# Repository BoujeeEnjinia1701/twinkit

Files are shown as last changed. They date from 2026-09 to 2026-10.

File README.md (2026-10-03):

# TwinKit

     

**Area:** Digital Twins · **TRL:** 3 of 9 (proof of concept on paper) · **Value-engineering target:** about $300 USD · **Difficulty:** 3 of 5

An open digital twin starter kit: a small edge gateway that collects readings from lab sensors (FieldNode and others), plus software that ties live data to each project's build123d model so it can be seen and compared with the design calculations.

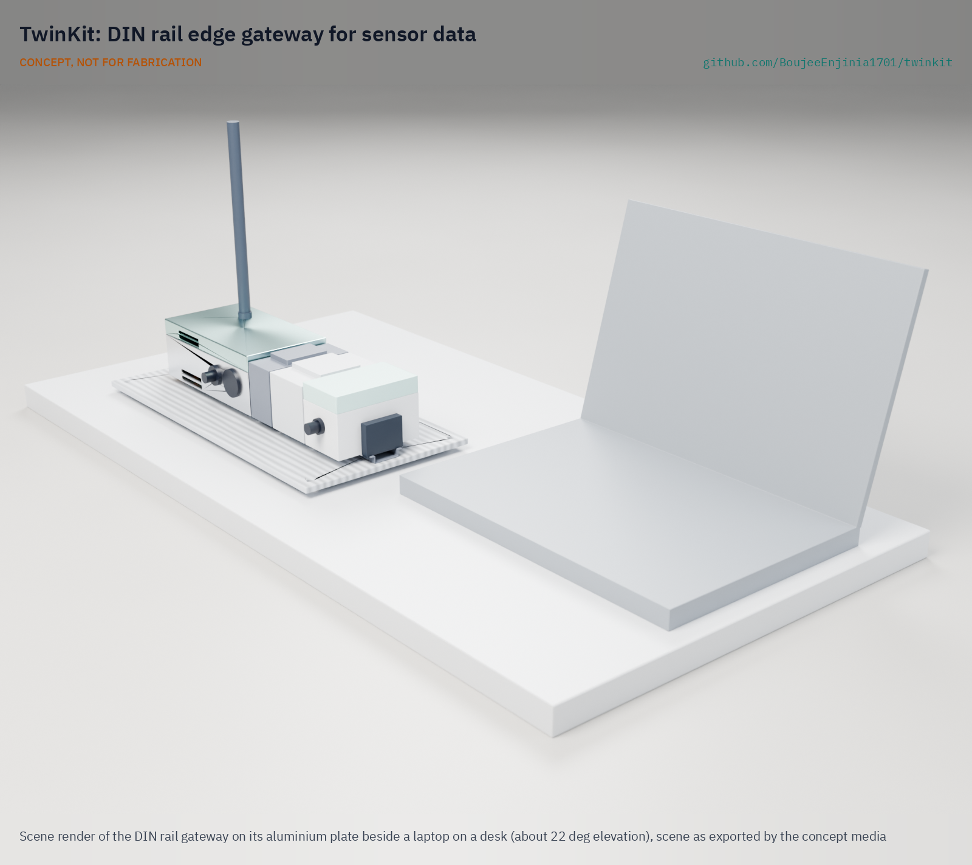
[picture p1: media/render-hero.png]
TwinKit: open digital twin starter kit and edge gateway, photoreal render


[Interactive 3D model](media/viewer.html) · [Concept blueprint (PDF)](media/concept-blueprint.pdf) · [General arrangement (PDF)](cad/drawings/TWK-DWG-001.pdf) · [Sizing calculations](docs/04-calcs/01-sizing.md) · [Prototype build plan](docs/05-build-plan.md) · [Design decisions](docs/06-design-decisions.md) · [Review note](docs/REVIEW.md)

## Concept rationale

Every lab project already has a parametric model and calculated targets. Linking those to live readings closes the loop between design and reality at low cost: instead of alarming on fixed limits, the twin shows where a device departs from what its own calculation predicted, and on which part of the model.

The kit is open and garage-buildable because the pieces already exist as off-the-shelf modules and open-source software. What is missing is the thin mapping layer between sensor channels, model parts and calculations, and a small offline gateway that a small team can assemble on a DIN rail, inspect and adapt.

## Burning platform

Small operators find faults late because they lack the monitoring that large operators take for granted. Water utilities alone lose an estimated 126 billion m³ of treated water a year, worth nearly $40 billion ([World Bank](https://blogs.worldbank.org/en/ppps/what-do-private-companies-look-performance-based-non-revenue-water-project)), and about one in four handpumps in sub-Saharan Africa is out of service at any time ([Foster et al., 2019, via IRC](https://www.ircwash.org/resources/functionality-handpump-water-supplies-review-data-sub-saharan-africa-and-asia-pacific)).

Digital twin platforms are priced for large firms, yet small and medium enterprises make up about 90 % of businesses and more than half of employment worldwide ([World Bank](https://www.worldbank.org/en/topic/smefinance)). An open kit that runs on one small gateway puts the same early-warning idea within their reach.

## Where it could be used

### By industry

| Industry | Use |
| --- | --- |
| Water supply | Compare tank levels, pump run time and flow with the expected demand curve to catch leaks and pump faults early |
| Off-grid energy | Track battery state of charge and solar yield against the design power budget in mini-grids and solar kits |
| Small manufacturing | Watch machine temperature, vibration or energy use against the process calculation |
| Cold chain and storage | Compare cold room or grain store temperatures with the thermal model |
| Education and research | Teach model-based design with a twin students can build and inspect |
| Municipal services | Gateway and data layer for street sensors through CityTwin |

### By country or region

| Country or region | Why it matters there |
| --- | --- |
| Kenya | Water utilities report a national average non-revenue water of 44 % ([WASREB, 2025](https://wasreb.go.ke/wp-content/uploads/2025/06/IMPACT-REPORT-17.pdf)); low-cost monitoring helps find losses |
| Sub-Saharan Africa | About one in four handpumps is non-functional at any time ([Foster et al., 2019](https://www.ircwash.org/resources/functionality-handpump-water-supplies-review-data-sub-saharan-africa-and-asia-pacific)); remote twins can flag failures sooner |
| India | About 63.4 million unincorporated micro, small and medium enterprises in the 2015 to 2016 survey ([PIB, Ministry of MSME](https://www.pib.gov.in/Pressreleaseshare.aspx?PRID=1555596)), most without access to enterprise monitoring tools |
| Brazil | About 37.8 % of treated water was lost in distribution in 2022 ([Instituto Trata Brasil](https://tratabrasil.org.br/wp-content/uploads/2024/06/Release-Perdas-de-Agua-2024.pdf)) |
| European Union | 99 % of the 32.3 million enterprises are micro or small ([Eurostat, 2024](https://ec.europa.eu/eurostat/web/products-eurostat-news/w/ddn-20241025-1)); an open kit suits firms too small for vendor twin platforms |
| Singapore | [Virtual Singapore](https://oecd-opsi.org/innovations/virtual-twin-singapore/) shows the value of a national twin; TwinKit offers a small, open counterpart for campuses, buildings and schools |

## What sparked the idea

The idea traces back to Apollo 13 in April 1970. After an oxygen tank failed, the procedures to bring the crippled command module back to life were worked out on the ground against a model of the spacecraft: NASA's history notes that Ken Mattingly "had spent hours in the CM simulator finalizing the procedures" before the crew ran them ([NASA, 2020](https://www.nasa.gov/history/50-years-ago-apollo-13-crew-returns-safely-to-earth/)). That pairing of a model with the state of the real system, later formalized as the digital twin ([Grieves and Vickers, 2017](https://link.springer.com/chapter/10.1007/978-3-319-38756-7_4)), then needed a room of simulators and a mission control center. TwinKit asks whether the same loop of model, live readings and comparison can run on one DIN rail gateway for a small device, using the model and calculations each project already has.

## Problem

Digital twins are sold as enterprise software, out of reach for small builders and cities, yet the idea is simple: a model, live data and a comparison between them.

## Concept

A DIN rail edge gateway (single-board computer, 8-channel LoRaWAN concentrator, 12 V input and LiFePO4 backup) runs open-source software that receives readings from FieldNode and other sensors, stores a year of data offline, and shows each reading on the project's build123d model next to the value its design calculation predicted. TRL 3 calculations ([TWK-CAL-001](docs/04-calcs/01-sizing.md)): 50 nodes at 5 min with 0.21 % uplink loss using adaptive data rate (target under 1 %), 6.4 W average, 2.4 h of backup, 4.7 GB of data a year, and an estimated USD 334 in parts against a USD 300 value-engineering target. At 40 °C ambient the processor stays about 16 K below its assumed throttle point at normal load; heavy database jobs are scheduled for cool hours. Fourteen of sixteen requirements are met on paper; setup time needs a timed trial, and cost is reported against its target.

Full design precis: [docs/02-concept.md](docs/02-concept.md)

## Key components

- Single-board computer (4 GB) in a vented 9-module DIN rail enclosure
- 8-channel LoRaWAN concentrator HAT and antenna (Wi-Fi and Ethernet built in; cellular optional)
- 12 V DC input (9 to 30 V) with 3.15 A time-delay fuse, DC-DC converter, DIN UPS module with buck-boost charger, and a 12.8 V LiFePO4 backup pack in its own DIN battery box
- Open-source network server, MQTT broker, TimescaleDB and dashboard
- TwinKit twin service and model-to-data mapping schema
- Example twin of FieldNode's battery and solar charge

The priced bill of materials is in [bom/bom.csv](bom/bom.csv). The parametric model is [cad/src/model.py](cad/src/model.py), with STEP and STL exports in `cad/step/` and `cad/stl/`.

## Building the prototype

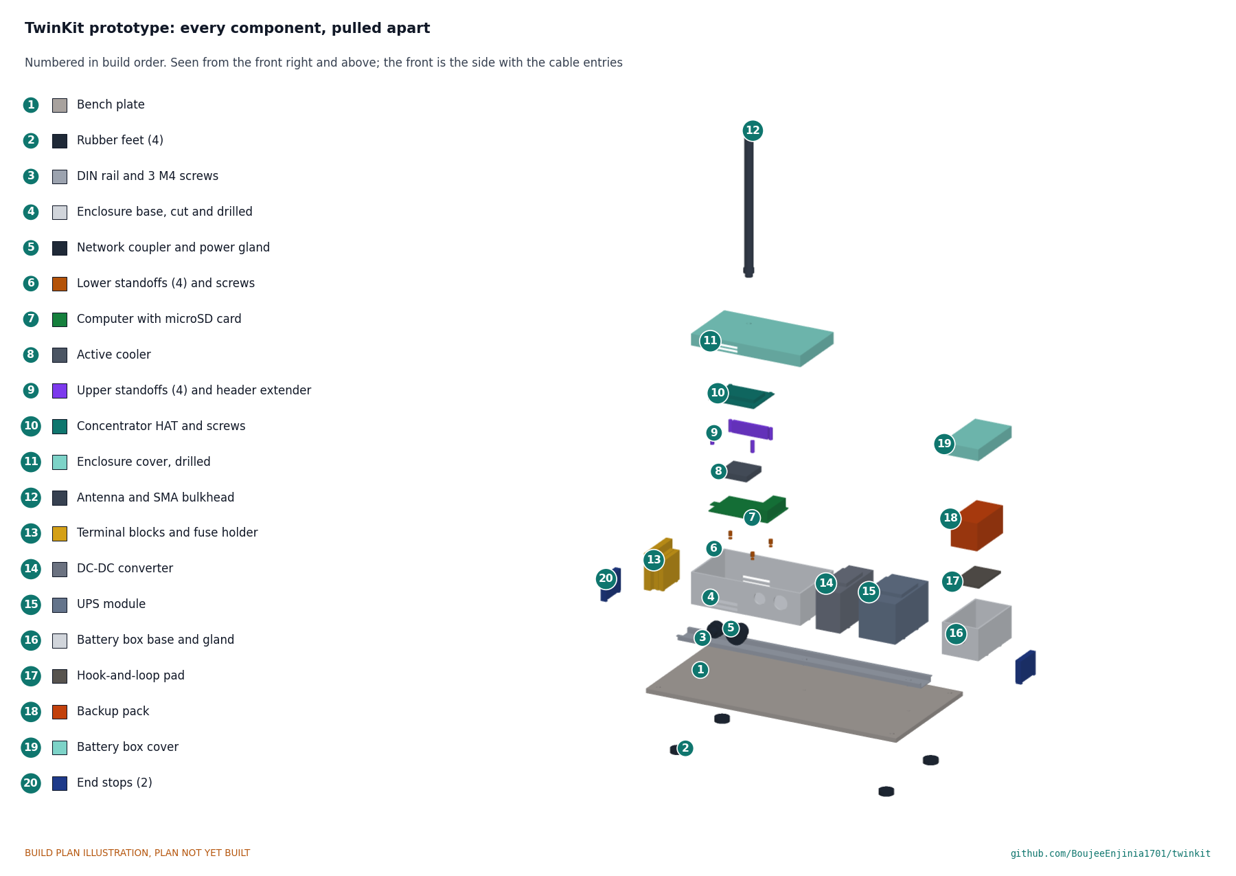
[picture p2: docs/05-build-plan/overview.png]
TwinKit prototype: every component pulled apart and numbered in build order


The [prototype build plan](docs/05-build-plan.md) (TWK-BLD-001) shows, in pictures, how to make each of the twenty components and put them together in seventeen steps; nothing has been built yet. The worked parts are an aluminium bench plate, a cut DIN rail, and three bought DIN enclosures that are cut or drilled; everything else is bought DIN modules, boards and fittings, wired at their screw terminals. Writing the plan made the design buildable: the backup pack moved into its own battery box, the vents moved to the long walls, and standoffs, an antenna bulkhead, cable entries, rail screws and end stops were added (TWK-DDR-003, open for Amish's review). Every picture is drawn from the model, and the model checks that each part touches what it should and clears what it should not.

## Safety

> Low voltage only (12 V DC); use a certified mains adapter. The backup pack is a LiFePO4 battery: use a pack with a built-in BMS and fuse, charge it only through the UPS module and never leave a first build charging unattended. Secure the gateway: change default credentials and keep it off public networks until it is hardened. TwinKit is a monitoring aid, not a safety system.

## Repository layout

| Folder | Contents |
| --- | --- |
| `docs/` | Problem, concept, requirements, calculations and design decisions |
| `cad/src/` | build123d Python source, the source of truth for all geometry |
| `cad/step/`, `cad/stl/` | Exported models for FreeCAD, other CAD tools and printing |
| `cad/drawings/` | 2D sketches and dimensioned drawings |
| `bom/` | Bill of materials |
| `electronics/` | KiCad schematics and PCB layouts |
| `firmware/` | Microcontroller code |
| `media/` | Renders, perspectives and photos |
| `build-log/` | Dated prototyping notes |

## Documentation

Controlled documents follow the portfolio [documentation standard](.kit/STANDARDS.md). Each carries a document ID (TWK-PRC-001 for the precis), a version and a revision history. Branded PDFs are built with `python .kit/render.py` and attached to GitHub Releases when a document is tagged, for example `TWK-PRC-001/v1.0`.

## Credits

Designed by Amish Chadha. See [CONTRIBUTORS.md](CONTRIBUTORS.md) for roles. To cite this design, use [CITATION.cff](CITATION.cff) (GitHub shows it as "Cite this repository").

AI assistance (Claude) was used to accelerate concept renders, prototype documentation and first-pass sizing calculations. Design direction and all decisions are Amish Chadha's, recorded in this repository's decision records (`docs/decisions/`).

## Licenses

- **Hardware** (CAD, drawings, BOM, electronics): [CERN-OHL-S v2](LICENSE)
- **Software** (firmware, scripts, notebooks): [MIT](LICENSE-SOFTWARE)

A project of the [Design Molecule](https://designmolecule.com) lab.

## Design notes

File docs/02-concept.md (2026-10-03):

---
doc_id: TWK-PRC-001
title: TwinKit design precis
project: TwinKit
doc_type: Design precis
version: "0.6"
status: Draft
date: '2026-10-02'
author: Amish Chadha
license: CERN-OHL-S-2.0
revisions:
- version: "0.1"
  date: '2026-09-25'
  author: Amish Chadha
  change: Initial scaffold
- version: "0.2"
  date: '2026-09-25'
  author: Amish Chadha
  change: Populate to TRL 2 (architecture, first-order numbers, safety, media)
- version: "0.3"
  date: '2026-09-25'
  author: Amish Chadha
  change: TRL 3 sizing results from TWK-CAL-001, design choices adopted per TWK-DDR-001, fuse and UPS charger changes
- version: "0.4"
  date: '2026-09-25'
  author: Amish Chadha
  change: Recommendations accepted by Amish (DDR-002). Adaptive data rate and cool-hours job scheduling become design rules; $300 budget
- version: "0.5"
  date: '2026-10-02'
  author: Amish Chadha
  change: "Constructable design (TWK-DDR-003): battery box, vents in the long walls, fittings; cost against the value-engineering target; GA Rev P3; build plan TWK-BLD-001"
- version: "0.6"
  date: '2026-10-02'
  author: Amish Chadha
  change: First build band (US915) and co-design partner from Amish's decisions of 2026-10-02 (TWK-DEC-001)
---

# TwinKit design precis

TwinKit is a small DIN rail edge gateway plus open software that receives sensor readings, stores them, and shows each reading on the project's own build123d model next to the value the design calculation predicted. The TRL 3 calculations (TWK-CAL-001) show one single-board computer with a LoRaWAN concentrator serving 50 sensor nodes, storing a year of data in 4.7 GB and riding through a 2.4 h outage on 6.4 W. With adaptive data rate, uplink loss is 0.21 % against 1 % (R1), and the constructable design costs USD 334 in parts against a USD 300 value-engineering target, USD 34 over (R14). The processor stays 15.9 K below its assumed throttle point at 40 °C and light load, with heavy jobs moved to cool hours (R12). The design choices below were proposed at TRL 2 and decided by Amish on 2026-09-25 (TWK-DDR-001, TWK-DDR-002).

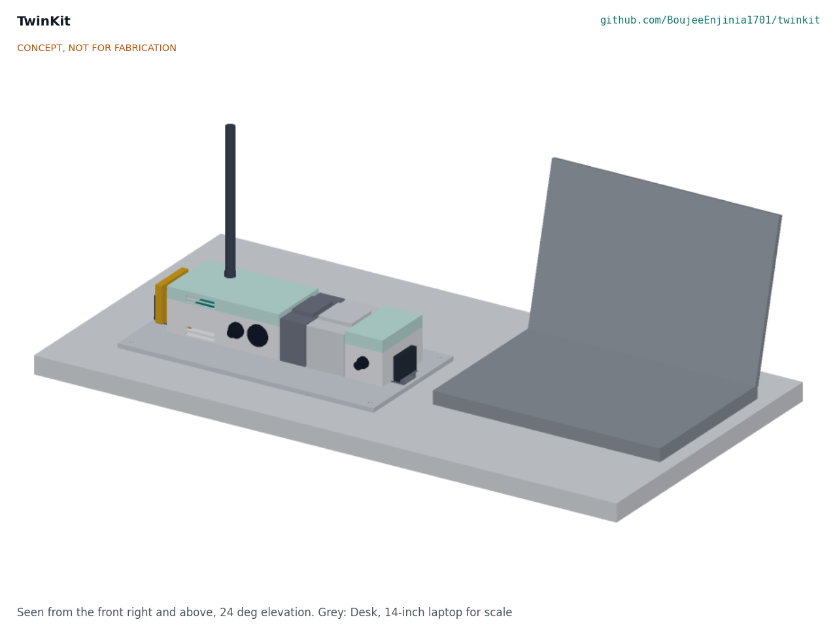
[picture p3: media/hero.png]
Hero render


Figure 1. Gateway on a DIN rail and bench plate, with a desk and 14-inch laptop for scale.

## How it works

1. **Sense.** Sensor nodes such as FieldNode (a sibling lab project) send small readings over LoRa radio. Other devices can post over MQTT or HTTP on the local network.
2. **Receive.** An 8-channel LoRaWAN concentrator on the gateway hears all nodes in range; an open-source network server decodes the packets and publishes them to a local MQTT broker.
3. **Store.** A time-series database on the gateway keeps every reading with its node, channel, unit and time.
4. **Map.** A mapping file for each project (the twin file) links every channel to a named part of the project's build123d model, using the same part names and BOM numbers the concept media already use, and to an expected value: a constant, a curve, or a function from the project's calculation note.
5. **Compare.** The TwinKit twin service computes the residual (measured minus expected) for each reading and raises a flag when it stays outside the stated tolerance for the stated time.
6. **Show.** A browser dashboard shows trends and flags, and a 3D view loads the project's `model.glb` and colors each mapped part by its live value or residual.

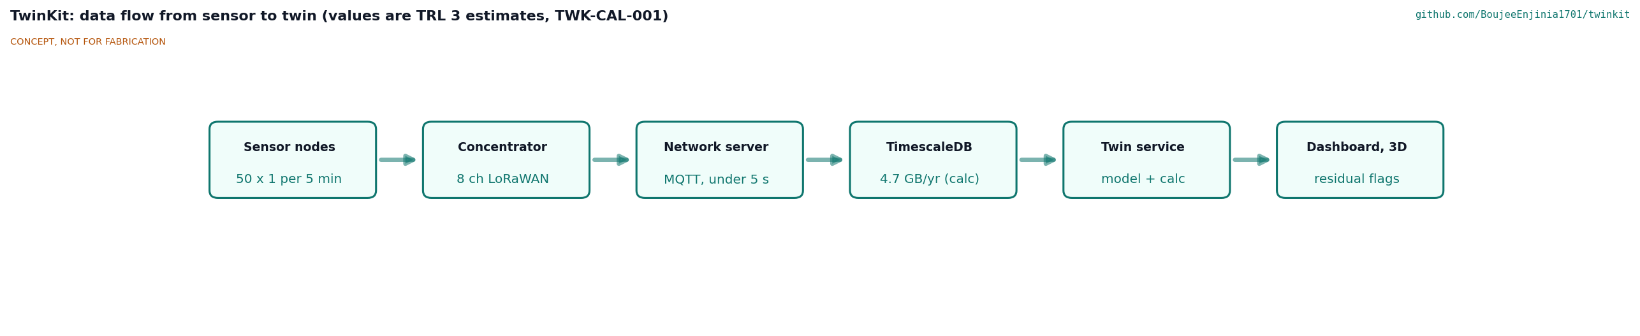
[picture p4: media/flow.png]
Data flow


Figure 2. Data flow from sensor to twin. Values are estimates.

An illustrative twin file for the first example (FieldNode) reads:

```yaml
project: fieldnode
model: media/model.glb
channels:
  - id: battery_v
    node: fieldnode-01
    part: 4            # BOM number of the LiFePO4 cell in FieldNode's model
    unit: V
    expected: calc.power_budget.soc_to_voltage   # from FieldNode's calculation note
    tolerance: 0.1
    hold: 30 min
```

The schema fields (project, model, and per channel an id, node, part, unit, expected value, tolerance and hold time) were decided by Amish on 2026-09-25 (TWK-DDR-002). The hold time sets how fast a fault is flagged: with a 30 min hold, a step fault is flagged within 35 min at 5 min readings (TWK-CAL-001 [C2]). The twin service commits readings in batches every 10 s to limit card wear (TWK-CAL-001, section B).

Two operating rules follow from Amish's decisions of 2026-09-25 (TWK-DDR-002) and are part of the design:

- **Adaptive data rate on.** The network server runs LoRaWAN adaptive data rate, so each node settles on the fastest spreading factor its link allows (SF7 to SF9 in a lab or building). This keeps collision loss at 0.21 % for 50 nodes at 5 min (TWK-CAL-001 [A6]); with every node at SF9 it would be 1.02 %. FieldNode nodes must accept adaptive data rate commands.
- **Heavy jobs in cool hours.** Database recompression, backups and dashboard rebuilds are scheduled by the twin service for the coolest hours (by default 02:00 to 05:00 local, or when the board temperature is below a set value), so that the processor runs at light load when the room is warm (TWK-CAL-001 [F6]).

## Main components

Table 1. Main components (numbers match `bom/bom.csv` and Figure 3).

| # | Component | Choice | Notes |
| --- | --- | --- | --- |
| 1, 2 | Bench plate and DIN rail | 6 mm aluminium plate on rubber feet; 350 mm TS35 top-hat rail on three M4 screws | Plate optional when an equipment cabinet exists |
| 3, 4 | Gateway enclosure | 9-module DIN enclosure, vented, clear cover | Holds the computer and concentrator |
| 5, 6 | Single-board computer and cooler | 4 GB quad-core Arm board (Raspberry Pi 5 class) | Runs all software; about 2.4 GB used. Decided by Amish, 2026-09-25 (TWK-DDR-002) |
| 7 | LoRaWAN concentrator | SX1302 or SX1303 8-channel HAT | Region version (EU868 or US915). Decided by Amish, 2026-09-25 (TWK-DDR-002); the first build is US915, decided 2026-10-02 (TWK-DEC-001) |
| 8 | Storage | 64 GB high-endurance microSD | SSD upgrade is an option |
| 9 | Antenna | 3 dBi whip on an SMA bulkhead | Mounted on the cover or outside a cabinet; tip 264 mm above the plate |
| 10 | DC-DC converter | 9 to 30 V in, 5.1 V 5 A out | Accepts a 12 V adapter or an existing 12 V system |
| 11, 12, 17 | Backup | 3-module DIN UPS module with a 9 to 30 V buck-boost charger, and a 12.8 V, 1.5 Ah LiFePO4 pack with built-in BMS in its own 3-module battery box | Power-fail signal triggers a clean shutdown. Pack choice decided by Amish, 2026-09-25 (TWK-DDR-002) |
| 13 | Terminals and fuse | DIN terminal blocks, 3.15 A time-delay fuse | Fuse at the supply input; raised from 2 A by TWK-CAL-001 [D3] |
| 18 to 21 | Fittings | Rail end stops, board standoffs and header extender, network feed-through coupler and cable glands, screws, feet and wiring | Added to make the design buildable (TWK-DDR-003) |
| 14 | Open-source stack | LoRaWAN network server, MQTT broker, TimescaleDB, dashboard | All open source, no cloud account. Decided by Amish, 2026-09-25 (TWK-DDR-002) |
| 15 | Twin service and schema | Python service and YAML twin file | TwinKit's own code, MIT |
| 16 | Example twin | FieldNode battery and solar charge | Decided by Amish, 2026-09-25 (TWK-DDR-002) |

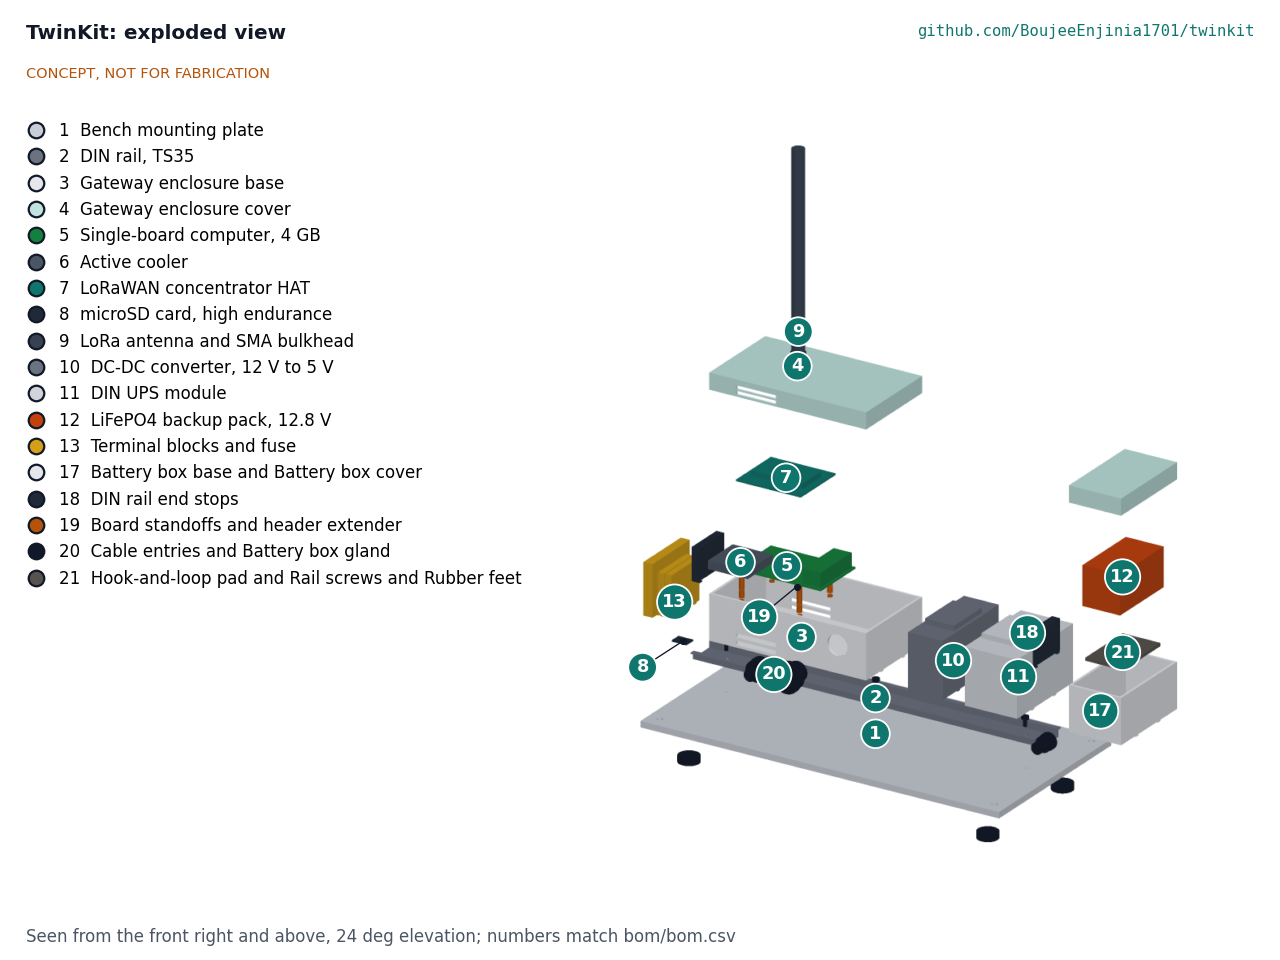
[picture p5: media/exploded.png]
Exploded view


Figure 3. Exploded view with BOM numbers.

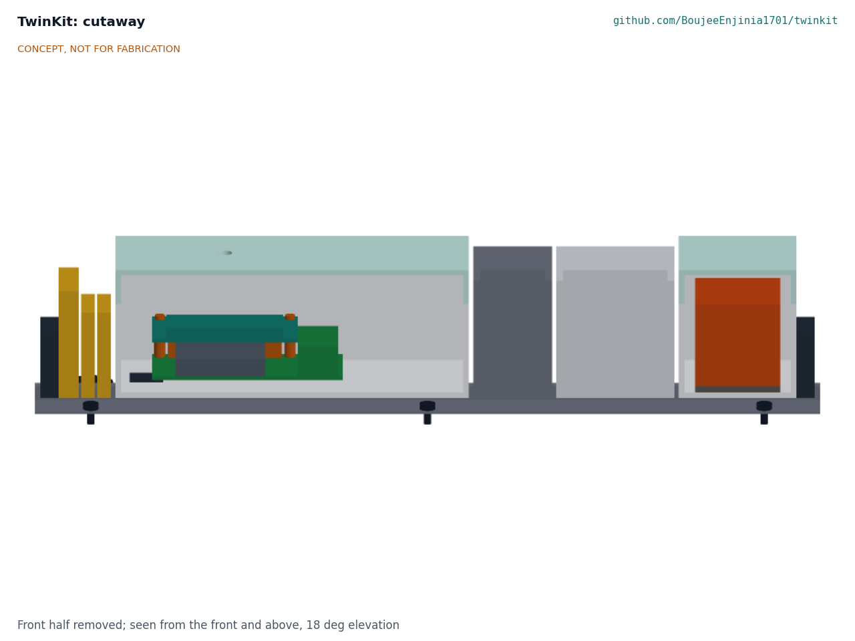
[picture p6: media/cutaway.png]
Cutaway


Figure 4. Cutaway through the terminals (left), gateway enclosure, converter, UPS module and the battery box with the backup pack (right).

## Sizing results

The values below are from the TRL 3 calculation note TWK-CAL-001, which replaces the TRL 2 first-order estimates; tags in brackets point to lines of `docs/04-calcs/sizing.py`.

Table 2. Sizing results (TWK-CAL-001).

| Quantity | Value | Basis | Requirement |
| --- | --- | --- | --- |
| Uplinks handled | 600 per hour, 75 per channel [A1] | 50 nodes x 12 readings per hour over 8 channels | R1 |
| Time on air, 20-byte reading | 71.9 ms at SF7, 246.8 ms at SF9, 1810.4 ms at SF12 [A2] | Semtech formula, 13 bytes of LoRaWAN overhead | R1 |
| Uplink loss from collisions | 0.30 % at SF7, 1.02 % at SF9, 7.27 % at SF12; 0.21 % for an SF7 to SF9 mix [A2, A3] | Pure ALOHA, all nodes on one spreading factor | R1 met with adaptive data rate (0.21 %) [A6] |
| Storage per year | 4.73 GB uncompressed, 0.55 GB compressed [B1] | 52.6 million values at 90 bytes | R3 met (56 GB free) |
| Card writes | 35 to 53 GB per year, 5.5 to 8.2 card cycles [B4] | Write-ahead log per commit, assumed card amplification 10 | R3, wear to watch |
| Reading to dashboard | 0.9 to 4.7 s [C1] | Stage-by-stage latency budget | R5 met (60 s) |
| Average power | 6.41 W, 0.53 A at 12 V [D1] | Board 4 W, fan 0.5 W, concentrator 1 W, converter 90 %, UPS 0.3 W | R8 met (8 W) |
| Peak input | 20.6 W, 2.29 A at 9 V [D2] | Full load, downlink and pack charging | Fuse 3.15 A T [D3] |
| Backup time | 2.40 h new, 1.63 h aged at 0 °C [E1] | 15.36 Wh usable at 6.41 W | R9 met (30 min) |
| Processor at 40 °C ambient | 69.1 °C light load, 96.9 °C sustained full load, vented [F2] | 5 W/m²K, 640 mm² vents 42 mm apart, 4 K/W with fan | R12 met at light load; heavy jobs in cool hours [F6] |
| Memory | about 2.42 GB of 4 GB [G1] | Stack budget | Supports the 4 GB board |
| Rail length used | 331 mm, 18.9 modules; 345 mm with end stops on a 350 mm rail [H1] | From `cad/src/model.py` | R10 met (350 mm) |
| Parts cost | $334.00 [I1] | Priced `bom/bom.csv`, indicative | R14: USD 34 over the USD 300 value-engineering target |

Thermal is still the main technical uncertainty. At light load the processor stays about 16 K below its throttle point at 40 °C, but a sustained heavy job would throttle, and doubling the vents barely helps (TWK-CAL-001 [F5]). Heavy database jobs therefore run in cool hours by design. A larger or metal enclosure is the hardware fallback if TRL 4 tests (on hold) show throttling.

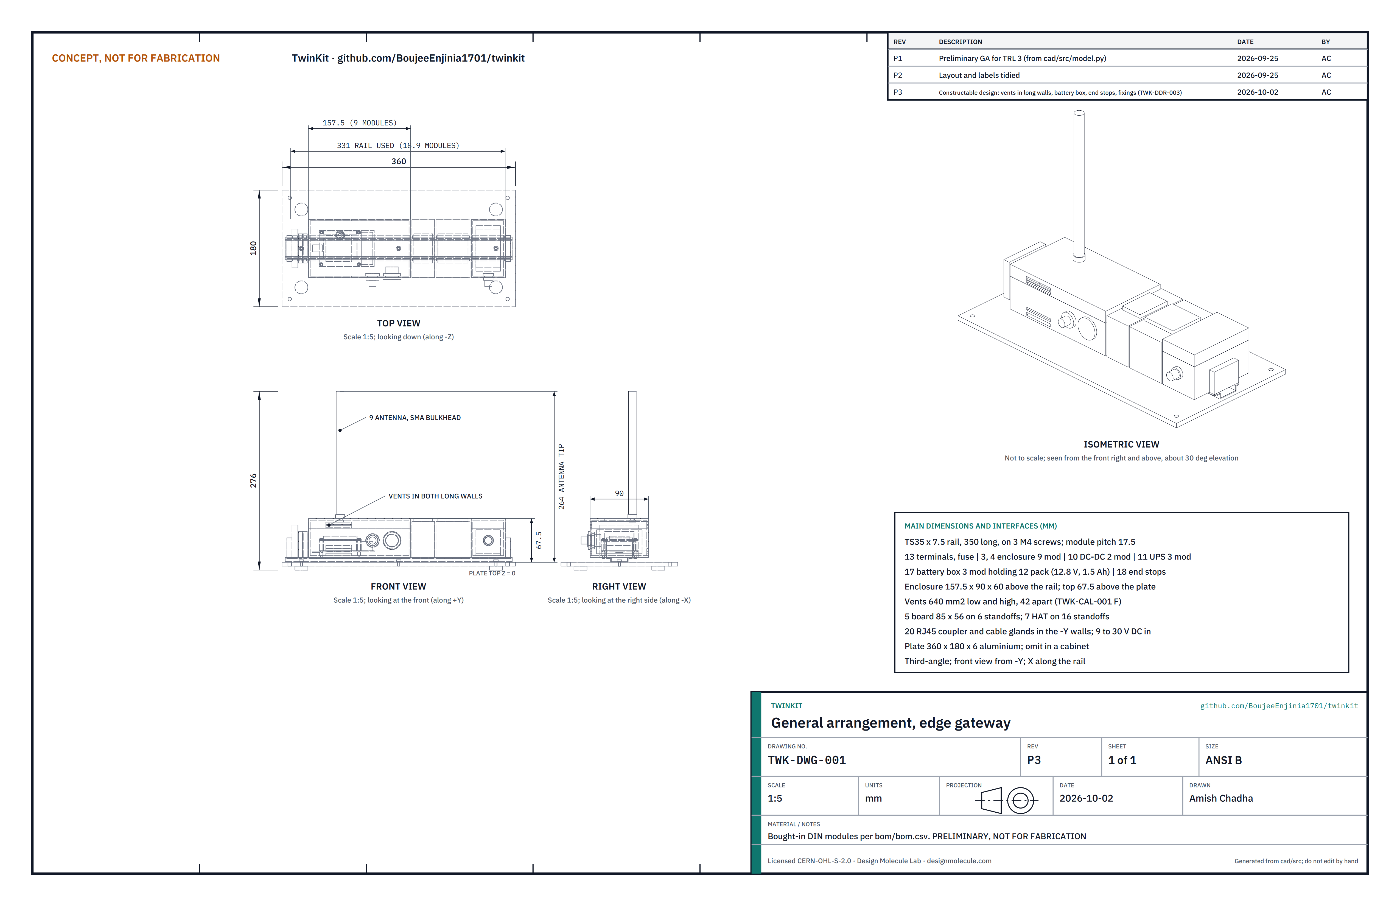
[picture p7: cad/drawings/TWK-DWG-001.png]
General arrangement


Figure 5. General arrangement TWK-DWG-001 Rev P3, generated from the parametric model `cad/src/model.py` ([PDF](../cad/drawings/TWK-DWG-001.pdf)). Preliminary, not for fabrication.

## Constructable design

The model is now constructable (TWK-DDR-003, open for Amish's review): every part can be bought or made with a saw, drill, tap and file, and every part is held by the part next to it. The backup pack moved out of the UPS module into its own 3-module battery box, the enclosure vents moved from the end walls (which face the neighbouring modules 2 mm away) to the long walls with the same area, the boards sit on standoffs, the network and power leads enter through a coupler and a gland in the front wall, and the rail is a true top-hat section screwed to an aluminium plate with an end stop at each end. The illustrated prototype build plan is [TWK-BLD-001](05-build-plan.md); open decisions and purchase checks are in the design decisions register [TWK-DEC-001](06-design-decisions.md).

## Key design choices

- **Compare with the calculation, not only with thresholds.** Most dashboards alarm on fixed limits. TwinKit compares each reading with what the design said it should be at that moment, so a battery that charges more slowly than the power budget predicted is caught before it goes flat.
- **Reuse the portfolio's own model outputs.** Every lab repo already exports a `model.glb` with named, BOM-numbered parts. The twin file points at those names, so no separate 3D model is built for the twin.
- **Edge first.** Everything runs on the gateway. An upstream server is optional, which keeps the kit usable where connectivity is poor and keeps data with its owner.
- **LoRaWAN rather than a single-channel receiver.** An 8-channel concentrator follows the open standard, matches FieldNode's LoRaWAN radio and accepts third-party sensors, at about $55 more than a point-to-point receiver. Decided by Amish, 2026-09-25 (TWK-DDR-002).
- **Lightweight stack over a twin platform.** Frameworks such as Eclipse Ditto assume a server cluster; a single-board computer running a network server, MQTT, TimescaleDB and a small Python service fits in about 2.4 GB of 4 GB (TWK-CAL-001 [G1]). Decided by Amish, 2026-09-25 (TWK-DDR-002).
- **Monitoring only.** No control outputs, so a software fault cannot move a pump or switch a load.

## Relation to other lab projects

- **FieldNode** is the primary data source and the first example twin, decided by Amish on 2026-09-25. Its nodes must accept LoRaWAN adaptive data rate commands (recorded as a cross-repo action in `docs/REVIEW.md`). FieldNode sends 20-byte LoRaWAN uplinks every 15 min by default; TwinKit is sized for 5 min, which is conservative.
- **CityTwin** builds its public map and kiosk on TwinKit's gateway and software. Its review recommends costing the gateway here, in TwinKit. A gateway in a sealed street cabinet in sun is hotter than the 40 °C case sized here.
- **CellGuard** could protect a larger backup pack in a later version; at this size an off-the-shelf pack with a built-in BMS was decided by Amish on 2026-09-25.
- **CalRig** calibration records could feed each channel's tolerance in the twin file.

## Safety

> **Safety:** The backup pack is a lithium (LiFePO4) battery. Use a pack with a built-in BMS and fuse, charge it only through the UPS module within the maker's limits, keep it away from heat, and never leave a first build charging unattended.

> **Safety:** The gateway runs from 12 V DC. Use a certified, double-insulated mains adapter; any wiring to an existing 12 V system or into a mains cabinet must be done or checked by a qualified electrician under local code.

> **Safety:** A network gateway is an attack surface. Change every default credential, keep it off the public internet until it is hardened, apply updates, and treat sensor data as the owner's data.

> **Safety:** TwinKit is a monitoring aid. It must not be relied on as a safety system, and it does not replace alarms, protection devices or inspections that a regulation or the equipment maker requires.

## Open questions after TRL 3

All open decisions are kept in the design decisions register ([TWK-DEC-001](06-design-decisions.md)).

- Co-design partner outside the lab. Decided by Amish, 2026-10-02 (TWK-DEC-001): the first candidate to approach is a small municipal water utility in the Dallas and Fort Worth area, found through the Texas Water Utilities Association, with Dallas Makerspace as the build and test partner.
- Processor temperature, card endurance and the power figures are assumptions that only measurement can settle.

Concept media: [blueprint sheet](../media/concept-blueprint.pdf), [interactive 3D model](../media/viewer.html).

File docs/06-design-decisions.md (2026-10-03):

---
doc_id: TWK-DEC-001
title: TwinKit design decisions register
project: TwinKit
doc_type: Design decisions register
version: "0.2"
status: Draft
date: '2026-10-02'
author: Amish Chadha
license: CERN-OHL-S-2.0
revisions:
  - version: "0.1"
    date: '2026-10-02'
    author: Amish Chadha
    change: Register opened with the open decisions, purchase checks and value engineering from the constructable design (TWK-DDR-003)
  - version: "0.2"
    date: '2026-10-02'
    author: Amish Chadha
    change: Amish approved the recommendations for open items 1 to 3 on 2026-10-02 (TWK-DDR-003 accepted, US915 first build, first candidate partner); moved to decisions made
---

# TwinKit design decisions register

Every design decision still to be made, and every decision made, in one place. Each decision is argued in full in its decision record under `docs/decisions/`; this register is the index Amish works from. The build plan (`docs/05-build-plan.md`, TWK-BLD-001) describes the design as it stands and does not list open decisions.

## Open decisions

None. All open decisions were decided on 2026-10-02.

## To confirm when parts are bought

| # | What to confirm | Why it matters | Source |
| --- | --- | --- | --- |
| 1 | The 9-module enclosure: whether it has moulded bosses for the computer, moulded vents, a flat front wall where the 20 mm and 16.2 mm holes go, and how its cover is held | Sets whether the floor holes and vent slots are cut or already there (build plan section 3.3) | TWK-DDR-003, P2, P3, P5 |
| 2 | The concentrator HAT passes the 40-pin header through, or names free GPIO and ground pins, and sits on the computer's 58 x 49 hole pattern | The power-fail pair connects there; the 16 mm standoffs and header extender assume that pattern and height | TWK-DDR-003, P3, P9 |
| 3 | The active cooler is no taller than 8 mm above the board | It must clear the HAT on 16 mm standoffs | TWK-DDR-003, P3 |
| 4 | The UPS module: 3 modules wide, no internal battery, a LiFePO4 setting at 14.6 V and 0.5 A or less, a 0 to 45 °C charge window, and a power-fail output that is a dry contact or open collector | Width sets the rail length; the output type decides whether the pair can go straight to a GPIO pin (safety stop S3) | `bom/bom.csv` line 11; TWK-DDR-003, P1, P9 |
| 5 | The backup pack is no larger than 38 x 70 x 38 mm with a lead of about 300 mm and its own BMS and fuse | It must fit the 3-module battery box with 3.5 mm to the gland nut | `bom/bom.csv` line 12; TWK-DDR-003, P1 |
| 6 | The DC-DC converter is 2 modules wide | Sets the rail length (345 mm of 350 mm used with end stops) | `bom/bom.csv` line 10 |
| 7 | The computer runs from the converter's 5.1 V through its USB-C socket without power negotiation | It then limits its USB sockets to low power, which the gateway does not use; if it refuses to boot, power it through its header pins instead | TWK-DDR-003, P9 |
| 8 | The network coupler's panel hole (20 mm assumed) and the rail's factory slot positions | Hole sizes in build plan sections 3.2 and 3.3 | TWK-DDR-003, P5, P6 |

## Value engineering

Value-engineering target: USD 300 (a hypothetical control target, not a limit). Estimated cost of the constructable design: USD 334 (USD 34 over the target). Main cost drivers and savings worth trying:

- The largest lines are the concentrator HAT (USD 80), the computer (USD 65), the UPS module (USD 30), the backup pack (USD 25), the gateway enclosure and the DC-DC converter (USD 18 each) and the aluminium plate (USD 15).
- Making the design constructable added USD 44 against the concept's USD 290: the battery box (USD 8), end stops (USD 3), board mounting kit (USD 5), cable entries (USD 10), fixings and wiring (USD 9) and the aluminium plate in place of plywood (USD 9 more).
- Savings worth trying: a 9 mm plywood plate with threaded inserts in place of tapped aluminium (about USD 6 saved); an enclosure that already has bosses and vents for the computer (saves the standoff kit, about USD 3, and the cutting time); a DIN UPS module with a built-in LiFePO4 pack, if one meeting line 11 exists, which would remove the battery box (about USD 8); and a single supplier for the computer, cooler, card and standoffs. None of these changes what the gateway does.

## Decisions made

| Date | Decision | Decided by | Record |
| --- | --- | --- | --- |
| 2026-09-25 | TRL 2 items D1 to D7: 8-channel LoRaWAN concentrator, 4 GB Pi 5 class computer, TimescaleDB, lightweight open-source stack with a TwinKit twin service, FieldNode battery and solar charge as the first example twin, the YAML twin file fields, an off-the-shelf LiFePO4 pack with built-in BMS | Amish: "i accept all your recommendations, go with them across all repos." | TWK-DDR-001, TWK-DDR-002 |
| 2026-09-25 | Budget raised from USD 200 to USD 300 to keep LoRaWAN compatibility (O1) | Amish, same instruction | TWK-DDR-002 |
| 2026-09-25 | R1 judged with adaptive data rate required (N1); R12 defined at light load with heavy jobs in cool hours, a larger or metal enclosure as the fallback (N2) | Amish, same instruction | TWK-DDR-002 |
| 2026-10-01 | `budget_usd` is a value-engineering target, not a spending limit | Amish: "the budgets are a hypothethical control target to ensure we are thinking along a value engineering lens. its ok to ensure wording reflects that the hypothesis budget was x - the real cost being accrued is y" | `.kit/STANDARDS.md` section 18 |
| 2026-10-02 | Design for construction accepted: the changes P1 to P9 of TWK-DDR-003, as made | Amish: "APPROVED: The open decisions from the last wave (TremorTrace to ZeerBox) came in after the review and aren't on the page either." | TWK-DDR-003 |
| 2026-10-02 | Region and radio band of the first build: US915, with the US915 concentrator HAT and a 915 MHz antenna, to match FieldNode's decided first variant | Amish: "APPROVED: The open decisions from the last wave (TremorTrace to ZeerBox) came in after the review and aren't on the page either." | `bom/bom.csv` line 7; FND-DDR-001, O1 |
| 2026-10-02 | Co-design partner outside the lab: the first candidate to approach for the operator view is a small municipal water utility in the Dallas and Fort Worth area, found through the Texas Water Utilities Association, with Dallas Makerspace as the build and test partner | Amish: "APPROVED: The open decisions from the last wave (TremorTrace to ZeerBox) came in after the review and aren't on the page either." | TWK-DDR-002, O2 |

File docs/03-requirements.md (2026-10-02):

---
doc_id: TWK-REQ-001
title: TwinKit requirements
project: TwinKit
doc_type: Requirements
version: "0.5"
status: Draft
date: '2026-10-02'
author: Amish Chadha
license: CERN-OHL-S-2.0
revisions:
- version: "0.1"
  date: '2026-09-25'
  author: Amish Chadha
  change: Initial scaffold
- version: "0.2"
  date: '2026-09-25'
  author: Amish Chadha
  change: First measurable requirements for TRL 2
- version: "0.3"
  date: '2026-09-25'
  author: Amish Chadha
  change: Status from the TRL 3 calculations (TWK-CAL-001); R1 found not met at SF9; decisions per TWK-DDR-001
- version: "0.4"
  date: '2026-09-25'
  author: Amish Chadha
  change: Recommendations accepted by Amish (DDR-002). R1 restated with adaptive data rate, R12 restated at light load, R14 target raised to $300
- version: "0.5"
  date: '2026-10-02'
  author: Amish Chadha
  change: "Constructable design (TWK-DDR-003): R10 with the battery box and end stops; R14 reported against the value-engineering target"
---

# TwinKit requirements

Status is judged from the TRL 3 calculation note TWK-CAL-001 v0.3 and the constructable model of TWK-DDR-003. No requirement is shown as not met or at risk; R13 (setup time) can only be shown by a timed trial. At v0.5, R14 is reported against its value-engineering target (Amish, 2026-10-01: the budget is "a hypothethical control target"): the constructable design is USD 34 over it. R10 still holds with the battery box and end stops added. Three requirements were changed at this revision by Amish's decisions of 2026-09-25 (TWK-DDR-002): R1 now requires adaptive data rate (was: under 1 % at SF7 to SF9, which failed at 1.02 % with every node on SF9); R12 now applies at the normal light load, with heavy jobs scheduled for cool hours (was: at any load, at risk); and R14's parts limit rises from $200 to $300 (was not met at $290).

Table 1. Requirements.

| ID | Requirement | Target | Status at TRL 3 (TWK-CAL-001) | Verification (TRL 4 or later) |
| --- | --- | --- | --- | --- |
| R1 | Receive readings from lab sensor nodes | 50 nodes at 1 reading per 5 min each, under 1 % of uplinks lost, with adaptive data rate enabled on the network server so each node uses the fastest spreading factor (SF7 to SF9) its link allows | Met: 0.21 % for an SF7 to SF9 mix [A3, A6]; for information, 1.02 % if all nodes were forced to SF9 [A2] | Bench and field packet counts |
| R2 | Accept common inputs | LoRaWAN (EU868 or US915), MQTT over Ethernet or Wi-Fi, HTTP POST | Met by design | Configuration check |
| R3 | Store history on the gateway | 1 year for 50 nodes x 10 fields at 5 min intervals | Met: 4.73 GB per year uncompressed on 56 GB free [B1, B2]; card wear 5.5 to 8.2 card cycles per year, to watch [B4] | Measured database size |
| R4 | Link data to the model | Every sensor channel mapped to a named part (BOM number) of the project's build123d model and to an expected value or calculation, in a validated schema | Met by design (schema fields adopted, TWK-DDR-001) | Schema review on the FieldNode example twin |
| R5 | Compare measured and expected | Residual and pass or flag state shown within 60 s of a reading arriving; flag when outside a stated tolerance for a stated time | Met: 0.9 to 4.7 s [C1] | Bench run |
| R6 | Show the twin in 3D | The project's glTF model, colored by live values, in a current browser on a mid-range laptop or phone | Met by design; frame rate not verifiable at TRL 3 | Browser trial |
| R7 | Work offline | All functions run with no internet; optional upstream sync buffers at least 7 days | Met by design; 7-day buffer 91 MB [B3] | Offline run |
| R8 | Low-voltage power | 9 to 30 V DC input, 12 V nominal; average draw 8 W or less | Met: 6.41 W average; 20.6 W peak, 2.29 A at 9 V, 3.15 A T fuse [D1 to D3] | Power measurement |
| R9 | Ride through outages | At least 30 min on backup and a clean shutdown before the pack is empty | Met: 2.40 h new, 1.63 h aged pack at 0 °C [E1] | Timed outage |
| R10 | Compact mounting | Fits a TS35 DIN rail; gateway, converter and backup within 20 modules (350 mm) of rail | Met: 331 mm, 18.9 modules; 345 mm with the end stops on a 350 mm rail [H1] | Fit check |
| R11 | Secure by default | Unique credentials set at first boot, TLS on the dashboard, no ports open beyond the local network by default | Met by design | Configuration audit |
| R12 | Operate in a lab or equipment room | Ambient 0 to 40 °C without CPU throttling at the normal light load; heavy jobs (database recompression, backups, rebuilds) scheduled for cool hours | Met: processor 69.1 °C at light load, vented, 15.9 K below an assumed 85 °C throttle point [F6]; 96.9 °C if a heavy job ran at 40 °C [F2] | Thermal test at 40 °C |
| R13 | Quick setup | From a flashed card to the first live reading on the dashboard in 60 min or less, following the guide | Not verifiable at TRL 3 | Timed trial |
| R14 | Low cost and buildable | Parts cost against a USD 300 value-engineering target (raised from $200, TWK-DDR-002; a control target, not a limit); no custom PCB | USD 334.00, USD 34 over the target [I1, I2]; no custom PCB | Supplier quotes |
| R15 | Open and exportable | All software open source; data exportable as CSV and through an open API | Met by design | Design review |
| R16 | Monitoring only | No control outputs; the gateway cannot actuate the monitored system | Met by design | Design review |

## Assumptions

The assumptions behind each status are listed in TWK-CAL-001, Table 1. The main ones are:

- A sensor reading is a LoRaWAN uplink of 20 bytes of payload plus 13 bytes of overhead, at 125 kHz and coding rate 4/5 (71.9 ms at SF7, 246.8 ms at SF9, 1810.4 ms at SF12).
- Uplinks spread evenly over 8 channels and arrive at random (pure ALOHA), with no capture effect.
- A stored value takes 90 bytes including index overhead, before compression.
- The gateway draws 6.41 W on average: board 4 W, fan 0.5 W, concentrator 1 W, converter at 90 % and UPS loss 0.3 W.
- The backup pack delivers 80 % of its 19.2 Wh rating when new.
- The processor throttles at 85 °C and sits 4 K/W above the enclosure air with its fan running; both are assumptions to be measured.

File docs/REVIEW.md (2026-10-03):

# Review note: TwinKit

## Session 2026-09-25: /populate to a strong TRL 2

### What was done

- `docs/01-problem.md` (TWK-PRB-001 v0.2): problem with cited figures, prior work (Grieves and Vickers, ISO 23247, Eclipse Ditto, Virtual Singapore), users and context, constraints, out of scope, open questions.
- `docs/03-requirements.md` (TWK-REQ-001 v0.2): 16 measurable requirements (R1 to R16) with targets, status and planned verification.
- `docs/02-concept.md` (TWK-PRC-001 v0.2): how it works, main components, first-order numbers with assumptions, design choices, relation to FieldNode, CityTwin, CellGuard and CalRig, safety, open questions.
- `cad/src/concept_media.py`: massing model of the DIN rail gateway (13 BOM-numbered parts) with a desk and 14-inch laptop for scale, since the gateway is too small to read beside a 1.75 m figure.
- `media/`: `hero.png`, `concept-blueprint.png`/`.pdf`/`.svg`, `exploded.png`, `cutaway.png`, `flow.png` (data flow, values marked as estimates), `model.glb` and `viewer.html`.
- `bom/bom.csv`: 16 rows with indicative USD costs; rows 1 to 13 match the exploded view. `bom/bom-notes.md` updated.
- `README.md`: hero, links line, concept rationale, burning platform, use tables by industry and region, origin, concept, components and safety updated.
- `docs/pdf/`: branded PDFs of the three controlled documents.
- `project.yaml`: unchanged. The pitch and problem remain accurate.

### Key results (estimates, to be checked at TRL 3)

| Quantity | Estimate | Requirement |
| --- | --- | --- |
| Nodes served | 50 at 1 reading per 5 min, under 0.3 % loss at SF7 | R1 met |
| Storage | about 1.6 GB per year on a 64 GB card | R3 met |
| Reading to dashboard | under 5 s | R5 met |
| Average power | about 6 W at 12 V | R8 met |
| Backup | about 2 h | R9 met |
| Enclosure air rise | about 20 K above ambient | R12 not yet shown |
| Parts cost | about $285 | R14 **not met** ($200) |

Requirements not met or not shown: R14 (cost, about $285 against $200), R12 (thermal margin at 40 °C ambient, not yet shown), R13 (60 min setup, can only be shown by a timed trial at TRL 4).

### Proposed, awaiting Amish

Update 2026-09-25: items 1 to 8 are now **Decided by Amish, 2026-09-25: go with recommendation** (TWK-DDR-002). Item 9 had no recommendation and stays Proposed, awaiting Amish.

1. **Budget.** Parts cost about $285 against `budget_usd: 200`. Options: (a) raise the budget to $300; (b) keep $200 with a "lite" gateway using a point-to-point LoRa USB receiver instead of the LoRaWAN concentrator and a UPS HAT instead of the DIN UPS and pack (about $197, but no third-party LoRaWAN sensors); (c) keep $200 and drop the backup (about $235, still over). Recommendation: (a), because LoRaWAN compatibility is what lets CityTwin and third-party sensors use the kit.
2. **Radio.** 8-channel LoRaWAN concentrator (recommended) or point-to-point LoRa receiver. Must match FieldNode's radio choice.
3. **Computer.** 4 GB Raspberry Pi 5 class board (recommended) or a 2 GB board to save cost (tighter memory for the database).
4. **Database.** TimescaleDB (recommended, SQL and compression), InfluxDB, or SQLite (lightest).
5. **Twin platform.** Lightweight stack plus a small TwinKit service (recommended) or Eclipse Ditto (richer, heavier).
6. **First example twin.** FieldNode battery and solar charge (recommended), WaterWatch, or ThermaBrick.
7. **Twin file schema.** The YAML fields sketched in the precis (part by BOM number, expected value from the calculation note, tolerance, hold time).
8. **Backup pack.** Off-the-shelf 12.8 V LiFePO4 pack with built-in BMS (recommended) or a CellGuard-protected pack later.
9. **Co-design partner** outside the lab: a small water utility, a makerspace or a municipal team.

### Safety concerns

- LiFePO4 backup pack: use a pack with a built-in BMS and fuse; charge only through the UPS module.
- 12 V supply: certified mains adapter; any cabinet or mains-side wiring by a qualified electrician.
- Cybersecurity: default credentials, open ports and unpatched software are the main real-world risk for an edge gateway.
- Over-reliance: the twin is a monitoring aid and must not replace required alarms or protection.
- Thermal: a closed enclosure at 40 °C ambient may throttle the computer; not a fire risk at 6 W, but a reliability risk.

### Gaps against the brief

- The Pi and concentrator prices are indicative retail figures, not supplier quotes.
- `flow.png` shows the data path without loss branches, because the kit's loss arrows scale against numeric stage values and this flow uses text labels; uplink loss is given in the precis instead.

### Recommended next step

Review this note and the media, and decide the budget and radio questions first, since both change the BOM. If approved, run `/advance-trl3` to write the calculation note (airtime and loss, storage and card wear, power and backup, enclosure thermal check), a working build123d model with STEP export, a drawing sheet and a fully priced BOM.

## Session 2026-09-25: TRL 3

On 2026-09-25 Amish asked for this batch of repos to be taken through the usual process with the instruction "you know the drill, nothing gets past TRL 3". He has not reviewed this repo's TRL 2 items one by one. This session ran `/advance-trl3` on that instruction and stopped at TRL 3.

### What was done

- `docs/decisions/0001-trl2-review-decisions.md` (TWK-DDR-001 v0.1, status proposed): seven recommendations adopted as recommended for TRL 3 under Amish's 2026-09-25 instruction, open for his review (D1 to D7), and two items left open (O1 budget, O2 co-design partner).
- `docs/04-calcs/01-sizing.md` (TWK-CAL-001 v0.1) and `docs/04-calcs/sizing.py`: LoRa airtime and ALOHA collision loss, storage and card wear, latency and flag timing, power, peak current and fuse, backup, enclosure and processor temperature, memory, rail length and cost, with a status for every requirement. The script imports the model's parameters and reads the BOM and `project.yaml`; every number in the note is printed by it with a tag.
- `cad/src/model.py`: parametric build123d model (plate, TS35 rail, 9-module enclosure base and cover with end vents, board, cooler, concentrator HAT, card, antenna on a bulkhead, DC-DC converter, UPS module with pack, terminals and fuse). Exports `cad/step/` and `cad/stl/` for `twinkit-assembly` and `gateway-enclosure`.
- `cad/src/sheets.py` and `cad/drawings/TWK-DWG-001.svg`, `.pdf`, `.png`: general arrangement at Rev P1, 1:5, marked "CONCEPT, NOT FOR FABRICATION" and "PRELIMINARY, NOT FOR FABRICATION". TWK-DWG-001 was free because the concept blueprint is TWK-DWG-010.
- `bom/bom.csv` (16 lines, all priced with a supplier type, $290.00) and `bom/bom-notes.md`.
- `cad/src/concept_media.py` now builds from the model; all of `media/` was re-rendered and every image checked. The kit's default cutaway works for this model because it is centered near the origin; no workaround was needed. Temporary `media/_views*` folders were removed.
- TWK-PRB-001, TWK-PRC-001 and TWK-REQ-001 revised to v0.3; `README.md` (TRL badge, concept numbers, components, links) and `project.yaml` (`trl: 3`, `trl_target: 3`, evidence list) updated. PDFs rebuilt in `docs/pdf/`.

Design changes found necessary by the calculations, within the adopted choices: the input fuse rises from 2 A to 3.15 A time-delay (peak 2.29 A at 9 V), and the UPS module must have a buck-boost charger to charge the 12.8 V pack to 14.6 V from a 9 to 12 V input ($25 to $30). Batched database commits every 10 s are adopted in the twin service design to limit card wear.

### Requirement status (TWK-CAL-001, Table 2)

2 not met, 1 at risk, 5 met by calculation, 7 met by design, 1 not verifiable at TRL 3.

| ID | Status | Key number |
| --- | --- | --- |
| R1 Uplink loss | **Not met** (marginal) | 1.02 % at SF9 with all 50 nodes at 5 min (target under 1 %); 0.30 % at SF7, 0.56 % at SF8, 0.21 % for an SF7 to SF9 mix; 48 nodes meet it at SF9. The TRL 2 "met" claim rested on a low airtime figure |
| R14 Cost | **Not met** | $290.00 against $200 `budget_usd`; $10 within the recommended $300, awaiting Amish |
| R12 Thermal | At risk | Processor 69.1 °C at light load (15.9 K margin), 96.9 °C at sustained full load, vented, at 40 °C ambient; throttle point and thermal resistance assumed |
| R13 Setup time | Not verifiable at TRL 3 | Needs a timed trial |
| R3, R5, R8, R9, R10 | Met by calculation | 4.73 GB/yr on 56 GB free; 4.7 s worst latency; 6.41 W average; 2.40 h backup (1.63 h worst); 294 mm of rail |
| R2, R4, R6, R7, R11, R15, R16 | Met by design | R6 frame rate on a phone not verifiable at TRL 3; 7-day buffer 91 MB |

Key numbers: airtime 71.9 ms (SF7) to 1810.4 ms (SF12) for a 20-byte reading; 20.6 W peak input; 2.42 GB of 4 GB memory in use; card writes 35 to 53 GB a year.

### Decisions recorded (TWK-DDR-001)

Decided by Amish, 2026-09-25: go with recommendation (previously adopted for TRL 3 and open for his review): D1 8-channel LoRaWAN concentrator; D2 4 GB Pi 5 class board; D3 TimescaleDB; D4 lightweight stack plus a TwinKit service; D5 FieldNode battery and solar charge as the first example twin; D6 the YAML twin file fields sketched in the precis; D7 off-the-shelf LiFePO4 pack with built-in BMS. No reworded pitch or problem line was recommended, so `project.yaml` and `README.md` keep the existing wording.

### Still awaiting Amish

1. **O1, budget.** Decided by Amish, 2026-09-25: go with recommendation. `budget_usd` raised from $200 to $300 (TWK-DDR-002). The design ($290) is costed for the recommended option, since D1 keeps LoRaWAN.
2. **O2, co-design partner** outside the lab. No recommendation was made. Proposed, awaiting Amish.
3. **New, R1 at SF9.** Options: (a) keep the target and require adaptive data rate so near nodes use SF7 or SF8 (0.21 % for an even mix); (b) state the design point as 48 nodes at SF9 and 5 min, or 50 nodes at FieldNode's 15 min default (0.34 %); (c) relax the target to 1.5 %. Recommendation: (a), since it needs no hardware change. Decided by Amish, 2026-09-25: go with recommendation (TWK-DDR-002).
4. **New, R12 load profile.** Recommendation: define R12 at the normal light load and require heavy database jobs to run in cool hours, with a larger or metal enclosure as the fallback if tests show throttling. Decided by Amish, 2026-09-25: go with recommendation (TWK-DDR-002).

### Cross-repo consistency

- FieldNode (FND REVIEW): LoRaWAN radio, STM32WL-class module, 20-byte payload, 15 min default interval, TwinKit as the default gateway. TwinKit's airtime figures now match FieldNode's Table 3 (72 ms at SF7, 247 ms at SF9, 1.8 s at SF12). TwinKit is sized for 5 min, which is conservative. No conflict. Note: a FieldNode at SF9 and 5 min would exceed The Things Network's 30 s fair-use limit if moved to that public network; on a private TwinKit gateway only the EU868 1 % duty cycle applies (0.08 % used).
- CellGuard: not used at this size (D7); no interface assumed.
- CalRig: calibration records could set channel tolerances later; no interface assumed at TRL 3.
- CityTwin (not in the shared set, but it depends on TwinKit): its review recommends costing the gateway in TwinKit, which matches O1. Its sealed street cabinet in sun is hotter than the 40 °C case here, so R12 and the pack temperature need a separate check there.

### Safety concerns

- LiFePO4 pack: built-in BMS and fuse; charge only through the UPS module; the buck-boost charger must be set for LiFePO4 (14.6 V) and must not charge below 0 °C or above 45 °C.
- Input protection: the 3.15 A time-delay fuse sits at the supply input; wire sized for at least 3 A.
- 12 V supply: certified mains adapter; any cabinet or mains-side wiring by a qualified electrician.
- Thermal: a sealed or sun-exposed enclosure at 40 °C can drive the processor past its throttle point under heavy load; this is a reliability risk rather than a fire risk at these powers.
- Cybersecurity and over-reliance: default credentials, open ports and unpatched software remain the main real-world risk; the twin is a monitoring aid and does not replace required alarms or protection.

### Gaps and notes

- Prices are indicative, not supplier quotes. A WebFetch check of the Raspberry Pi 5 price was not approved in time, and a supplier page for a concentrator module returned a clearance price that did not look representative, so no price was changed on web evidence. No citations were flagged as unchecked in the TRL 2 note; none were added.
- Assumptions that only tests can settle: processor thermal resistance and throttle point, board and concentrator power, card write amplification and endurance, and the latency of each software stage.
- The GA sheet is at 1:5 because the antenna sets the height; the views are small but legible.
- Existing material beyond TRL 3: `build-log/README.md` (scaffold) is present, untouched and not extended. `firmware/` and `electronics/` hold only placeholders. No test, build or firmware material was created.

### Recommended next step

TRL 4 is on hold by Amish's instruction; this repo stops at TRL 3. Amish's review is needed on the budget (O1), the co-design partner (O2), and the new R1 and R12 proposals above. For the record only, TRL 4 would need: a bench build of the gateway; a lab test report (TST, `environment: lab`) covering packet loss with real FieldNodes at several spreading factors, measured power and backup time, processor temperature at 40 °C under light and heavy load, database size and card writes over a sustained run, and a timed setup trial for R13; and build log entries. None of this has been started.

## Session 2026-09-25: recommendations accepted

On 2026-09-25 Amish wrote: "i accept all your recommendations, go with them across all repos." Every TwinKit item with a recommendation is now **Decided by Amish, 2026-09-25: go with recommendation**, recorded in `docs/decisions/0002-recommendations-accepted.md` (TWK-DDR-002 v0.1). TWK-DDR-001 is revised to v0.2 with the new status.

### Decisions applied and what changed

| Item | Decision | Before | After |
| --- | --- | --- | --- |
| O1 Budget | Raise the budget (option a) | `budget_usd` $200; R14 not met ($290 against $200) | `budget_usd` $300; R14 target $300, met ($10 margin) |
| N1 R1 at SF9 | Require adaptive data rate (option a) | R1 not met: 1.02 % loss with all 50 nodes at SF9 | R1 restated with adaptive data rate; 0.21 % for an SF7 to SF9 mix, met [A6] |
| N2 R12 load profile | Define R12 at light load; heavy jobs in cool hours | R12 at risk (96.9 °C at sustained full load) | R12 restated; 69.1 °C at light load, 15.9 K margin, met [F6] |
| D1 to D7 | LoRaWAN concentrator, 4 GB board, TimescaleDB, lightweight stack, FieldNode example twin, twin file schema, off-the-shelf LiFePO4 pack | Adopted for TRL 3, open for review | Decided; status wording updated in TWK-PRB-001, TWK-PRC-001, TWK-DDR-001 and `bom/bom.csv` |

Files changed: `project.yaml` (`budget_usd` 300, DDR-002 added to evidence), `README.md` (budget, concept numbers, new "What sparked the idea"), TWK-PRB-001 v0.4, TWK-PRC-001 v0.4 (adaptive data rate and cool-hours rules added to the design), TWK-REQ-001 v0.4 (R1, R12, R14 restated), TWK-CAL-001 v0.2 and `docs/04-calcs/sizing.py` (new tags A6 and F6; R14 read against the $300 budget), `bom/bom-notes.md`, `bom/bom.csv` (status notes only, prices unchanged at $290.00), `cad/src/concept_media.py` (two key figures). No geometry changed, so TWK-DWG-001 stays at Rev P1; the model, drawing, media and PDFs were regenerated so that every generated file shows the designmolecule.com address. The "What sparked the idea" section now cites Apollo 13's ground simulator work (NASA) instead of a portfolio review.

### Requirement status (TWK-CAL-001 v0.2)

0 not met, 0 at risk, 8 met by calculation, 7 met by design, 1 not verifiable at TRL 3.

| ID | Status | Key number |
| --- | --- | --- |
| R13 Setup time | Not verifiable at TRL 3 | Needs a timed trial |
| R1, R3, R5, R8, R9, R10, R12, R14 | Met by calculation | 0.21 % loss with ADR; 4.73 GB/yr on 56 GB; 4.7 s latency; 6.41 W; 2.40 h backup; 294 mm rail; 69.1 °C processor at light load; $290 of $300 |
| R2, R4, R6, R7, R11, R15, R16 | Met by design | R6 frame rate not verifiable at TRL 3 |

R12 and R14 are met on thin evidence: R12 on an assumed thermal resistance and throttle point, R14 on indicative prices with a $10 margin.

### Still awaiting Amish

- **O2, co-design partner** outside the lab (small water utility, makerspace or municipal team). No recommendation was made. Proposed, awaiting Amish.

### Cross-repo actions

- **FieldNode:** nodes must accept LoRaWAN adaptive data rate commands so that R1 holds (TWK-REQ-001 v0.4, R1). Raise with FieldNode; FieldNode was not edited.
- **CityTwin:** its gateway now costs up to $300 in parts (TwinKit budget), and a sealed street cabinet in sun remains outside TwinKit's 40 °C light-load case for R12. Raise with CityTwin; CityTwin was not edited.

### TRL 4

TRL 4 remains on hold by Amish's instruction. Decided work that needs TRL 4 (timed setup trial for R13, thermal test to confirm R12, packet-loss test with adaptive data rate, supplier quotes for R14, and the larger or metal enclosure fallback) is recorded as decided but on hold. `trl` and `trl_target` stay at 3.

## Session 2026-09-26: photoreal renders

Amish asked on 2026-09-26 for photoreal renders across the portfolio, starting with the software and playbook repos (Group C). This repo has no new product model: the existing concept scene from `cad/src/concept_media.py` was rendered with Blender Cycles (`.kit/scene_export.py`, `.kit/photoreal.py`) on Amish's Mac and captioned with the project, repository and viewing direction.

- New: `media/render-hero.png`, `media/render-detail.png`. The README now leads with `media/render-hero.png`.
- Geometry, BOM, calculations and drawings are unchanged. `trl` stays 3; TRL 4 remains on hold.

## Session 2026-09-27: kit 1.5.0 and image quality

- Kit 1.5.0 synced: STANDARDS v1.5 (sections 12 to 15: product renders, storefront images and image quality, public release, authorship and signing), `.kit/cards.py`, `.kit/image_qc.py`, `.kit/release_gate.py`, issue templates, and the `/render-product` and `/release` commands. `CLAUDE.md` now matches `.kit/CLAUDE.md`.
- Every `media/render-*.png` recaptioned from its original render with the new layout: the title, concept label and repository sit in a band above the render and the view note in a band below it, each line wrapped to the image width, so no text overlaps other text or the render or runs off the image. `media/card.png` and `media/social-preview.png` regenerated with the same rules.
- `python .kit/image_qc.py` and `python .kit/release_gate.py` pass. trl stays 3.

## Session 2026-10-02: design for construction and prototype build plan (kit 1.7.0)

Amish approved the build plan format on 2026-09-30 and asked for it across all repos, with outstanding decisions kept in a separate design decisions register. He also wrote on 2026-09-30: "If you are realising that the design cannot be built as per concept - fix the design assumptions to match and be physically feasible as you draw the illustrations." This session installed kit 1.7.0 and did that for TwinKit.

### What was done

- Kit 1.7.0 installed (`.kit/`, `.claude/commands/`); `CLAUDE.md` replaced by `.kit/CLAUDE.md`.
- `cad/src/model.py`: constructable model with 274 build123d checks (`python cad/src/model.py --check`, all pass): no overlaps, every part touching what holds it, clearances kept. STEP and STL regenerated.
- `docs/decisions/0003-design-for-construction.md` (TWK-DDR-003 v0.1, status proposed): every change, made under Amish's 2026-09-30 instruction to make the design physically buildable; open for his review.
- `cad/src/build_plan_media.py`: overview, 5 making sketches (TWK-DWG-101 to 105), 2 hole layouts, 7 joint close-ups, 17 assembly step pictures and a wiring diagram, all drawn from the model.
- `docs/05-build-plan.md` (TWK-BLD-001 v0.1) and `docs/06-design-decisions.md` (TWK-DEC-001 v0.1).
- `cad/drawings/TWK-DWG-001` Rev P3; concept media regenerated (`media/hero.png`, `exploded.png`, `cutaway.png`, `concept-blueprint.*`, `model.glb`, `viewer.html`).
- `bom/bom.csv` (lines 1, 2, 3, 11, 12 respecified; lines 17 to 21 added) and `bom/bom-notes.md`; `docs/04-calcs/sizing.py` and TWK-CAL-001 v0.3 (new tag [F7]; cost against the value-engineering target); TWK-REQ-001 v0.5, TWK-PRC-001 v0.5, TWK-PRB-001 v0.5; `README.md` (links line, "Building the prototype"); `project.yaml` (`design_state: constructable`, new evidence). PDFs rebuilt in `docs/pdf/`.

### Design changes made for construction (TWK-DDR-003)

| # | Change | Reason |
| --- | --- | --- |
| P1 | Backup pack moved out of the UPS module into its own 3-module battery box; UPS module 3 modules wide with no internal battery | Two bought parts cannot nest |
| P2 | Vent slots moved from the end walls to the long walls, same area and spacing | The end walls face neighbouring modules 2 mm away |
| P3 | Computer and HAT on 6 mm and 16 mm brass standoffs with a header extender | Both boards floated |
| P4 | SMA bulkhead through a 6.5 mm hole in the cover, pigtail to the HAT | The antenna sat on the cover with no hole |
| P5 | RJ45 feed-through coupler and an M16 two-hole gland in the front wall | No path for the network or power leads |
| P6 | True TS35 top-hat rail, 350 mm, on three M4 screws into tapped holes | U channel with no fixing |
| P7 | DIN clip hooks modelled on every module; two end stops | Modules could slide off |
| P8 | 6 mm aluminium plate, tapped, on four rubber feet, with corner holes | "Plywood or aluminium" could not hold the rail |
| P9 | USB-C power lead and a power-fail pair to the computer | No power or power-fail path into the enclosure |

### Key results

- Rail: 331 mm of modules (18.9 modules), 345 mm with end stops, on a 350 mm rail; R10 met.
- Thermal: unchanged design case (69.1 °C at light load); with the end walls counted as shielded, 72.8 °C, 12.2 K margin [F7]; R12 met.
- Cost: value-engineering target USD 300; estimated cost of the constructable design USD 334 (USD 34 over the target). The concept was USD 290.
- Requirements: none not met, none at risk, 7 met by calculation, 7 met by design, R13 not verifiable at TRL 3, R14 reported against its target.

### Proposed, awaiting Amish

All in TWK-DEC-001: accept the TWK-DDR-003 changes (recommended); the region and radio band, to match FieldNode's pilot region; the co-design partner (no recommendation). Eight purchase checks are listed there.

### Stale media

The photoreal renders (`media/render-hero.png`, `media/render-detail.png`), `media/card.png` and `media/social-preview.png` show the concept: the pack inside the UPS, vents in the end walls, no battery box or end stops. They need regenerating on Amish's Mac; `media/render-hero.png` and `media/render-detail.png` are also absent from this cloud copy.

### Safety

No change to the safety case. The pack, its BMS and fuse, and the charge path through the UPS module are unchanged; the build plan adds safety stops before the adapter is plugged in, before the pack is connected, for the first charge, before the radio transmits and before the gateway joins a wider network.

### Recommended next step

Amish to review TWK-DDR-003 and the register. TRL 4 (building and testing to TWK-BLD-001) remains on hold.

## Session 2026-10-02: open decisions decided

Amish, 2026-10-02: "APPROVED: The open decisions from the last wave (TremorTrace to ZeerBox) came in after the review and aren't on the page either." This approves the recommendation written for each open decision in the design decisions register (TWK-DEC-001), as he did for the other 555 open decisions ("i approve your recommendations for all 555 open decisions."). trl stays 3; no build or test work was done, and the model, BOM quantities and prices, and pictures are unchanged.

### Decisions recorded

Three decisions, all moved to Decisions made in TWK-DEC-001, dated 2026-10-02:

1. Design for construction accepted: the changes P1 to P9 of TWK-DDR-003, as made.
2. Region and radio band of the first build: US915, with the US915 concentrator HAT and a 915 MHz antenna, to match FieldNode's decided first variant.
3. Co-design partner outside the lab: the first candidate to approach for the operator view is a small municipal water utility in the Dallas and Fort Worth area, found through the Texas Water Utilities Association, with Dallas Makerspace as the build and test partner.

### Documents changed

- `docs/06-design-decisions.md` (TWK-DEC-001 v0.2): open decisions moved to Decisions made.
- `docs/decisions/0003-design-for-construction.md` (TWK-DDR-003 v0.2): acceptance recorded in the status line (record stays Draft).
- `docs/decisions/0001-trl2-review-decisions.md` (TWK-DDR-001 v0.3) and `docs/decisions/0002-recommendations-accepted.md` (TWK-DDR-002 v0.2): O2 recorded as decided.
- `docs/01-problem.md` (TWK-PRB-001 v0.6): co-design partner question answered.
- `docs/02-concept.md` (TWK-PRC-001 v0.6): concentrator row names US915 for the first build; partner open question answered.
- `bom/bom.csv` (line 7 specification text only, no quantity or price change) and `bom/bom-notes.md`: US915 for the first build.

### Follow-up actions to carry approved decisions into the design

1. Decision 2 (calculations): Restate the regulatory air-time check in TWK-CAL-001 for US915 (400 ms dwell time per channel, no 1 % duty cycle) alongside the EU868 figure, and confirm the result for nodes at SF9 every 5 min.
2. Decision 2 (BOM): Price the US915 concentrator HAT and a 915 MHz antenna from a named supplier for lines 7 and 9.
3. Decision 2 (docs): Name US915 in the build plan's concentrator and antenna descriptions and in safety stop S5 when the build plan is next revised.
4. Decision 3 (docs): Approach a small municipal water utility in the Dallas and Fort Worth area through the Texas Water Utilities Association, and Dallas Makerspace for the build.

### Points found in the review

- Item 2 depends on FND-DDR-001 O1, which is no longer open: FieldNode decided US915 as its default first variant on 2026-10-02.
- BOM line 7 still reads 'EU868 or US915 version to suit region'; with item 2 decided it should name US915 (text only, price unchanged).

## Session 2026-10-02: approved follow-ups carried out

Amish approved all follow-up actions from the open-decision sign-off on 2026-10-02. No CAD model, drawing or picture changed. TwinKit is a scene-render repo with no `cad/src/product_model.py`, and none was created: the hero is the scene render, as before. The model is unchanged, so the scene was exported from `cad/src/concept_media.py` with `.kit/scene_export.py` (`export_views.py` needs a product model).

### Approved follow-ups carried out

1. Decision 2, calculations: done. `docs/04-calcs/sizing.py` prints a new tag [A7] and TWK-CAL-001 v0.4 restates the air-time check for US915: a 246.8 ms frame at SF9 every 5 min is 62 % of the 400 ms dwell time per channel and 71 s of air per day, with no duty-cycle limit; SF10 (452.6 ms) would exceed the dwell time, so the SF7 to SF9 range used for R1 is inside the limit. The EU868 figure stays alongside. R1 is unchanged.
2. Decision 2, BOM: partly done. Line 7 is priced from the Seeed Studio WM1302 SPI US915 module and Seeed WM1302 Raspberry Pi HAT (HAT USD 20.79 at RobotShop; module USD 39 list at a reseller, about USD 60 for the parts) and kept at USD 80 for shipping from two sellers and a HAT that fits the Pi 5 class computer (Seeed lists the HAT for boards up to the Pi 4B). Line 9 stays at USD 12: a named supplier price for the 915 MHz antenna was not found. Both are indicative, not quoted.
3. Decision 2, docs: done. TWK-BLD-001 v0.2 names US915 and the 915 MHz band in the concentrator and antenna descriptions and in safety stop S5.
4. Decision 3, approach the municipal water utility and Dallas Makerspace: not done, outreach by Amish.
5. Render scene: exported to `/home/claude/renders/twinkit` (view hero: `twinkit__hero.npz` and `.json`, plus `twinkit__jobs.json`). Photoreal render, card and social preview are made on Amish's Mac.

### Results

- Requirement status changes: none.
- Value-engineering target: USD 300. Estimated cost of the constructable design: USD 334 (USD 34 over the target). `budget_usd` is unchanged. Mass is not tracked in this repo.

### Documents changed

- `docs/04-calcs/01-sizing.md` (TWK-CAL-001 v0.4), `docs/05-build-plan.md` (TWK-BLD-001 v0.2)
- `bom/bom.csv` and `bom/bom-notes.md`, `docs/04-calcs/sizing.py`

### Cross-repo actions

None.

## 2026-10-02: photoreal renders redone on the constructable design

Rendered with Blender Cycles on Amish's Mac from the updated appearance model; captioned with `.kit/photo_caption.py`; `media/card.png` and `media/social-preview.png` regenerated with `.kit/cards.py`. Views: hero. image_qc passes. Appearance deviations are those logged above as proposed, awaiting Amish.

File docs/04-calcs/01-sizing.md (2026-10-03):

---
doc_id: TWK-CAL-001
title: TwinKit sizing calculations
project: TwinKit
doc_type: Calculation
version: "0.4"
status: Draft
date: '2026-10-02'
author: Amish Chadha
license: CERN-OHL-S-2.0
revisions:
- version: "0.1"
  date: '2026-09-25'
  author: Amish Chadha
  change: First issue for TRL 3 (airtime and collisions, storage and card wear, latency, power and fuse, backup, enclosure and processor temperature, memory, rail, cost)
- version: "0.2"
  date: '2026-09-25'
  author: Amish Chadha
  change: Recommendations accepted by Amish (DDR-002). R1 judged with adaptive data rate, R12 at light load with heavy jobs in cool hours, R14 against the $300 budget
- version: "0.3"
  date: '2026-10-02'
  author: Amish Chadha
  change: Constructable design (TWK-DDR-003). Vents in the long walls, battery box, 350 mm rail, new fittings costed; shielded end-wall sensitivity [F7]; budget treated as a value-engineering target
- version: "0.4"
  date: '2026-10-02'
  author: Amish Chadha
  change: "Regulatory air-time check restated for US915 alongside EU868 (new tag [A7]); no requirement status changed"
---

# TwinKit sizing calculations

On paper, TwinKit meets fourteen of its sixteen requirements (seven by calculation, seven by design); R13 (setup time) cannot be checked at TRL 3 and needs a timed trial, and R14 (cost) is reported against a value-engineering target rather than as met or not met. Version 0.3 follows the constructable design of TWK-DDR-003: the vents move from the end walls to the two long walls (same area and spacing, so the thermal results stand), the backup pack moves out of the UPS module into its own battery box, the rail grows to 350 mm, and the fittings that hold everything together are now in the BOM. Value-engineering target: USD 300. Estimated cost of the constructable design: USD 334 (USD 34 over the target) [I1, I2]. Version 0.2 applied the decisions Amish made on 2026-09-25 (TWK-DDR-002), which changed three results from v0.1. R1 (uplink loss) is now judged with adaptive data rate required, which spreads nodes over SF7 to SF9 and loses 0.21 % of uplinks against 1 %; with every node forced to SF9 the loss would be 1.02 % (v0.1 reported R1 as not met on that case). R12 (no processor throttling at 40 °C) is now defined at the normal light load, where the processor stays 15.9 K below its assumed throttle point, with heavy jobs scheduled for cool hours (v0.1: at risk). The calculations changed two parts of the TRL 2 concept: the input fuse rises from 2 A to 3.15 A time-delay, and the UPS module is specified with a buck-boost charger so that it can charge the 12.8 V pack from a 9 V to 12 V input. Several TRL 2 figures were corrected (see the last section). Every number in this note is printed by `docs/04-calcs/sizing.py`; the tag in brackets, for example [A2], is the line of that script's output that carries it.

> **Safety:** These are first-principles estimates for a paper proof of concept. They are not a substitute for electrical safety checks of the 12 V wiring and the LiFePO4 pack, or for a security audit of the gateway. See TWK-PRC-001, Safety.

## Scope and method

The note checks every requirement in TWK-REQ-001 v0.4 against the design in TWK-PRC-001 v0.4, the decisions in TWK-DDR-001 and TWK-DDR-002 and the parametric model `cad/src/model.py`. The script imports the model's `PARAMS` and derived dimensions, so the enclosure size, vent areas and rail length used here are the ones in the STEP files and in drawing TWK-DWG-001. It also reads `bom/bom.csv` and `budget_usd` in `project.yaml`. Run it from the repo root with `python docs/04-calcs/sizing.py`.

The design case is the R1 design point: 50 sensor nodes, each sending a 20-byte reading every 5 min, to one gateway on a bench or in an equipment room at up to 40 °C. FieldNode's default interval is 15 min (FND-PRC-001 v0.2), so the 5 min case is conservative for FieldNode fleets.

## Assumptions

*Table 1. Main assumptions.*

| Area | Assumption | Basis |
| --- | --- | --- |
| Radio | 20-byte payload plus 13 bytes of LoRaWAN overhead; 125 kHz, coding rate 4/5, 8-symbol preamble, explicit header, CRC on, low data rate optimization at SF11 and SF12; unconfirmed uplinks | FieldNode payload convention; Semtech time-on-air formula |
| Traffic | Uplinks spread evenly over 8 channels, random arrival (pure ALOHA); spreading factors treated as orthogonal; no capture effect | Conservative screening model |
| Storage | 10 values per reading; 90 bytes per stored value in a narrow table with index, uncompressed; compressed chunks keep 10 % of that after 7 days; 8 GB for the system | Conservative for PostgreSQL rows; compression ratio assumed |
| Card wear | One 8 kB write-ahead log page per commit plus heap and index writes at twice the data size; write amplification inside the card of 10 | Assumed; card endurance data not available |
| Latency | Forwarder 0.1 s, network server 0.3 s, MQTT 0.05 s, twin service 0.2 s, database 0.2 s, dashboard refresh 2 s | Typical figures for these tools on a Pi 5 class board, to be measured |
| Power | Board 4 W light load, 8 W sustained full load; fan 0.5 W; concentrator 1.0 W receiving, 2.5 W during a downlink; converter 90 %; UPS 0.3 W; charger 14.6 V at 0.5 A, 90 % | Typical figures, to confirm from datasheets and measurement |
| Backup | 12.8 V, 1.5 Ah pack; 80 % usable; 85 % capacity at 0 °C; 80 % at end of life | Typical LiFePO4 data |
| Thermal | 40 °C ambient; combined convection and radiation 5 W/m²K (8 W/m²K as a check); vent discharge coefficient 0.6; bench mounting, so the vents are only 42 mm apart vertically; processor dissipates 2.5 W at light load and 6.5 W at full load; 4 K/W from processor to enclosure air with the fan running; throttling at 85 °C | Handbook ranges; thermal resistance and throttle point assumed for a Pi 5 class board, to be measured |

## A. Airtime and collisions (R1)

- **Traffic.** 50 nodes at 5 min give 600 uplinks per hour, 75 per channel per hour [A1].
- **Time on air.** A 33-byte frame takes 71.9 ms at SF7, 133.6 ms at SF8, 246.8 ms at SF9, 452.6 ms at SF10 and 1810.4 ms at SF12 [A2]. These agree with FieldNode's airtime table (FND-PRC-001 v0.2, Table 3).
- **Loss.** With every node on one spreading factor, collisions lose 0.30 % at SF7, 0.56 % at SF8, 1.02 % at SF9, 1.87 % at SF10 and 7.27 % at SF12 [A2]. An even mix of SF7, SF8 and SF9 loses 0.21 % [A3]. At FieldNode's 15 min default every case up to SF10 stays under 1 % (0.34 % at SF9) [A2].
- **Verdict.** R1, as restated in TWK-REQ-001 v0.4, requires adaptive data rate so that each node uses the fastest spreading factor its link allows. For an even SF7 to SF9 mix the loss is 0.21 % against 1 % [A6], so R1 is met. For information: if all 50 nodes were forced to SF9 at 5 min the loss would be 1.02 %, and the largest fleet under 1 % in that case is 48 nodes [A5]. FieldNode's 15 min default keeps every case up to SF10 under 1 % [A2].
- **US915 dwell time.** The first build is US915 (TWK-DEC-001, 2026-10-02), which has no 1 % duty cycle but limits each transmission to a 400 ms dwell time per channel. A node at SF9 and 5 min sends one 246.8 ms frame per uplink, 62 % of the dwell time, and uses 71 s of air per day [A7]. SF9 is the slowest spreading factor that fits: a 33-byte frame at SF10 takes 452.6 ms and would exceed it, so the SF7 to SF9 range that adaptive data rate uses for R1 is inside the US915 limit [A7]. R1 and its status are unchanged.
- **Regulatory duty cycle (EU868).** At SF9 and 5 min each node uses 0.08 % of air time, well inside the 1 % EU868 sub-band limit [A4]. The Things Network's 30 s per day fair-use limit does not apply on a private TwinKit gateway, but a node at SF9 and 5 min would exceed it (71 s per day) if moved to that public network [A2].

## B. Storage and card wear (R3, R7)

- **Volume.** R3's case stores 52.6 million values a year. At the TRL 2 figure of 30 bytes that is 1.58 GB; at a conservative 90 bytes uncompressed it is 4.73 GB, and 0.55 GB with compression after 7 days [B1].
- **Capacity.** With 56 GB free on the 64 GB card, the data fits for 11.8 years uncompressed [B2]. R3 is met.
- **Sync buffer.** Seven days of readings for upstream sync take 91 MB [B3]. R7's buffer is met.
- **Wear.** Committing each uplink writes about 53 GB a year; batching commits every 10 s writes about 35 GB. At an assumed card write amplification of 10, that is 8.2 or 5.5 full-card program cycles a year [B4]. This is modest for a high-endurance card, but the card's own endurance and amplification are unknown. Batched commits are adopted in the twin service design, and an SSD remains the upgrade path.

## C. Latency and flag timing (R5)

- **Reading to dashboard.** 0.9 s at SF7 with a pushed update, up to 4.7 s at SF12 with a 2 s dashboard refresh [C1]. R5 (60 s) is met with a wide margin.
- **Fault to flag.** A flag is raised only after the residual stays out of tolerance for the hold time. With the example 30 min hold, a step fault is flagged within 35 min at 5 min readings, or 45 min at FieldNode's 15 min default [C2]. The hold time is therefore the design lever for early warning, not the data path.

## D. Power, peak current and fuse (R8)

- **Average.** 5.5 W on the 5 V rail becomes 6.41 W at the 12 V input, 0.53 A, or 56 kWh a year [D1]. R8 (8 W) is met. The TRL 2 figure of about 6 W was slightly low.
- **Peak.** With the board at full load, a downlink in progress and the pack charging, the input peaks at 20.6 W: 1.72 A at 12 V and 2.29 A at the 9 V lower limit of R8. The 5 V rail carries 2.16 A of the converter's 5 A [D2].
- **Fuse.** A 2 A fuse run at no more than 75 % of rating allows 1.50 A, too little at 9 V. A 3.15 A time-delay fuse allows 2.36 A [D3]. The BOM (line 13) is changed to 3.15 A T.
- **Charger interface.** The pack charges to 14.6 V, above a 12 V input. The UPS module (line 11) must therefore have a buck-boost charger that works from 9 V to 30 V. The BOM specification is changed accordingly; the price rises from $25 to $30 (indicative).

## E. Backup (R9)

- **Runtime.** On battery the gateway draws 6.41 W. The pack gives 15.36 Wh usable, which lasts 2.40 h when new and 1.63 h for an aged pack at 0 °C [E1]. R9 (30 min) is met in every case.
- **Shutdown and recharge.** A clean shutdown needs 0.13 Wh; the pack refills from its cut-off in about 2.4 h at 0.5 A [E2].

## F. Enclosure and processor temperature (R12)

- **Geometry.** The 157.5 x 90 x 60 mm enclosure exposes 0.0439 m². Two slot rows in each long wall give 640 mm² of low and of high vent, 42 mm apart vertically in the bench case. The constructable design (TWK-DDR-003) moved the slots from the end walls, which face the neighbouring modules only 2 mm away, to the long walls; area and spacing are unchanged. It holds 5.5 W at light load and 9.5 W at full load [F1].
- **Light load.** Vented, the enclosure air rises 19.1 K to 59.1 °C at 40 °C ambient and the processor reaches 69.1 °C, 15.9 K below throttling. Sealed, the air rises 25.1 K and the processor reaches 75.1 °C [F2].
- **Full load.** Sustained full load raises the processor to 96.9 °C vented and 109.3 °C sealed, so it would throttle [F2]. At the more typical 8 W/m²K it still reaches 88.3 °C [F3]. Doubling the vent area only brings it to 91.1 °C [F5].
- **Shielded end walls.** With modules 2 mm away on both sides, the end walls shed little heat. Leaving them out of the exposed area (0.0331 m² instead of 0.0439 m²) raises the processor to 72.8 °C at light load, still 12.2 K below the assumed throttle point, and 102.4 °C at full load [F7]. R12 is met in this more cautious case too.
- **Verdict.** R12, as restated in TWK-REQ-001 v0.4, applies at the normal light load (0.17 uplinks per second [G3]), with heavy jobs such as a full database recompression or backup scheduled for cool hours. In that case the processor reaches 69.1 °C, 15.9 K below the assumed throttle point [F6], so R12 is met on paper. A sustained heavy job at 40 °C would still throttle (96.9 °C), which is why the schedule rule is part of the design. The thermal resistance and throttle point are assumptions to be measured at TRL 4 (on hold); a larger or metal enclosure remains the hardware fallback if tests show throttling.
- **Pack.** The LiFePO4 pack sits in its own battery box beside the UPS module (TWK-DDR-003), away from the charger's 0.81 W of loss while charging [E3], so it stays within a few kelvin of ambient and inside the usual 45 °C charge limit at 40 °C. A sealed street cabinet in sun (CityTwin) is a different case and is not covered here.

## G. Memory

- **Budget.** At light load the stack uses about 2.42 GB of 4 GB: system 0.40, network server and Redis 0.25, MQTT 0.02, PostgreSQL with TimescaleDB 0.90, dashboard 0.20, twin service 0.15 and 0.50 GB of file cache headroom [G1]. A 2 GB board would be short by 0.42 GB [G2], which supports the 4 GB board adopted in TWK-DDR-001.
- **Load.** 0.17 uplinks per second, or 1.7 values per second, is a very light database load [G3].

## H. Rail and mounting (R10)

- **Rail.** Terminals, enclosure, converter, UPS and battery box take 331 mm (18.9 modules); with the two end stops they occupy 345 mm of a 350 mm rail [H1]. R10 (350 mm, 20 modules) is met. Before the constructable design the four modules took 294 mm (16.8 modules) of a 320 mm rail, with the pack drawn inside the UPS module.
- **Height.** The enclosure top is 67.5 mm above the plate and the antenna tip 264 mm [H2].

## I. Cost (R14)

- **Total.** All 21 BOM lines are priced; the total is $334.00: computer, cooler and card $85, radio and antenna $92, power and backup $85, enclosure, rail and plate $37, battery box and fittings for construction $35 [I1].
- **Against the target.** `budget_usd` is a hypothetical value-engineering target, not a limit (Amish, 2026-10-01). Value-engineering target: USD 300. Estimated cost of the constructable design: USD 334 (USD 34 over the target) [I2]. The concept was USD 290; the battery box, end stops, board mounting kit, cable entries, fixings and the aluminium plate added USD 44 (TWK-DDR-003). No custom PCB is used. Prices are indicative, not supplier quotes. Savings worth trying are listed in the design decisions register (TWK-DEC-001).

## J. Results against every requirement

*Table 2. Requirement status at TRL 3 [J1, J2].*

| ID | Requirement | Value | Target | Status |
| --- | --- | --- | --- | --- |
| R1 | Receive readings | 0.21 % loss with adaptive data rate (SF7 to SF9 mix); 1.02 % if all forced to SF9 | Under 1 %, 50 nodes at 5 min, adaptive data rate | Met |
| R2 | Common inputs | LoRaWAN concentrator, MQTT, HTTP | LoRaWAN, MQTT, HTTP | Met by design |
| R3 | Store history | 4.73 GB per year uncompressed on 56 GB free | 1 year | Met |
| R4 | Link data to model | Twin file schema, TWK-PRC-001 | Every channel mapped to a part and an expected value | Met by design |
| R5 | Compare measured and expected | 4.7 s worst case | 60 s | Met |
| R6 | 3D twin | glTF in a standard web viewer | Current browser, laptop or phone | Met by design; frame rate not verifiable at TRL 3 |
| R7 | Work offline | All local; 91 MB for 7 days | 7-day buffer | Met by design |
| R8 | Low-voltage power | 6.41 W average; 20.6 W peak | 9 to 30 V; 8 W average | Met |
| R9 | Ride through outages | 2.40 h new, 1.63 h worst | 30 min and clean shutdown | Met |
| R10 | Compact mounting | 331 mm, 18.9 modules (345 mm with end stops) | 350 mm, 20 modules | Met |
| R11 | Secure by default | First-boot credentials, TLS, no WAN ports | As stated | Met by design |
| R12 | Operate at 0 to 40 °C | Processor 69.1 °C at light load (72.8 °C with the end walls shielded); heavy jobs in cool hours (96.9 °C if run at 40 °C) | No throttling at light load (85 °C assumed) | Met |
| R13 | Quick setup | Not calculable | 60 min | Not verifiable at TRL 3 |
| R14 | Low cost | $334.00 | Value-engineering target $300 | $34 over the target |
| R15 | Open and exportable | Open-source stack, CSV and API | As stated | Met by design |
| R16 | Monitoring only | No control outputs | As stated | Met by design |

Summary: 0 not met, 0 at risk, 7 met by calculation, 7 met by design, 1 not verifiable at TRL 3 (R13), and R14 reported against its value-engineering target (USD 34 over). In v0.2: 8 met by calculation, with R14 met at $290. In v0.1: 2 not met (R1, R14), 1 at risk (R12).

## Checks against earlier figures

*Table 3. Earlier figures corrected by this note (TRL 2, and TRL 3 v0.2 where marked).*

| Quantity | TRL 2 (TWK-PRC-001 v0.2) | TRL 3 | Change |
| --- | --- | --- | --- |
| Airtime, 20-byte reading | about 60 ms (SF7), 1.3 s (SF12) | 71.9 ms, 1810.4 ms | Overhead bytes and low data rate optimization now counted |
| Loss at SF12, all nodes | about 5 % | 7.27 % | Follows the airtime |
| R1 status | Met at SF7 to SF9 | Not met at SF9 (1.02 %) | TRL 2 claim was wrong |
| Storage per year | about 1.6 GB | 4.73 GB uncompressed (0.55 GB compressed) | 90 bytes per value instead of 30 |
| Average power | about 6 W | 6.41 W | UPS loss counted |
| Backup time | about 2 h (2.3 h) | 2.40 h new, 1.63 h worst | Load and derating recomputed |
| Enclosure air rise | about 20 K | 19.1 K vented, 25.1 K sealed | Mounting face excluded, vents modeled |
| Rail used | about 300 mm (17 modules) | 294 mm (16.8 modules) | From the model |
| Parts cost | about $285 | $290.00 | UPS with buck-boost charger |
| Input fuse | 2 A | 3.15 A time-delay | Peak current at 9 V |
| Rail used | 294 mm (TRL 3 v0.2) | 331 mm, 345 mm with end stops | Battery box and end stops added (TWK-DDR-003) |
| Parts cost | $290.00 (TRL 3 v0.2) | $334.00 | Fittings for construction added (TWK-DDR-003) |

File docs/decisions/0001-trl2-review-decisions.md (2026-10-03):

---
doc_id: TWK-DDR-001
title: TwinKit TRL 2 review decisions
project: TwinKit
doc_type: Design decision record
version: "0.3"
status: Draft
date: '2026-10-02'
author: Amish Chadha
license: CERN-OHL-S-2.0
revisions:
- version: "0.1"
  date: '2026-09-25'
  author: Amish Chadha
  change: Record the TRL 2 review recommendations adopted for TRL 3 work and the items that remain open
- version: "0.2"
  date: '2026-09-25'
  author: Amish Chadha
  change: Recommendations accepted by Amish (DDR-002)
- version: "0.3"
  date: '2026-10-02'
  author: Amish Chadha
  change: O2 recorded as decided by Amish on 2026-10-02
---

# 0001: TRL 2 review decisions

- **Date:** 2026-09-25
- **Status:** accepted in part. On 2026-09-25 Amish accepted all recommendations ("i accept all your recommendations, go with them across all repos"). Items D1 to D7 and O1 are decided by Amish, 2026-09-25: go with recommendation (see TWK-DDR-002). O2 had no recommendation on 2026-09-25; Amish decided it on 2026-10-02 (TWK-DEC-001).

## Context

The TRL 2 review note (`docs/REVIEW.md`, session 2026-09-25, /populate) listed nine items as "Proposed, awaiting Amish", most with a recommendation. On 2026-09-25 Amish asked for this batch of repos to be taken through the usual process with the instruction "you know the drill, nothing gets past TRL 3". He has not reviewed this repo's items one by one. Under that instruction, every item that carries a recommendation is adopted as recommended for TRL 3 work, open for his review. Items without a recommendation stay open. A recommended change to `budget_usd` is not applied: the figure is recorded here and in `docs/REVIEW.md` as awaiting Amish.

## Options considered

The options for each item are those listed in `docs/REVIEW.md` (session 2026-09-25, /populate) and in TWK-PRC-001 v0.2, Key design choices.

## Decision

*Table 1. Items adopted for TRL 3 work, now decided by Amish (TWK-DDR-002).*

| # | Item | Adopted choice | Status |
| --- | --- | --- | --- |
| D1 | Radio | 8-channel LoRaWAN concentrator (SX1302 or SX1303 class), not a point-to-point LoRa receiver. Consistent with FieldNode's recommended LoRaWAN radio (FND REVIEW, item 1). | Decided by Amish, 2026-09-25: go with recommendation |
| D2 | Computer | 4 GB Raspberry Pi 5 class board, not a 2 GB board. TWK-CAL-001 [G1, G2] shows the stack needs about 2.4 GB. | Decided by Amish, 2026-09-25: go with recommendation |
| D3 | Database | TimescaleDB, rather than InfluxDB or SQLite. | Decided by Amish, 2026-09-25: go with recommendation |
| D4 | Twin platform | Lightweight open-source stack plus a small TwinKit twin service, not Eclipse Ditto. | Decided by Amish, 2026-09-25: go with recommendation |
| D5 | First example twin | FieldNode battery and solar charge. | Decided by Amish, 2026-09-25: go with recommendation |
| D6 | Twin file schema | The YAML fields sketched in the precis: project, model, and per channel an id, node, part (BOM number), unit, expected value (constant, curve or calculation reference), tolerance and hold time. | Decided by Amish, 2026-09-25: go with recommendation |
| D7 | Backup pack | Off-the-shelf 12.8 V LiFePO4 pack with a built-in BMS and fuse; a CellGuard-protected pack only in a later, larger version. | Decided by Amish, 2026-09-25: go with recommendation |

*Table 2. Items left open by v0.1. O1 was decided on 2026-09-25 and O2 on 2026-10-02.*

| # | Item | Status |
| --- | --- | --- |
| O1 | Budget. The TRL 2 review recommended raising `budget_usd` from $200 to $300 (option a), to keep LoRaWAN compatibility. Under the session instruction the budget is not changed: `budget_usd` stays at $200, and $300 is recorded as the recommended figure. TWK-CAL-001 [I2] states the $290 parts cost against both figures. The design is costed for option (a) because D1 (LoRaWAN) is adopted. | Decided by Amish, 2026-09-25: go with recommendation; `budget_usd` raised to $300 (TWK-DDR-002) |
| O2 | Co-design partner outside the lab (a small water utility, a makerspace or a municipal team). No recommendation was made on 2026-09-25. | Decided by Amish, 2026-10-02 (TWK-DEC-001): the first candidate to approach is a small municipal water utility in the Dallas and Fort Worth area, found through the Texas Water Utilities Association, with Dallas Makerspace as the build and test partner |

No reworded pitch or problem line was recommended, so `project.yaml` and `README.md` keep the existing wording.

## Consequences

- `project.yaml`: only the TRL fields change. `budget_usd` stays at $200.
- TWK-PRB-001, TWK-PRC-001 and TWK-REQ-001 are revised to v0.3. The design choices in D1 to D7 are no longer described as "proposed" but as adopted for TRL 3 pending Amish's review. No requirement target is relaxed or redefined as a result of these items; R14 keeps its $200 target until Amish decides O1.
- TWK-CAL-001 led to two changes within these choices: a 3.15 A time-delay input fuse in place of 2 A, and a UPS module with a buck-boost charger for the 12.8 V pack (parts cost now $290).
- Cross-repo: FieldNode sends 20-byte LoRaWAN uplinks every 15 min by default; TwinKit is sized for 5 min, which is conservative. CityTwin recommends costing the gateway in TwinKit, which matches this record. No conflict was found; see `docs/REVIEW.md`.
- TRL 4 is on hold by Amish's instruction. Nothing in this record authorizes building or testing.
- Update at v0.2: the consequences above describe the state at v0.1. After Amish's decision of 2026-09-25, `budget_usd` is $300 and R14's target is $300; R1 and R12 were also restated. See TWK-DDR-002.

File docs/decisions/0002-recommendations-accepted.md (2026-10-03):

---
doc_id: TWK-DDR-002
title: TwinKit recommendations accepted
project: TwinKit
doc_type: Design decision record
version: "0.2"
status: Draft
date: '2026-10-02'
author: Amish Chadha
license: CERN-OHL-S-2.0
revisions:
- version: "0.1"
  date: '2026-09-25'
  author: Amish Chadha
  change: Recommendations accepted by Amish (DDR-002)
- version: "0.2"
  date: '2026-10-02'
  author: Amish Chadha
  change: O2 recorded as decided by Amish on 2026-10-02
---

# 0002: Recommendations accepted

- **Date:** 2026-09-25
- **Status:** accepted

## Context

TWK-DDR-001 and `docs/REVIEW.md` (sessions of 2026-09-25) listed items that were adopted for TRL 3 pending Amish's review, or proposed and awaiting Amish, each with a recommendation. On 2026-09-25 Amish wrote: "i accept all your recommendations, go with them across all repos." Every item that carried a recommendation is therefore decided as recommended. Where a recommendation named one of several options, that option is the decision. Items with no recommendation stay open. TRL 4 remains on hold by Amish's instruction, and `trl` and `trl_target` stay at 3.

## Options considered

The options for each item are those listed in `docs/REVIEW.md` (TRL 2 and TRL 3 sessions) and in TWK-DDR-001.

## Decision

*Table 1. Items decided by Amish, 2026-09-25: go with recommendation.*

| # | Item | Decision | What changed in the repo |
| --- | --- | --- | --- |
| D1 | Radio | 8-channel LoRaWAN concentrator (SX1302 or SX1303 class) | Status wording only in TWK-PRC-001, TWK-PRB-001, TWK-DDR-001 and `bom/bom.csv`; no design change |
| D2 | Computer | 4 GB Raspberry Pi 5 class board | Status wording only |
| D3 | Database | TimescaleDB | Status wording only |
| D4 | Twin platform | Lightweight open-source stack plus a TwinKit twin service | Status wording only |
| D5 | First example twin | FieldNode battery and solar charge | Status wording only; cross-repo action for FieldNode (adaptive data rate, below) |
| D6 | Twin file schema | Project, model, and per channel an id, node, part (BOM number), unit, expected value, tolerance and hold time | Status wording only |
| D7 | Backup pack | Off-the-shelf 12.8 V LiFePO4 pack with built-in BMS and fuse | Status wording only |
| O1 | Budget | Option (a): raise the budget to $300 to keep LoRaWAN compatibility | `project.yaml` `budget_usd` 200 to 300; R14 target $200 to $300 (TWK-REQ-001 v0.4); R14 not met to met ($290); README budget line; TWK-PRB-001 constraint; `bom/bom-notes.md`; concept blueprint key figure |
| N1 | R1 at SF9 | Option (a): keep the 1 % target and require adaptive data rate so near nodes use SF7 or SF8 | R1 restated in TWK-REQ-001 v0.4; adaptive data rate added as a design rule in TWK-PRC-001 v0.4; TWK-CAL-001 v0.2 judges R1 on the SF7 to SF9 mix: 1.02 % (not met) to 0.21 % (met) [A6]; blueprint key figure updated |
| N2 | R12 load profile | Define R12 at the normal light load and schedule heavy database jobs for cool hours; a larger or metal enclosure is the fallback if tests show throttling | R12 restated in TWK-REQ-001 v0.4; cool-hours scheduling added as a design rule in TWK-PRC-001 v0.4; TWK-CAL-001 v0.2 [F6]: at risk to met (69.1 °C, 15.9 K margin at light load). The enclosure fallback depends on TRL 4 tests and is on hold |

No geometry changed, so `cad/src/model.py`, `bom/bom.csv` prices and drawing TWK-DWG-001 (Rev P1) are unchanged in content; the model, drawing and media were regenerated only for the site address change. No reworded pitch or problem line was recommended, so the `pitch` and `problem` text in `project.yaml` and `README.md` stay as they were.

*Table 2. Items left open on 2026-09-25 (O2 decided by Amish on 2026-10-02).*

| # | Item | Status |
| --- | --- | --- |
| O2 | Co-design partner outside the lab (a small water utility, a makerspace or a municipal team). No recommendation was made on 2026-09-25. | Decided by Amish, 2026-10-02 (TWK-DEC-001): the first candidate to approach is a small municipal water utility in the Dallas and Fort Worth area, found through the Texas Water Utilities Association, with Dallas Makerspace as the build and test partner |

## Consequences

- Requirement status (TWK-CAL-001 v0.2, Table 2): 0 not met, 0 at risk, 8 met by calculation, 7 met by design, 1 not verifiable at TRL 3 (R13, setup time). Before: 2 not met (R1, R14), 1 at risk (R12).
- The R14 margin is small ($10) and rests on indicative prices, not supplier quotes.
- R12 is met on assumed values for the processor's thermal resistance and throttle point; only a TRL 4 thermal test can confirm them.
- Cross-repo: FieldNode nodes must accept LoRaWAN adaptive data rate commands for R1 to hold. This is listed under "Cross-repo actions" in `docs/REVIEW.md`; no other repo was edited.
- TRL 4 work implied by these decisions (a timed setup trial, thermal and packet-loss tests, supplier quotes, a trial of the enclosure fallback) is decided in principle but on hold, because TRL 4 is on hold by Amish's instruction.

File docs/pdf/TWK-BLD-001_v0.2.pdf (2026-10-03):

T W I N K I T · B U I L D P L A N

# TwinKit prototype build plan

Design Molecule Lab · designmolecule.com

D O C U M E N T CO N T RO L

Document ID | TWK-BLD-001 | Version | 0.2
Status | Draft | Date | 2026-10-02
Author | Amish Chadha | License | CERN-OHL-S-2.0
Project TRL | TRL 3 | Proof of concept
Repository | github.com/BoujeeEnjinia1701/twinkit
Source | docs/05-build-plan.md @ uncommitted

R EV I S I O N H I STO RY

Version | Date | Author | Change
0.2 | 2026-10-02 | Amish Chadha | Concentrator, antenna and safety stop S5 name the US915 band chosen for the first build (TWK-DEC-001, 2026-10-02); no picture changed
0.1 | 2026-10-02 | Amish Chadha | First build plan; design made constructable (TWK-DDR-003)

D R A F T · N O T F O R F A B R I C A T I O N

## TwinKit prototype build plan

Plan, not yet built. How to build the first proof-of-concept prototype, component by component. Building and testing to it is TRL 4 work. Decisions still to be made are kept in the design decisions register (docs/06-design-decisions.md), not here.

### 1. What you are building


Figure 1. Every component pulled apart and numbered in build order.
The prototype is one TwinKit gateway on a bench: an aluminium plate on rubber feet carrying a short DIN rail, with five bought DIN modules clipped onto the rail from left to right. They are the input fuse and terminal blocks, the gateway enclosure that holds the single-board computer and the radio concentrator, the 12 V to 5 V converter, the backup (UPS) module, and a small battery box that holds the backup pack. An end stop at each end keeps the modules from sliding. Figure 1 shows the 20 components in the order you make or fit them. Five are made or worked in a small workshop: the plate is cut, drilled and tapped; the rail is cut and drilled; the enclosure base, the enclosure cover and the battery box base are bought and then cut or drilled. Everything else is bought and fitted with screws, clips and screw terminals. No soldering and no circuit board work is needed. The parts cost about USD 334 from the bill of materials.

Safety: The prototype holds a 12.8 V lithium iron phosphate (LiFePO4) pack of about 19 Wh with its own protection board and fuse. Keep the pack lead unplugged from the UPS module until section 6 says otherwise, charge it only through the UPS module, and never leave a first build charging unattended. Use a certified, double-insulated 12 V adapter; nothing in this build touches mains wiring. Cut aluminium edges are sharp: deburr everything. A network gateway is an attack surface: keep it off the internet until its default credentials are changed.

### 2. What changed to make it buildable

The concept showed what the gateway does; some of its parts could not be made, fitted or held as drawn. Each change below keeps what the gateway does, and all of them are recorded in decision record TWK-DDR-003, open for Amish's review.
Table 1. Changes from the concept.
Component | The concept had | The buildable design has | Why
Backup pack | Drawn inside the UPS module | Its own 3-module battery box beside a 3-module UPS module (Figures 13 and 14) | Two bought parts cannot be put one inside the other
Enclosure vents | Slots in the two end walls, 2 mm from the neighbouring modules | The same slots in the two long walls (Figure 8) | Air can reach them; same area and spacing, so the temperature results stand
Computer and HAT | Floating inside the enclosure | Brass standoffs on the floor, a second set between the boards, and a header extender (Figure 10) | Every board is held by its own four holes
Antenna | Sitting on the cover with no hole | An SMA bulkhead through a 6.5 mm hole, with a pigtail to the HAT (Figure 12) | How a bulkhead is fitted
Cable entries | None | A network feed-through coupler and a power gland in the front wall (Figure 9)

The network and power leads need a way in

DIN rail | A U channel with no fixing | A true top-hat rail, 350 mm long, on three M4 screws (Figures 4 and 6)

Every module's clip hooks under the top-hat flanges

Ends of the rail | Nothing | Two screw-clamped end stops (Figure 16)

Nothing slides along the rail

Bench plate | Plywood or aluminium, no feet 6 mm aluminium, tapped for the rail, on
| | four rubber feet (Figures 2 and 3)

A tapped hole holds the rail with no nuts underneath

Wiring | No path for power or the power-fail signal into the enclosure | A USB-C power lead and a power-fail pair through the power gland (Figure 15)

The computer gets its power and its warning of an outage

### 3. Making the components

Make and check each component before the assembly step that needs it. Sizes are in millimetres. "Front" is the long side of the modules that faces you on the bench, where the cable entries are; "left" and "right" are as seen from the front. Workshop tolerance is 0.5 mm unless a step says otherwise; drawings do not carry tolerances before TRL 4.

### 3.1 Bench plate

Figure 2. Bench plate making sketch (TWK-DWG-101).

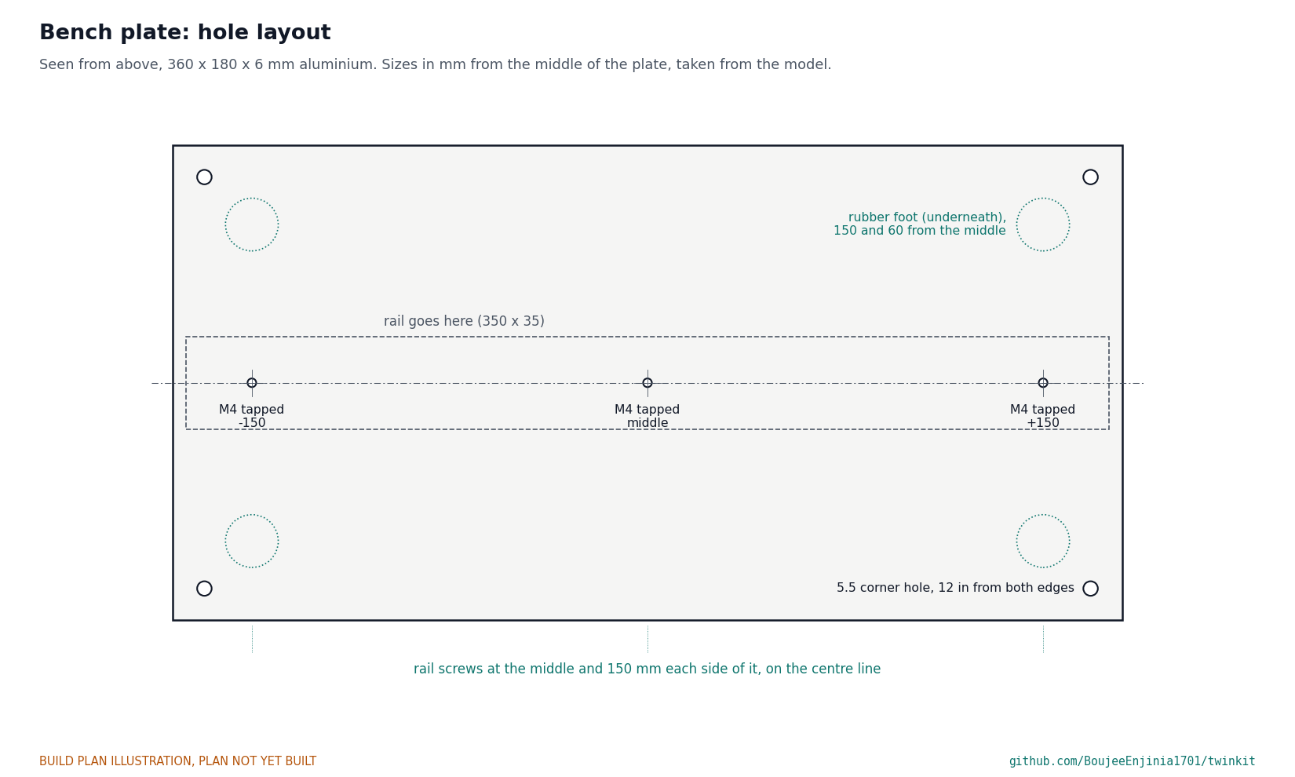
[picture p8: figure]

Figure 3. Every hole, measured from the middle of the plate, with the rubber feet underneath shown dotted.
What it is and what it is made from. The flat base that the rail is screwed to. It stands on the bench on four rubber feet, or screws to a wall or cabinet later through its corner holes. Aluminium sheet 6 mm thick, 5083, 6082 or 6061 class, cut to 360 x 180 mm.
How to make it.
Cut the blank to 360 x 180 mm, square. File the edges and round the corners to about 3 mm.
Scribe a centre line along the long side and mark the middle of it.
Rail holes: on the centre line, at the middle and 150 each side of it. Drill 3.3 mm right through and tap M4, keeping the tap square to the plate.
Corner holes: four 5.5 mm holes, 12 in from each long and each short edge.
Deburr every hole on both faces.
Clean the underside and press on four stick-on rubber feet, 20 across, centred 150 each side of the middle and 60 each side of the centre line (step 1).

How it fits the parts next to it.

1.
2.
3.

4.
5.
6.

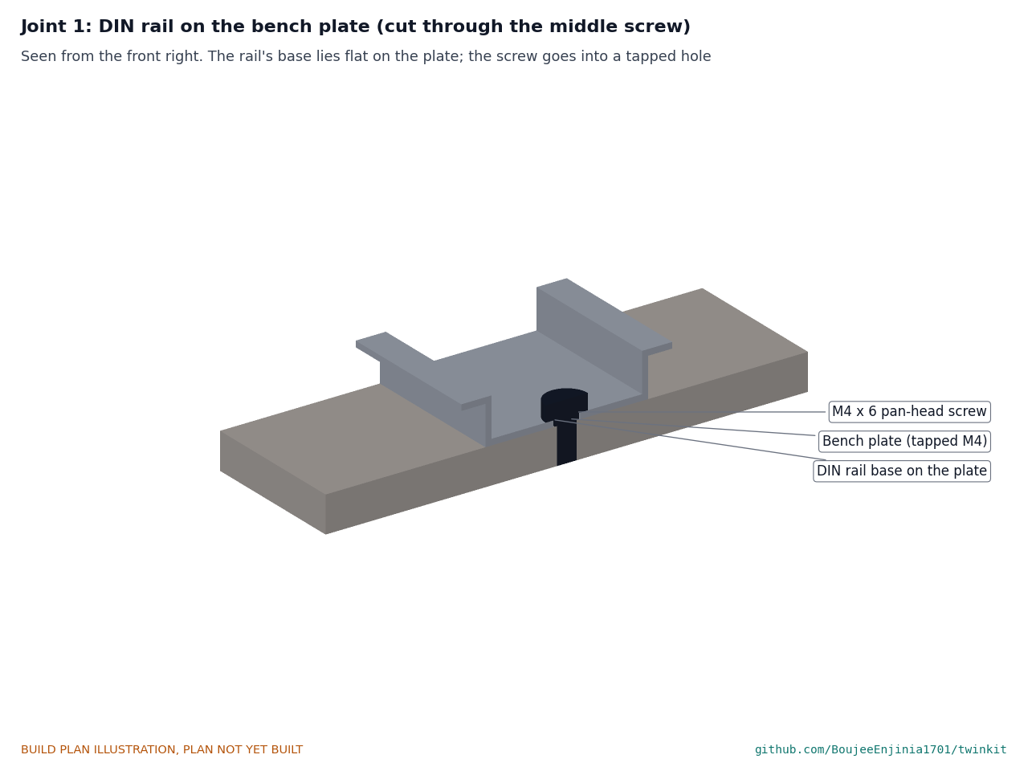
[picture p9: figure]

Figure 4. The rail's base lies flat on the plate; an M4 pan-head screw passes through it into a tapped hole.
The rail's 27 mm wide base lies flat on the top face, along the centre line, with each end 5 in from the plate's short edges. Three M4 x 6 pan-head screws hold it, one in each tapped hole. Nothing else touches the plate: every module stands on the rail's flanges, 7.5 above it.
Check before moving on. An M4 screw runs into each tapped hole by hand. On a flat bench the plate rocks on none of its feet.

### 3.2 DIN rail

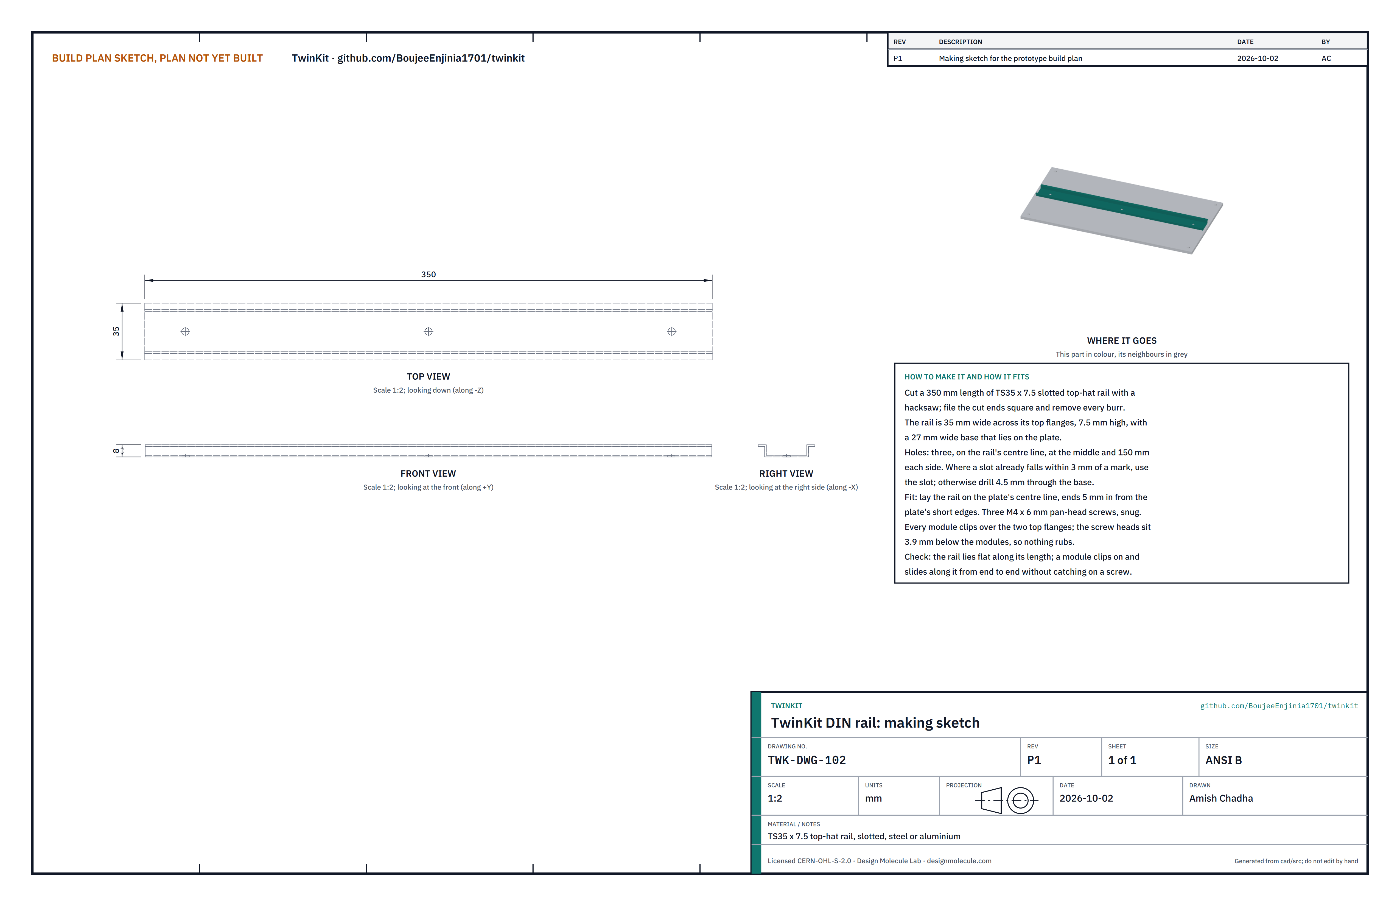
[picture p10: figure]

Figure 5. DIN rail making sketch (TWK-DWG-102).
What it is and what it is made from. The standard rail that every module clips onto. TS35 x 7.5 slotted top-hat rail, steel or aluminium: 35 wide across its top flanges, 7.5 high, with a 27 wide base.
How to make it.
Cut a 350 length with a hacksaw. File both ends square and remove every burr, inside the channel too.
Mark three holes on the centre line of the base: at the middle and 150 each side of it.
Where a factory slot already falls within 3 of a mark, use the slot. Otherwise drill 4.5 through the base.

How it fits the parts next to it.

1.
2.
3.

Figure 6. Seen along the rail, cut across. A hook on each side of the module's base reaches under the rail's flange; the base sits on top of the flanges.
The base is screwed to the plate (Figure 4). Every module hooks its back edge under one flange and snaps its front edge over the other. The screw heads sit 3.9 below the modules' bases, so a module slides along the rail without catching.
Check before moving on. The rail lies flat along its whole length; a module clips on and slides from end to end without catching on a screw.

### 3.3 Gateway enclosure base, cut and drilled

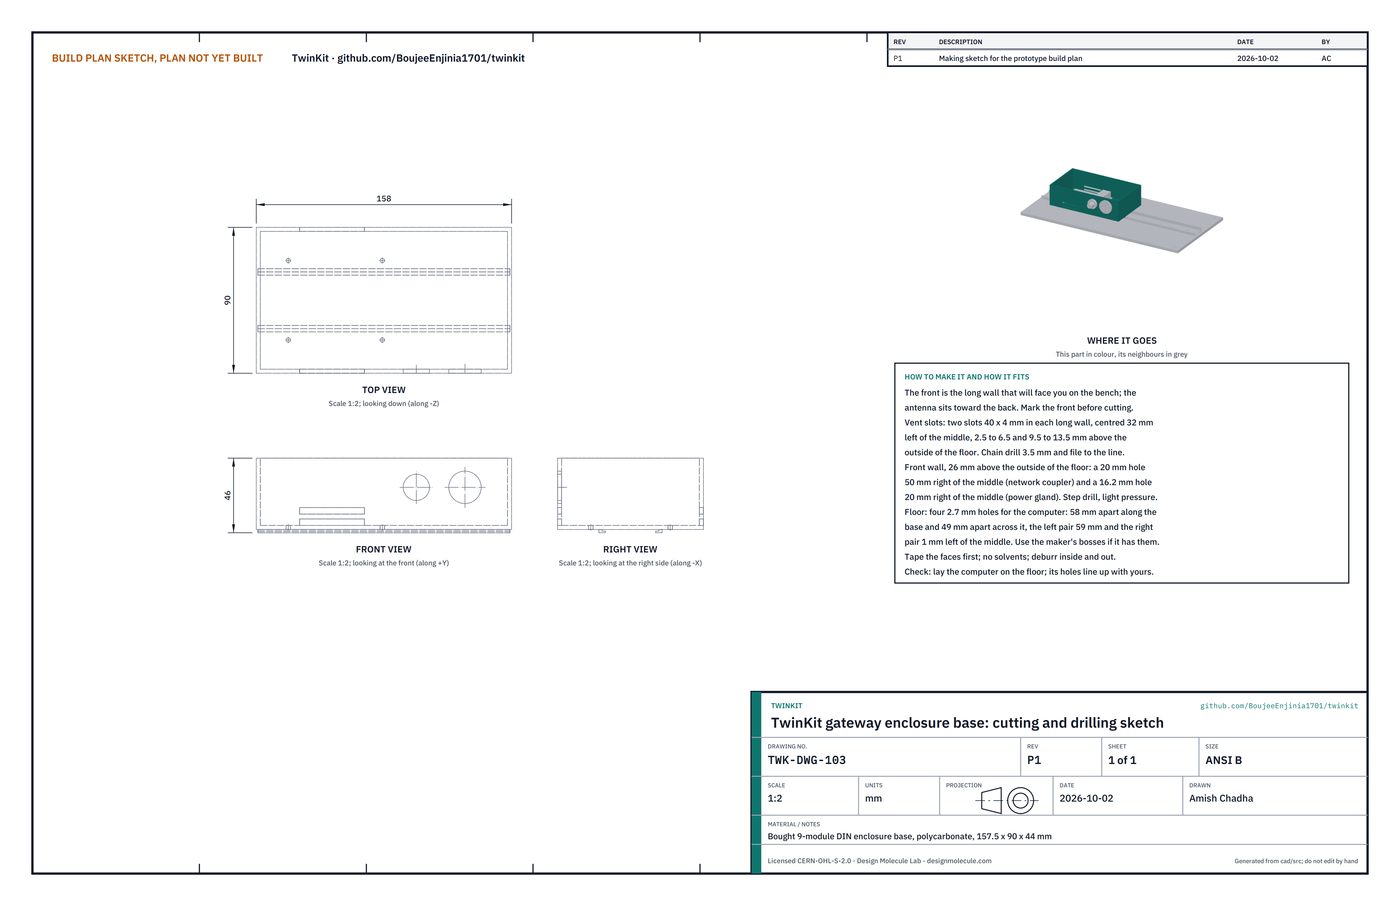
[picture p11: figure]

Figure 7. Enclosure base cutting and drilling sketch (TWK-DWG-103).

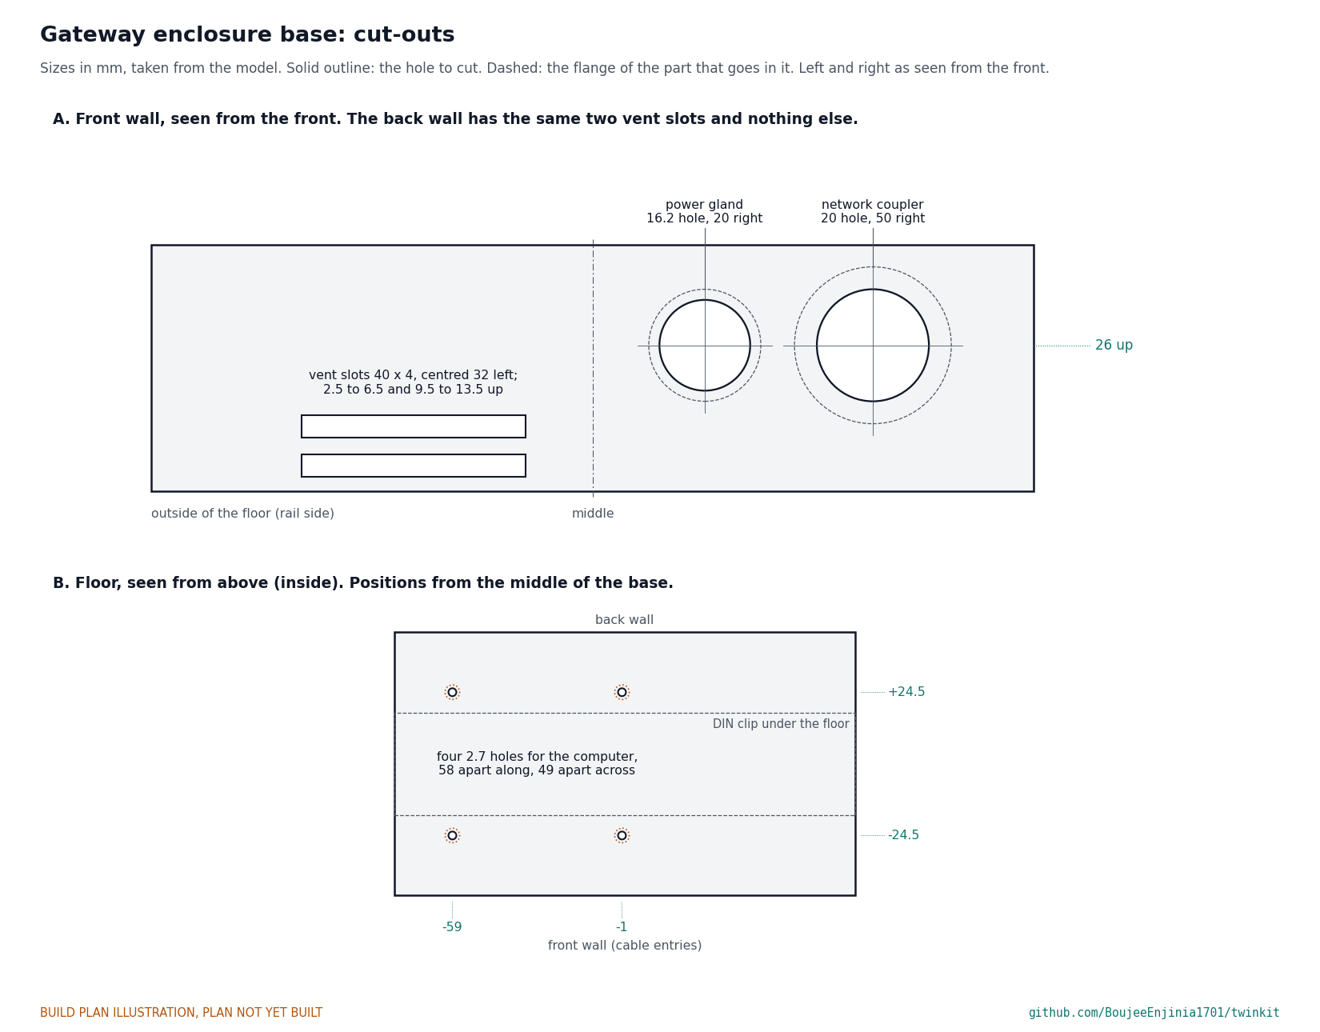
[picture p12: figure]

Figure 8. A: the front wall, with the vent slots, the network coupler hole and the power gland hole. B: the floor, with the four holes for the computer.
What it is and what it is made from. The lower half of a bought 9-module DIN enclosure for a single-board computer: polycarbonate, 157.5 long, 90 deep and 44 high, with a DIN clip moulded under its floor. It holds the computer and the concentrator. You cut vent slots in both long walls, two entry holes in the front wall and four holes in the floor.
How to make it.
Decide which long wall is the front and mark it. Cover the walls and floor with masking tape.
Vent slots, both long walls: two slots 40 x 4, centred 32 left of the middle, from 2.5 to 6.5 and from 9.5 to 13.5 above the outside of the floor (Figure 8, A). Chain drill with a 3.5 drill and file to the line. Skip any slot the maker has already moulded in the same place.
Front wall, both centred 26 above the outside of the floor: a 20 hole 50 right of the middle for the network coupler, and a 16.2 hole 20 right of the middle for the power gland. Pilot 3 at low speed, then open out with a step drill, light pressure, with a block of wood behind the wall. Check each size on the part's datasheet before the last step.

1.
2.

3.

Floor: four 2.7 holes for the computer, 58 apart along the base and 49 apart across it, the left pair 59 left of the middle and the right pair 1 left of it, 24.5 each side of the centre line (Figure 8, B). If the enclosure has moulded bosses for the computer, use them instead and skip this step.
Deburr every cut inside and out, peel the tape and clean with water and mild soap only; solvents craze polycarbonate.

How it fits the parts next to it.

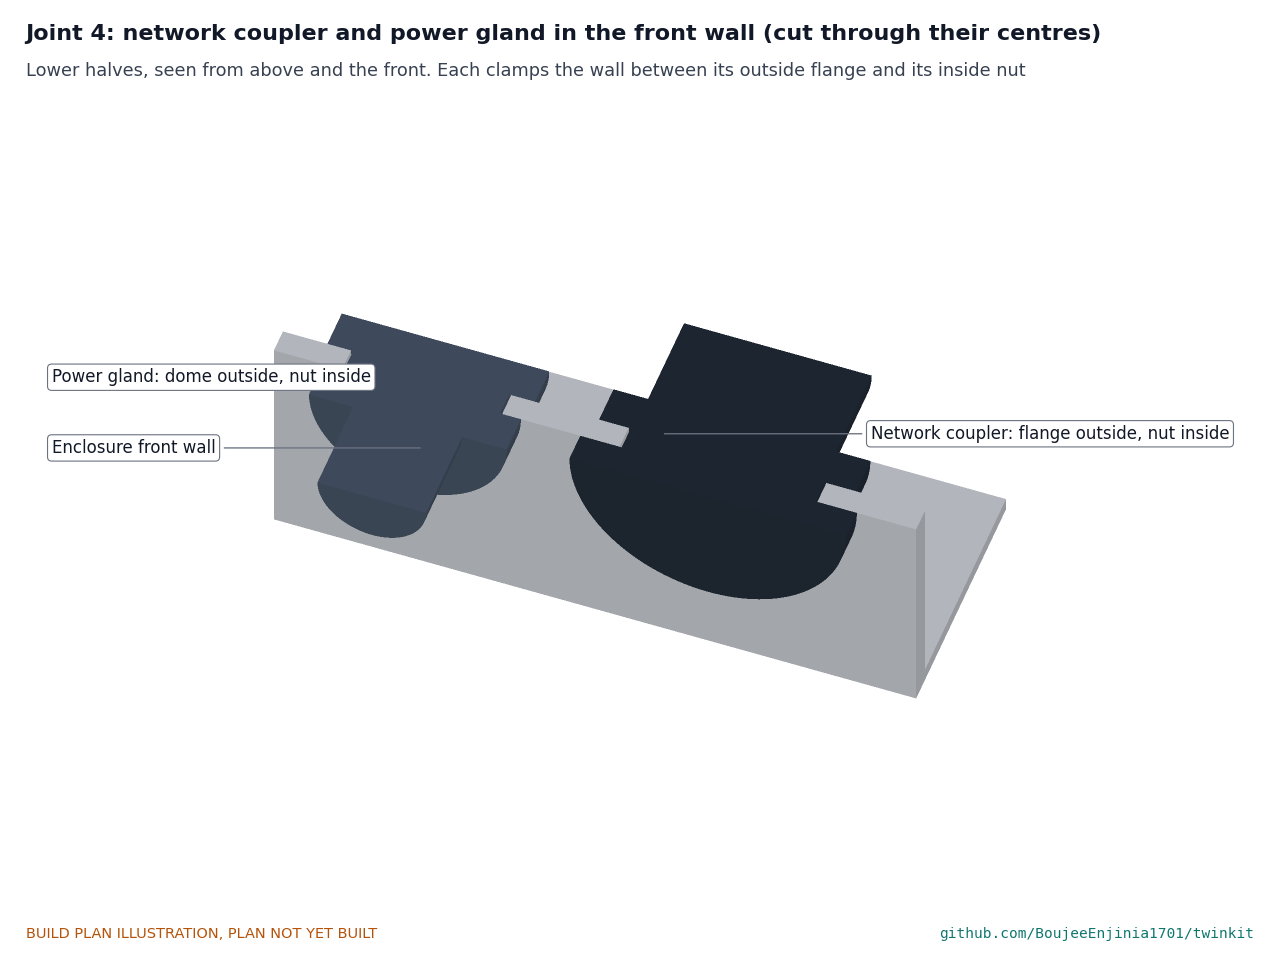
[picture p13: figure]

Figure 9. Each entry clamps the wall between its outside flange and its inside nut.
The network coupler and the power gland go in from outside, flange and seal outside, nut inside (step 3). They sit 13.5 or more clear of both boards.

4.

5.

Figure 10. At each of the four corners: floor, 6 mm standoff, computer, 16 mm standoff, HAT. The header extender joins the two boards.
Four 6 mm brass standoffs stand on the floor holes, each held by an M2.5 pan-head screw from underneath (step 4). The screw heads sit 4.75 outside the rail's flanges, so they never touch the rail. The computer sits on the standoffs with its network socket toward the coupler, and four 16 mm standoffs screw into the lower ones through the computer's holes. The HAT sits on the 16 mm standoffs and on a header extender pushed onto the computer's 40-pin header, and is held by four M2.5 screws. The active cooler on the computer clears the HAT by 8. The DIN clip under the floor hooks onto the rail (Figure 6).
Check before moving on. Lay the computer on the floor: its four holes line up with yours. No crack runs out from any hole under a bright lamp.

### 3.4 Gateway enclosure cover, drilled

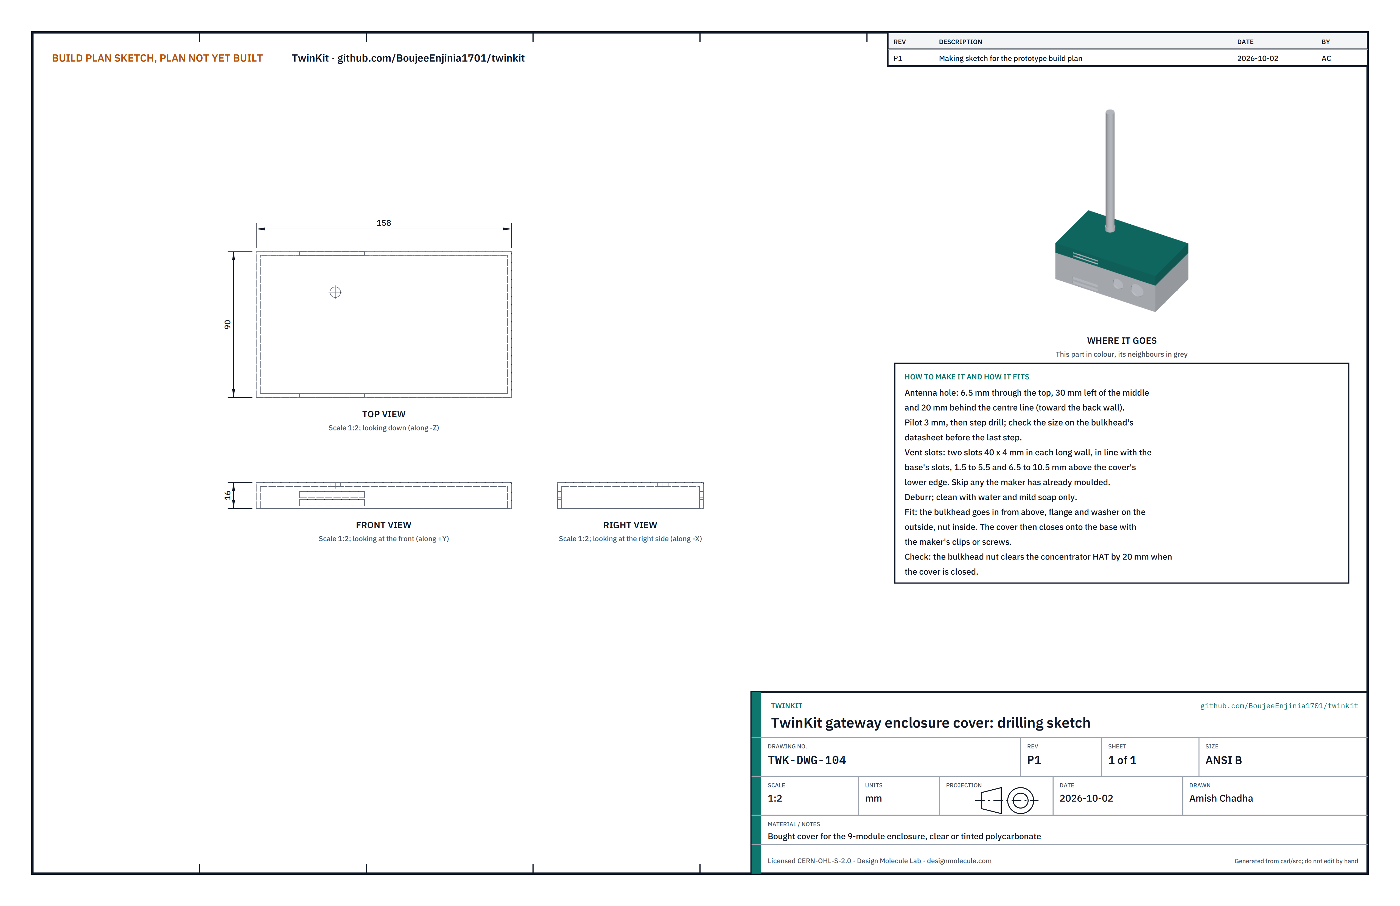
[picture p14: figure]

Figure 11. Enclosure cover drilling sketch (TWK-DWG-104).
What it is and what it is made from. The upper half of the same bought enclosure, clear or tinted polycarbonate, 16 deep, closing onto the base with the maker's clips or screws. It carries the antenna.
How to make it.
Antenna hole: 6.5 through the top, 30 left of the middle and 20 behind the centre line (toward the back wall). Pilot 3, then step drill, with wood behind.
Vent slots, both long walls: two slots 40 x 4 in line with the base's slots, from 1.5 to 5.5 and from 6.5 to 10.5 above the cover's lower edge. Skip any the maker has already moulded.
Deburr and clean with water and mild soap.

How it fits the parts next to it.

1.

2.

3.

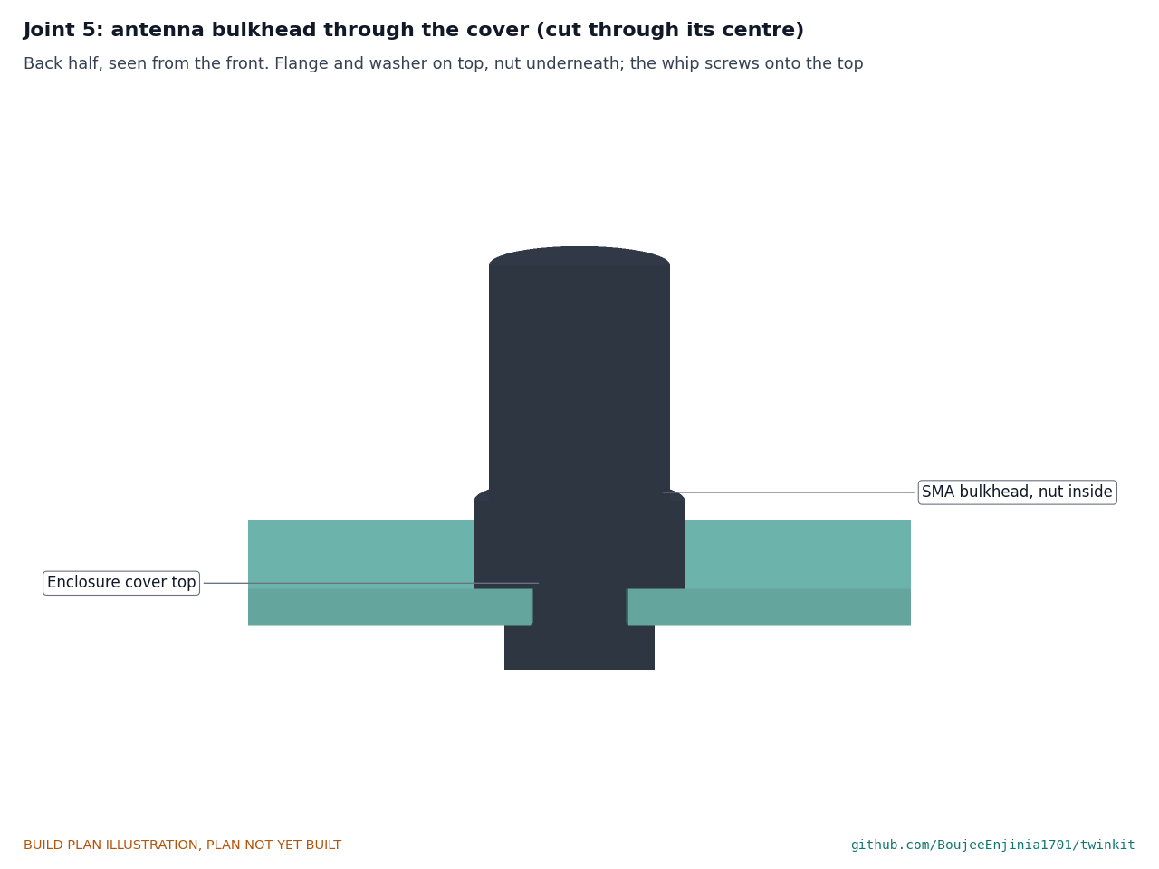
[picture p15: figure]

Figure 12. The SMA bulkhead's flange and washer sit on top of the cover, its nut underneath; the whip screws onto the top.
The bulkhead goes in from above with its nut inside (step 9). A U.FL pigtail runs from it to the HAT's antenna socket. The inside nut clears the HAT by about 22 when the cover is closed. The cover's lower edge sits on the base's upper edge all round (step 10).
Check before moving on. The bulkhead does not turn when the whip is screwed on finger tight.

### 3.5 Battery box base, drilled

Figure 13. Battery box base drilling sketch (TWK-DWG-105).
What it is and what it is made from. The lower half of a bought empty 3-module DIN enclosure, polycarbonate, 52.5 long, 90 deep and 44 high, with its own cover. It holds the backup pack on the rail beside the UPS module. One hole is drilled in its front wall.
How to make it.
A 12.2 hole in the middle of the front wall, 26 above the outside of the floor, for the M12 gland. Pilot 3, then step drill.
Deburr inside and out.
Stick a hook-and-loop pad, 38 x 60, to the middle of the floor, long side front to back. Its mate goes on the underside of the pack.

How it fits the parts next to it.

1.

2.
3.

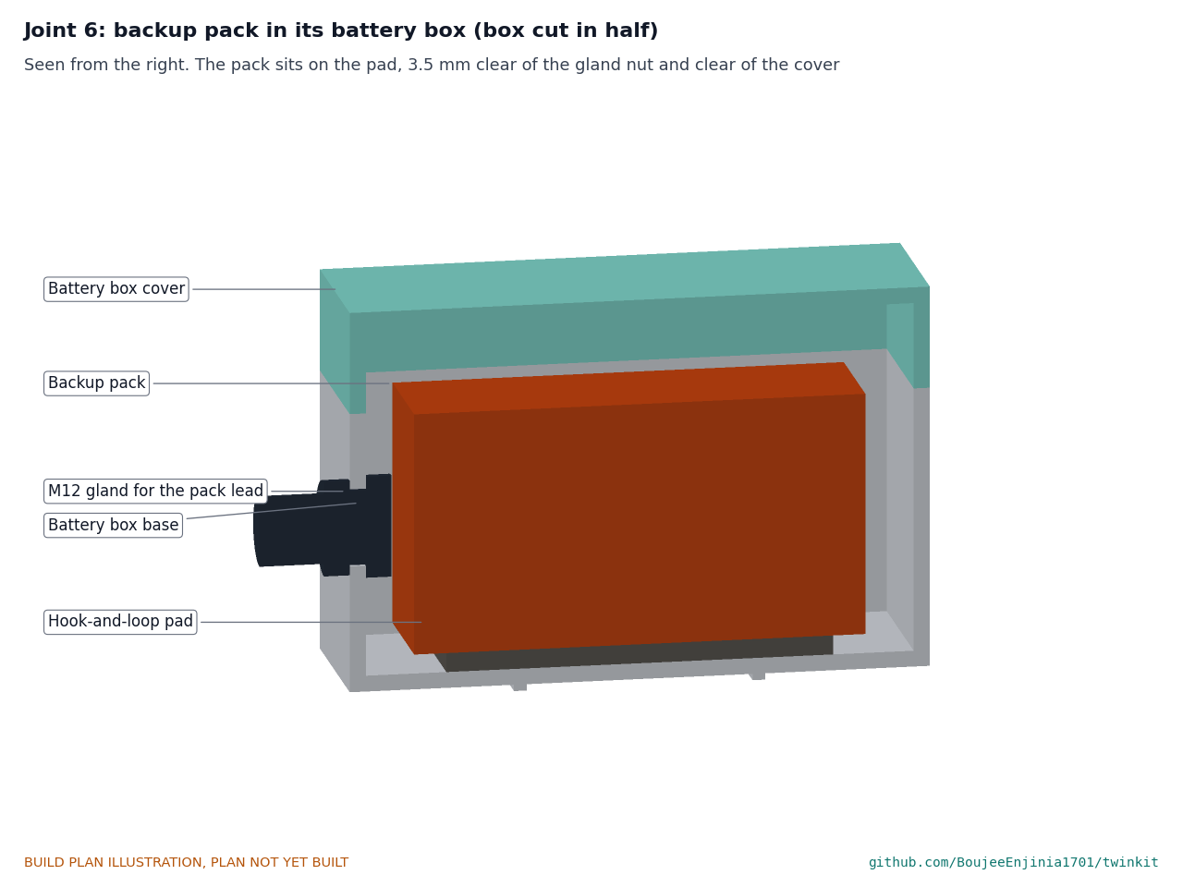
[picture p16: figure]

Figure 14. The pack sits on the pad, 3.5 clear of the gland nut and clear of the cover.
The pack (no larger than 38 x 70 x 38) lies on the pad, long side front to back, with its lead out through the gland. The gland goes in from outside with its seal outside and its nut inside. The cover closes without touching the pack. The box clips onto the rail 2 to the right of the UPS module.
Check before moving on. The pack's lead reaches the gland without strain, and the cover closes without force.

### 3.6 Wiring

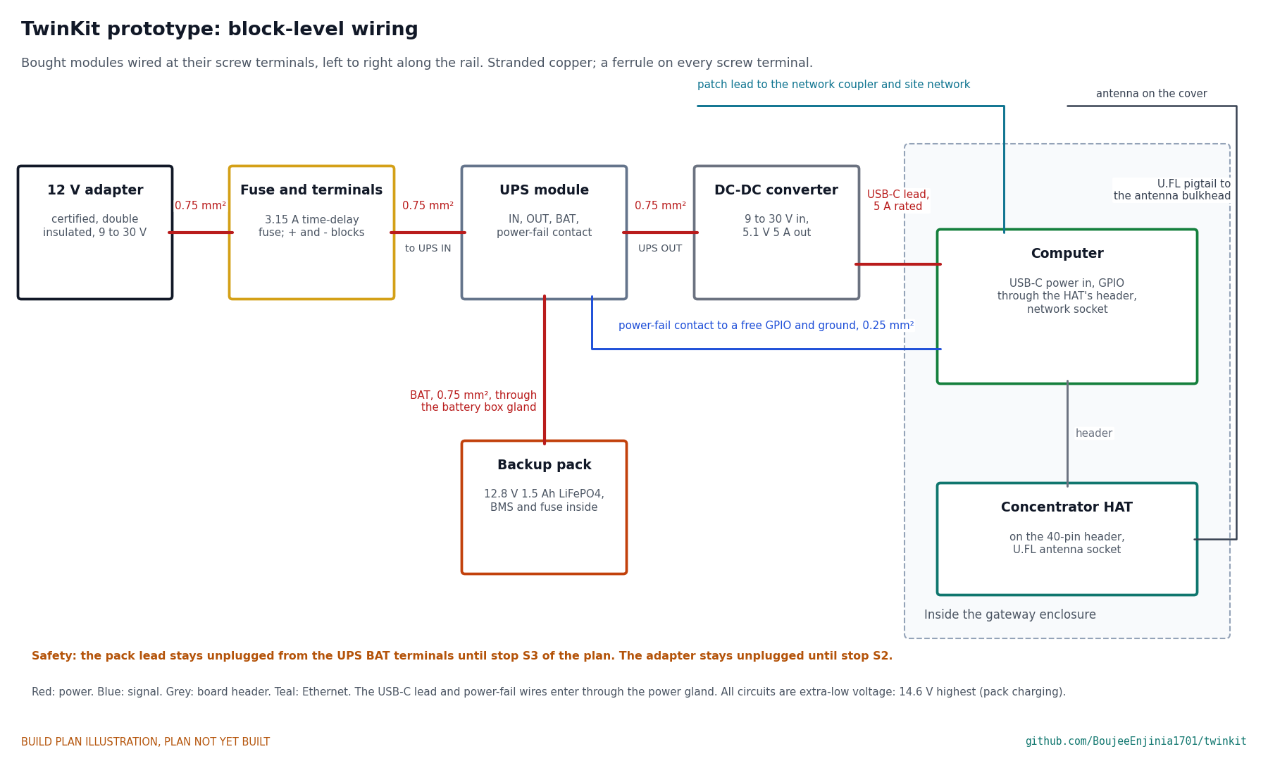
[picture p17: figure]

Figure 15. Block-level wiring with wire sizes. Every connection is at a bought module's screw terminal or plug; no circuit board is made.
Wire it like this, with stranded copper and a ferrule on every screw terminal. Run the wires along the front of the modules and tie them to adhesive tie mounts on the plate.
Adapter lead to the fuse holder and the two terminal blocks: 0.75 mm² (18 AWG), positive through the 3.15 A time-delay fuse.
Terminal blocks to the UPS module's input: 0.75 mm².
UPS module's output to the converter's input: 0.75 mm².
Converter's 5.1 V output to the computer: the USB-C power lead with bare ends, rated 5 A, in through the power gland.
UPS module's power-fail contact to a free GPIO pin and a ground pin on the HAT's pass-through header: a 0.25 mm² (24 AWG) twisted pair, through the same gland (the gland's insert has two holes).
Pack lead from the battery box gland to the UPS module's battery terminals: 0.75 mm². Leave it unplugged at the UPS end until stop S3 (section 6).
Patch lead from the computer's network socket to the inside of the network coupler (done in step 6).
U.FL pigtail from the HAT to the antenna bulkhead (done in step 10).

Check before moving on. With the adapter unplugged and the pack lead loose, every wire continues end to end and the adapter's positive does not read as a short (under 10 Ω) to ground. Every wire is labelled at both ends.

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
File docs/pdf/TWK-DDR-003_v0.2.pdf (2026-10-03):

T W I N K I T · D E S I G N D E C I S I O N R E C O R D

# TwinKit design for construction

### Design Molecule Lab · designmolecule.com

D O C U M E N T CO N T RO L

Document ID | TWK-DDR-003 | Version | 0.2
Status | Draft | Date | 2026-10-02
Author | Amish Chadha | License | CERN-OHL-S-2.0
Project TRL | TRL 3 | Proof of concept
Repository | github.com/BoujeeEnjinia1701/twinkit
Source | docs/decisions/0003-design-for-construction.md @ uncommitted

R EV I S I O N H I STO RY

Version | Date | Author | Change
0.2 | 2026-10-02 | Amish Chadha | Accepted by Amish on 2026-10-02 (TWK-DEC-001, item 1)
0.1 | 2026-10-02 | Amish Chadha

Changes that make the concept physically buildable, with the reason for each; made under Amish's 2026-09-30 instruction to make the design physically buildable; open for his review

D R A F T · N O T F O R F A B R I C A T I O N
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

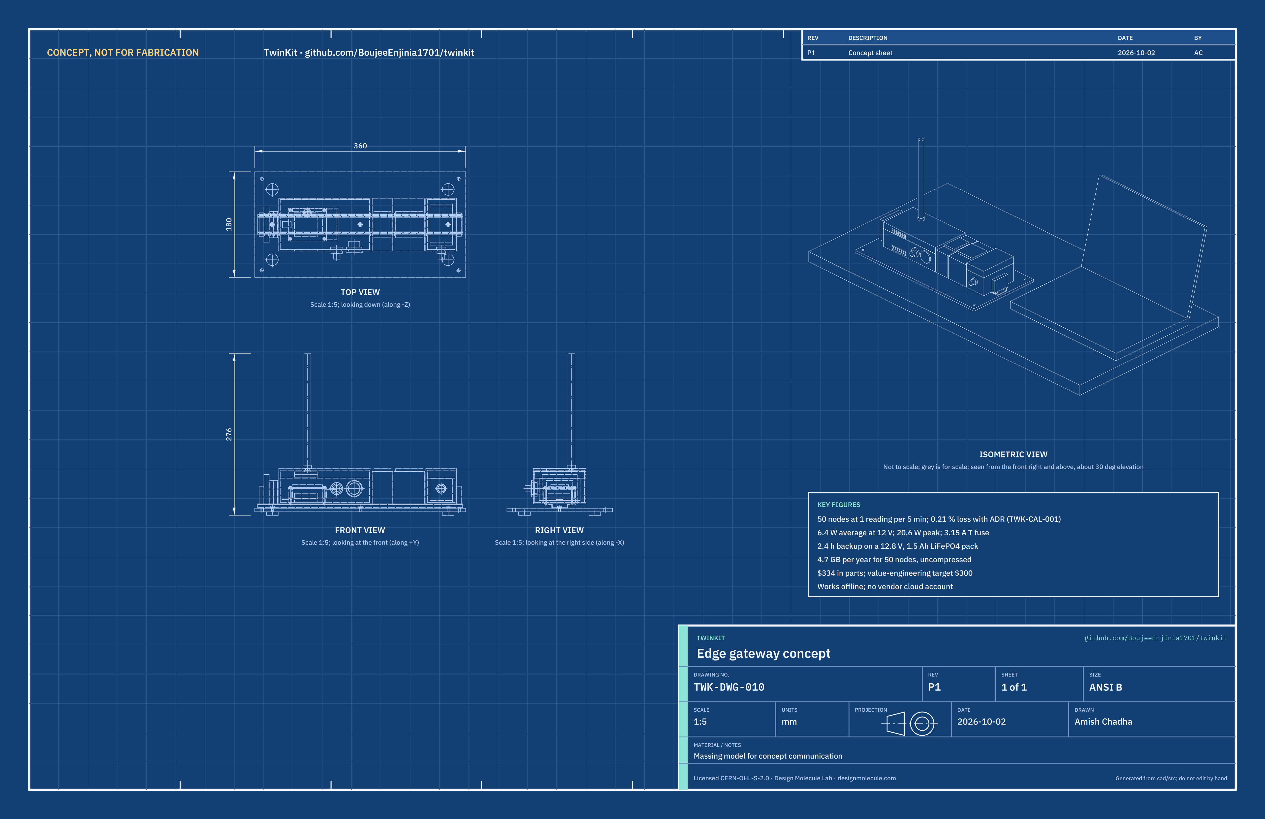
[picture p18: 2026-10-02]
media/concept-blueprint.png

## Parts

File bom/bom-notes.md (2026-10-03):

# BOM notes

- Rows 1 to 13 and 17 to 21 are numbered to match the callouts in `media/exploded.png`. Rows 14 to 16 are software and have no callout. Rows 17 to 21 were added on 2026-10-02 to make the design buildable (TWK-DDR-003).
- Costs are indicative single-unit prices in USD, checked against typical retail listings in September 2026 but not quoted by a supplier. Prices for single-board computers and radio modules change often.
- Every line is priced. Value-engineering target: USD 300 (`budget_usd`, a hypothetical control target, not a limit; Amish, 2026-10-01). Estimated cost of the constructable design: USD 334.00 (USD 34 over the target; TWK-CAL-001 [I1, I2]). The concept was USD 290.00. Amish raised `budget_usd` from $200 to $300 on 2026-09-25 (TWK-DDR-002).
- Design for construction (TWK-DDR-003): line 1 is now 6 mm aluminium ($6 to $15), line 2 is cut to 350 mm, line 3 is cut and drilled by the builder, line 11 is a 3-module UPS with no internal battery, and line 12 has a maximum size so it fits the battery box (line 17).
- TRL 3 changes: line 11 now specifies a buck-boost charger that charges the 12.8 V pack from a 9 to 30 V input ($25 to $30); line 13 fuse raised from 2 A to 3.15 A time-delay (TWK-CAL-001, section D).
- Choices marked "decided by Amish 2026-09-25" follow TWK-DDR-001 and TWK-DDR-002. The first build is US915 (line 7 and the 915 MHz antenna of line 9), decided by Amish on 2026-10-02 (TWK-DEC-001); prices are unchanged.
- A 12 V DC supply (mains adapter or existing 12 V system), a laptop or phone to view the dashboard, and a sensor node such as FieldNode are assumed to be on hand and are not included.
- Line 7 (US915, decided 2026-10-02): priced from the Seeed Studio WM1302 SPI US915 module and Seeed WM1302 Raspberry Pi HAT; the parts alone are about USD 60 and the line stays at USD 80 for shipping from two sellers and a HAT that fits a Pi 5 class computer. Line 9 stays at USD 12 and is not yet checked against a named supplier.

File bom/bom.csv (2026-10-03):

item | qty | spec | supplier | unit_cost_usd | make_buy | notes
1 Bench mounting plate | 1 | 360 x 180 x 6 mm aluminum sheet (5083, 6082 or 6061), three M4 tapped rail holes and four 5.5 mm corner holes | Self | 15.00 | make | Material cost only (offcut); omit when mounting in an existing cabinet. Was plywood or aluminum, $6 (TWK-DDR-003)
2 DIN rail | 1 | TS35 x 7.5 mm top-hat rail, slotted, steel or aluminum, cut to 350 mm | Electrical wholesaler | 4.00 | buy | Indicative price; 350 mm (was 320 mm) to carry the battery box and end stops (TWK-DDR-003)
3 Gateway enclosure base | 1 | 9-module DIN rail enclosure for a single-board computer, polycarbonate, about 157.5 x 90 x 60 mm, DIN clip in the base; vent slots, cable entries and board holes cut by the builder | Electrical or electronics distributor | 18.00 | buy | Indicative price for base and cover together
4 Gateway enclosure cover | 1 | Clear or tinted cover with SMA bulkhead hole, supplied with line 3 | Electrical or electronics distributor | 0.00 | buy | Included in line 3
5 Single-board computer | 1 | Quad-core Arm SBC with 4 GB RAM, Ethernet, Wi-Fi, 40-pin header (Raspberry Pi 5 class) | Authorized reseller | 65.00 | buy | Indicative price; decided by Amish 2026-09-25 per TWK-DDR-002
6 Active cooler | 1 | Clip-on heat sink and fan for line 5 | Authorized reseller | 5.00 | buy | Indicative price
7 LoRaWAN concentrator HAT | 1 | SX1302 or SX1303 8-channel concentrator on a 40-pin HAT, US915 version for the first build (TWK-DEC-001, 2026-10-02); EU868 or another band version for other regions | Electronics distributor | 80.00 | buy | Indicative price; SX1302 or SX1303 class; decided by Amish 2026-09-25 per TWK-DDR-002. Basis: Seeed Studio WM1302 SPI module, US915 version, and Seeed WM1302 Raspberry Pi HAT; the HAT was listed at USD 20.79 at RobotShop and the module at USD 39 list (USD 22 on sale) at a reseller, so the parts alone are about USD 60; USD 80 kept to cover shipping from two sellers and a HAT that fits the Raspberry Pi 5 class computer, since the Seeed HAT is listed for boards up to the Pi 4B
8 microSD card | 1 | 64 GB high-endurance, A2 class | Electronics retailer | 15.00 | buy | Indicative price; write load and wear in TWK-CAL-001 section B
9 LoRa antenna and SMA bulkhead | 1 | 3 dBi whip for the chosen band, SMA bulkhead with U.FL pigtail | Electronics distributor | 12.00 | buy | Indicative price
10 DC-DC converter | 1 | DIN rail, 9 to 30 V in, 5.1 V 5 A out | Electrical or electronics distributor | 18.00 | buy | Indicative price
11 DIN UPS module | 1 | DIN rail DC UPS, 3 modules wide, without an internal battery, for an external 12.8 V LiFePO4 pack: 9 to 30 V input, buck-boost CC/CV charger to 14.6 V at 0.5 A or less, pass-through output, power-fail signal output | Electrical or electronics distributor | 30.00 | buy | Indicative price; module on a DIN carrier if no DIN version is found; charger must boost from a 9 to 12 V input (TWK-CAL-001 section D); the pack sits in its own box | line 17 (TWK-DDR-003)
12 LiFePO4 backup pack | 1 | 12.8 V 1.5 Ah (19.2 Wh) with built-in BMS and fuse, 4S 18650 cells in a 2 x 2 block, no larger than 38 x 70 x 38 mm, with a lead of about 300 mm | Battery supplier | 25.00 | buy | Indicative price; off-the-shelf pack with built-in BMS, decided by Amish 2026-09-25 per TWK-DDR-002
13 Terminal blocks and fuse | 1 | DIN terminal blocks, fuse holder with 3.15 A time-delay (T) 5 x 20 mm fuse, wire, cable glands | Electrical wholesaler | 12.00 | buy | Indicative price; fuse raised from 2 A to 3.15 A T by TWK-CAL-001 section D
14 Open-source software stack | 1 | LoRaWAN network server, MQTT broker, TimescaleDB time-series database, dashboard | Open source | 0.00 | make | No license cost; stack decided by Amish 2026-09-25 per TWK-DDR-002
15 TwinKit twin service and mapping schema | 1 | Python service and YAML schema linking sensor channels to model parts and calculations | Self | 0.00 | make | To be written under MIT license; schema fields decided by Amish 2026-09-25 per TWK-DDR-002
16 Example twin of FieldNode | 1 | Mapping file, expected-value curves and dashboard for one FieldNode | Self | 0.00 | make | FieldNode battery and solar charge; decided by Amish 2026-09-25 per TWK-DDR-002
17 Battery box | 1 | Empty 3-module DIN rail enclosure, about 52.5 x 90 x 60 mm, base and cover, polycarbonate | Electrical or electronics distributor | 8.00 | buy | Indicative price; holds line 12, which cannot fit inside a bought UPS module (TWK-DDR-003)
18 DIN rail end stops | 2 | Screw-clamp end stops for TS35 rail, about 8 mm wide | Electrical wholesaler | 1.50 | buy | Indicative price; stop the modules sliding along the rail (TWK-DDR-003)
19 Board mounting kit | 1 | 4 x M2.5 x 6 mm brass standoffs (female-female), 4 x M2.5 x 16 mm standoffs (male-female), 8 x M2.5 x 5 mm pan-head screws, 2 x 20 GPIO header extender about 10 mm | Electronics retailer | 5.00 | buy | Indicative price; holds the computer and HAT (TWK-DDR-003)
20 Cable entries | 1 | RJ45 feed-through coupler for a 20 mm round hole (panel nut, Cat 6), 0.15 m patch lead, M16 x 1.5 nylon cable gland IP68 with a two-hole sealing insert, M12 x 1.5 nylon cable gland IP68 for 3 to 6.5 mm cable | Electronics distributor | 10.00 | buy | Indicative price; Ethernet and power into the enclosure and the pack lead out of the battery box (TWK-DDR-003)
21 Fixings and wiring | 1 | 3 x M4 x 6 mm pan-head screws, 4 rubber feet 20 mm diameter x 6 mm, hook-and-loop pads, USB-C power lead with bare ends rated 5 A, 0.75 mm² and 0.25 mm² stranded wire, ferrules, adhesive cable-tie mounts and ties | Electrical wholesaler | 9.00 | buy | Indicative price (TWK-DDR-003)

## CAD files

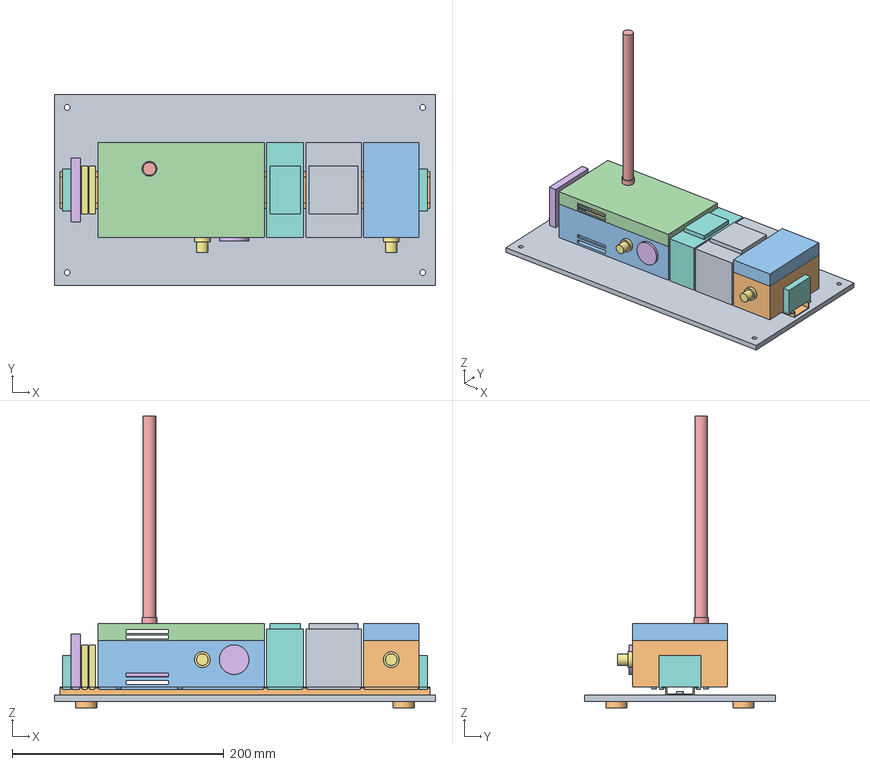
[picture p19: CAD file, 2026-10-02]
cad/step/twinkit-assembly.step
360.0 x 180.0 x 275.5 mm

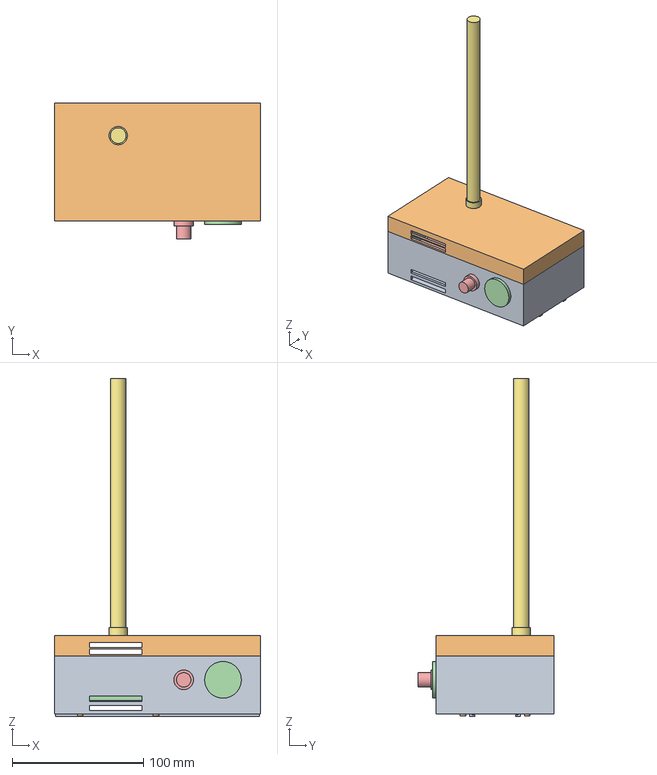
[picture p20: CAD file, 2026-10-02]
cad/step/gateway-enclosure.step
157.5 x 104.0 x 258.0 mm

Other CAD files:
cad/stl/gateway-enclosure.stl
cad/stl/twinkit-assembly.stl

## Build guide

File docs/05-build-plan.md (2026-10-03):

---
doc_id: TWK-BLD-001
title: TwinKit prototype build plan
project: TwinKit
doc_type: Build plan
version: "0.2"
status: Draft
date: '2026-10-02'
author: Amish Chadha
license: CERN-OHL-S-2.0
revisions:
  - version: "0.1"
    date: '2026-10-02'
    author: Amish Chadha
    change: First build plan; design made constructable (TWK-DDR-003)
  - version: "0.2"
    date: '2026-10-02'
    author: Amish Chadha
    change: Concentrator, antenna and safety stop S5 name the US915 band chosen for the first build (TWK-DEC-001, 2026-10-02); no picture changed
---

# TwinKit prototype build plan

**Plan, not yet built.** How to build the first proof-of-concept prototype, component by component. Building and testing to it is TRL 4 work. Decisions still to be made are kept in the design decisions register ([docs/06-design-decisions.md](06-design-decisions.md)), not here.

## 1. What you are building

Figure 1. Every component, pulled apart and numbered in build order

*Figure 1. Every component pulled apart and numbered in build order.*

The prototype is one TwinKit gateway on a bench: an aluminium plate on rubber feet carrying a short DIN rail, with five bought DIN modules clipped onto the rail from left to right. They are the input fuse and terminal blocks, the gateway enclosure that holds the single-board computer and the radio concentrator, the 12 V to 5 V converter, the backup (UPS) module, and a small battery box that holds the backup pack. An end stop at each end keeps the modules from sliding. Figure 1 shows the 20 components in the order you make or fit them. Five are made or worked in a small workshop: the plate is cut, drilled and tapped; the rail is cut and drilled; the enclosure base, the enclosure cover and the battery box base are bought and then cut or drilled. Everything else is bought and fitted with screws, clips and screw terminals. No soldering and no circuit board work is needed. The parts cost about USD 334 from the bill of materials.

> **Safety:** The prototype holds a 12.8 V lithium iron phosphate (LiFePO4) pack of about 19 Wh with its own protection board and fuse. Keep the pack lead unplugged from the UPS module until section 6 says otherwise, charge it only through the UPS module, and never leave a first build charging unattended. Use a certified, double-insulated 12 V adapter; nothing in this build touches mains wiring. Cut aluminium edges are sharp: deburr everything. A network gateway is an attack surface: keep it off the internet until its default credentials are changed.

## 2. What changed to make it buildable

The concept showed what the gateway does; some of its parts could not be made, fitted or held as drawn. Each change below keeps what the gateway does, and all of them are recorded in decision record TWK-DDR-003, open for Amish's review.

*Table 1. Changes from the concept.*

| Component | The concept had | The buildable design has | Why |
| --- | --- | --- | --- |
| Backup pack | Drawn inside the UPS module | Its own 3-module battery box beside a 3-module UPS module (Figures 13 and 14) | Two bought parts cannot be put one inside the other |
| Enclosure vents | Slots in the two end walls, 2 mm from the neighbouring modules | The same slots in the two long walls (Figure 8) | Air can reach them; same area and spacing, so the temperature results stand |
| Computer and HAT | Floating inside the enclosure | Brass standoffs on the floor, a second set between the boards, and a header extender (Figure 10) | Every board is held by its own four holes |
| Antenna | Sitting on the cover with no hole | An SMA bulkhead through a 6.5 mm hole, with a pigtail to the HAT (Figure 12) | How a bulkhead is fitted |
| Cable entries | None | A network feed-through coupler and a power gland in the front wall (Figure 9) | The network and power leads need a way in |
| DIN rail | A U channel with no fixing | A true top-hat rail, 350 mm long, on three M4 screws (Figures 4 and 6) | Every module's clip hooks under the top-hat flanges |
| Ends of the rail | Nothing | Two screw-clamped end stops (Figure 16) | Nothing slides along the rail |
| Bench plate | Plywood or aluminium, no feet | 6 mm aluminium, tapped for the rail, on four rubber feet (Figures 2 and 3) | A tapped hole holds the rail with no nuts underneath |
| Wiring | No path for power or the power-fail signal into the enclosure | A USB-C power lead and a power-fail pair through the power gland (Figure 15) | The computer gets its power and its warning of an outage |

## 3. Making the components

Make and check each component before the assembly step that needs it. Sizes are in millimetres. "Front" is the long side of the modules that faces you on the bench, where the cable entries are; "left" and "right" are as seen from the front. Workshop tolerance is 0.5 mm unless a step says otherwise; drawings do not carry tolerances before TRL 4.

### 3.1 Bench plate

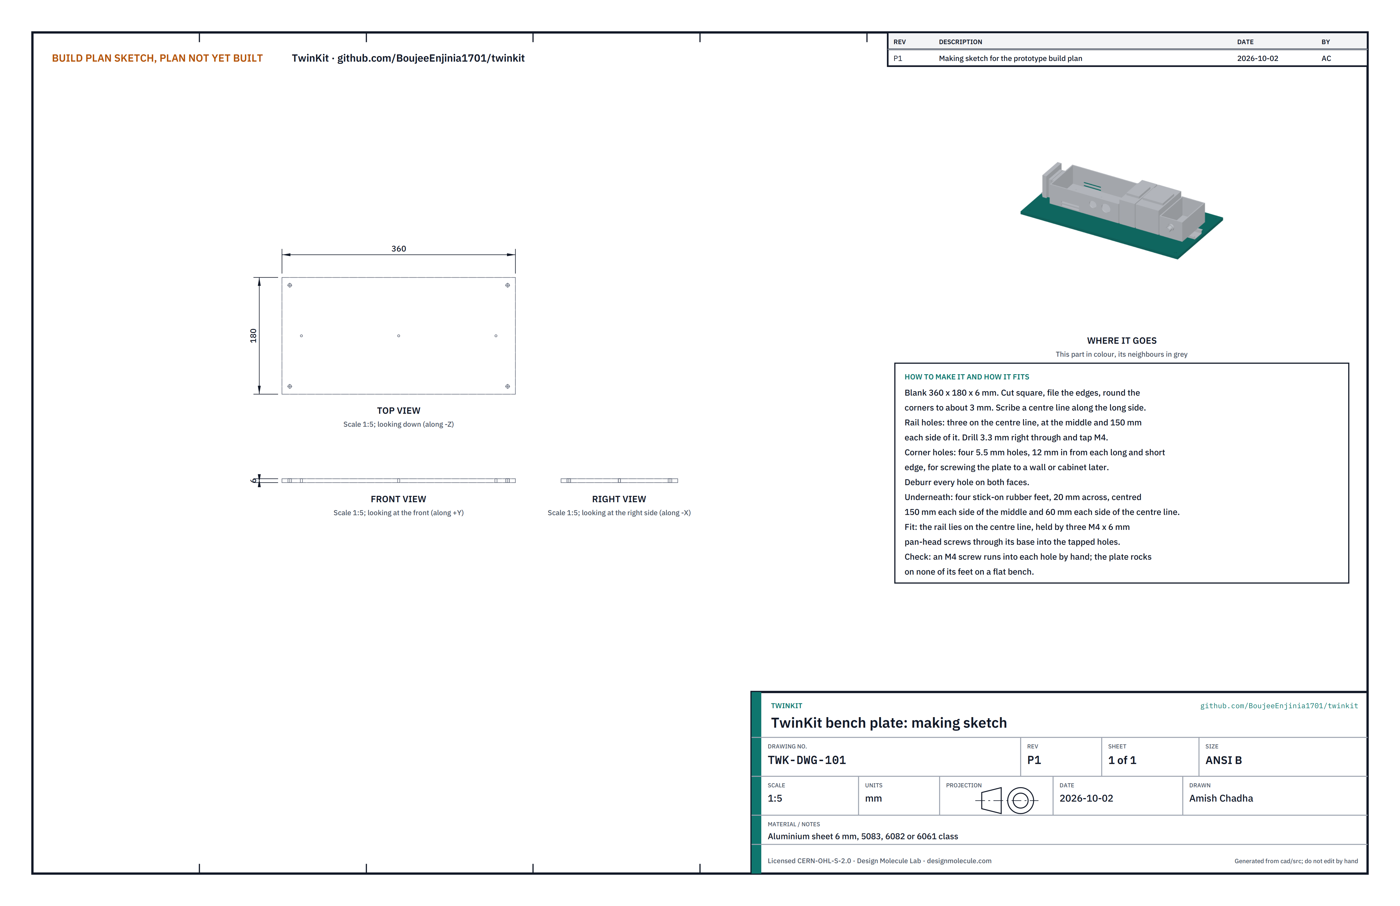
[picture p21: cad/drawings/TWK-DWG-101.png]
Figure 2. Making sketch of the bench plate


*Figure 2. Bench plate making sketch (TWK-DWG-101).*

Figure 3. Hole layout of the bench plate

*Figure 3. Every hole, measured from the middle of the plate, with the rubber feet underneath shown dotted.*

**What it is and what it is made from.** The flat base that the rail is screwed to. It stands on the bench on four rubber feet, or screws to a wall or cabinet later through its corner holes. Aluminium sheet 6 mm thick, 5083, 6082 or 6061 class, cut to 360 x 180 mm.

**How to make it.**

1. Cut the blank to 360 x 180 mm, square. File the edges and round the corners to about 3 mm.
2. Scribe a centre line along the long side and mark the middle of it.
3. Rail holes: on the centre line, at the middle and 150 each side of it. Drill 3.3 mm right through and tap M4, keeping the tap square to the plate.
4. Corner holes: four 5.5 mm holes, 12 in from each long and each short edge.
5. Deburr every hole on both faces.
6. Clean the underside and press on four stick-on rubber feet, 20 across, centred 150 each side of the middle and 60 each side of the centre line (step 1).

**How it fits the parts next to it.**

Figure 4. Joint 1: DIN rail on the bench plate

*Figure 4. The rail's base lies flat on the plate; an M4 pan-head screw passes through it into a tapped hole.*

The rail's 27 mm wide base lies flat on the top face, along the centre line, with each end 5 in from the plate's short edges. Three M4 x 6 pan-head screws hold it, one in each tapped hole. Nothing else touches the plate: every module stands on the rail's flanges, 7.5 above it.

**Check before moving on.** An M4 screw runs into each tapped hole by hand. On a flat bench the plate rocks on none of its feet.

### 3.2 DIN rail

Figure 5. Making sketch of the DIN rail

*Figure 5. DIN rail making sketch (TWK-DWG-102).*

**What it is and what it is made from.** The standard rail that every module clips onto. TS35 x 7.5 slotted top-hat rail, steel or aluminium: 35 wide across its top flanges, 7.5 high, with a 27 wide base.

**How to make it.**

1. Cut a 350 length with a hacksaw. File both ends square and remove every burr, inside the channel too.
2. Mark three holes on the centre line of the base: at the middle and 150 each side of it.
3. Where a factory slot already falls within 3 of a mark, use the slot. Otherwise drill 4.5 through the base.

**How it fits the parts next to it.**

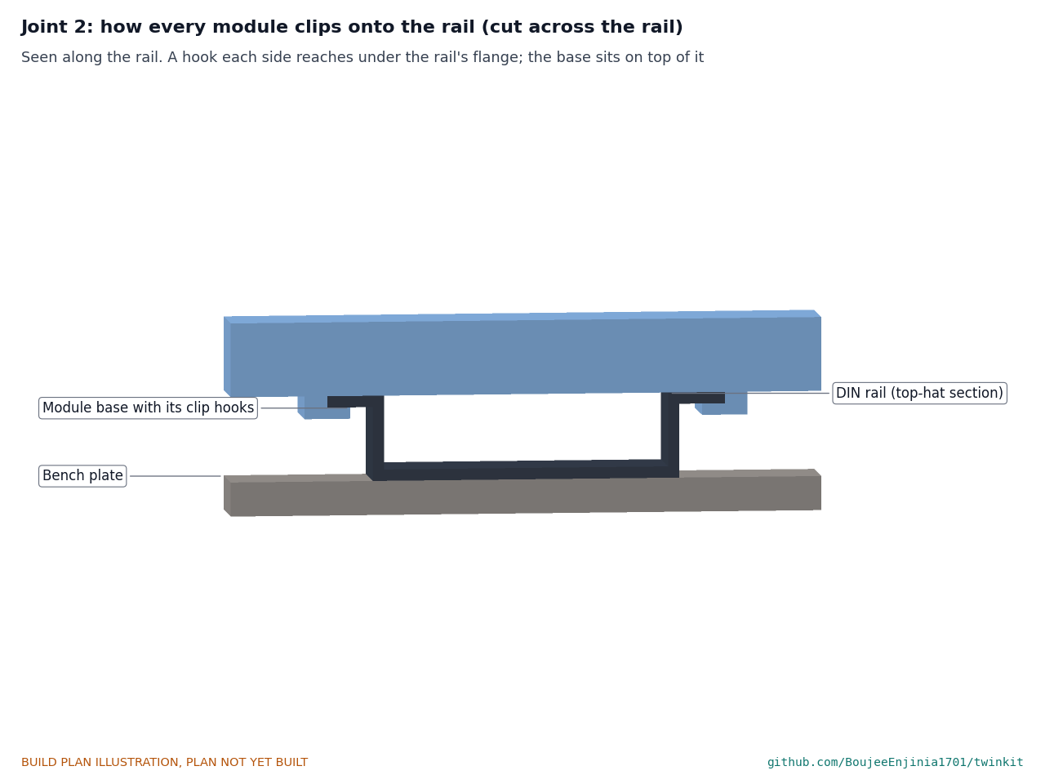
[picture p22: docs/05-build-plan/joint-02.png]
Figure 6. Joint 2: how every module clips onto the rail


*Figure 6. Seen along the rail, cut across. A hook on each side of the module's base reaches under the rail's flange; the base sits on top of the flanges.*

The base is screwed to the plate (Figure 4). Every module hooks its back edge under one flange and snaps its front edge over the other. The screw heads sit 3.9 below the modules' bases, so a module slides along the rail without catching.

**Check before moving on.** The rail lies flat along its whole length; a module clips on and slides from end to end without catching on a screw.

### 3.3 Gateway enclosure base, cut and drilled

Figure 7. Cutting and drilling sketch of the enclosure base

*Figure 7. Enclosure base cutting and drilling sketch (TWK-DWG-103).*

Figure 8. Cut-outs in the enclosure base

*Figure 8. A: the front wall, with the vent slots, the network coupler hole and the power gland hole. B: the floor, with the four holes for the computer.*

**What it is and what it is made from.** The lower half of a bought 9-module DIN enclosure for a single-board computer: polycarbonate, 157.5 long, 90 deep and 44 high, with a DIN clip moulded under its floor. It holds the computer and the concentrator. You cut vent slots in both long walls, two entry holes in the front wall and four holes in the floor.

**How to make it.**

1. Decide which long wall is the front and mark it. Cover the walls and floor with masking tape.
2. Vent slots, both long walls: two slots 40 x 4, centred 32 left of the middle, from 2.5 to 6.5 and from 9.5 to 13.5 above the outside of the floor (Figure 8, A). Chain drill with a 3.5 drill and file to the line. Skip any slot the maker has already moulded in the same place.
3. Front wall, both centred 26 above the outside of the floor: a 20 hole 50 right of the middle for the network coupler, and a 16.2 hole 20 right of the middle for the power gland. Pilot 3 at low speed, then open out with a step drill, light pressure, with a block of wood behind the wall. Check each size on the part's datasheet before the last step.
4. Floor: four 2.7 holes for the computer, 58 apart along the base and 49 apart across it, the left pair 59 left of the middle and the right pair 1 left of it, 24.5 each side of the centre line (Figure 8, B). If the enclosure has moulded bosses for the computer, use them instead and skip this step.
5. Deburr every cut inside and out, peel the tape and clean with water and mild soap only; solvents craze polycarbonate.

**How it fits the parts next to it.**

Figure 9. Joint 4: network coupler and power gland in the front wall

*Figure 9. Each entry clamps the wall between its outside flange and its inside nut.*

The network coupler and the power gland go in from outside, flange and seal outside, nut inside (step 3). They sit 13.5 or more clear of both boards.

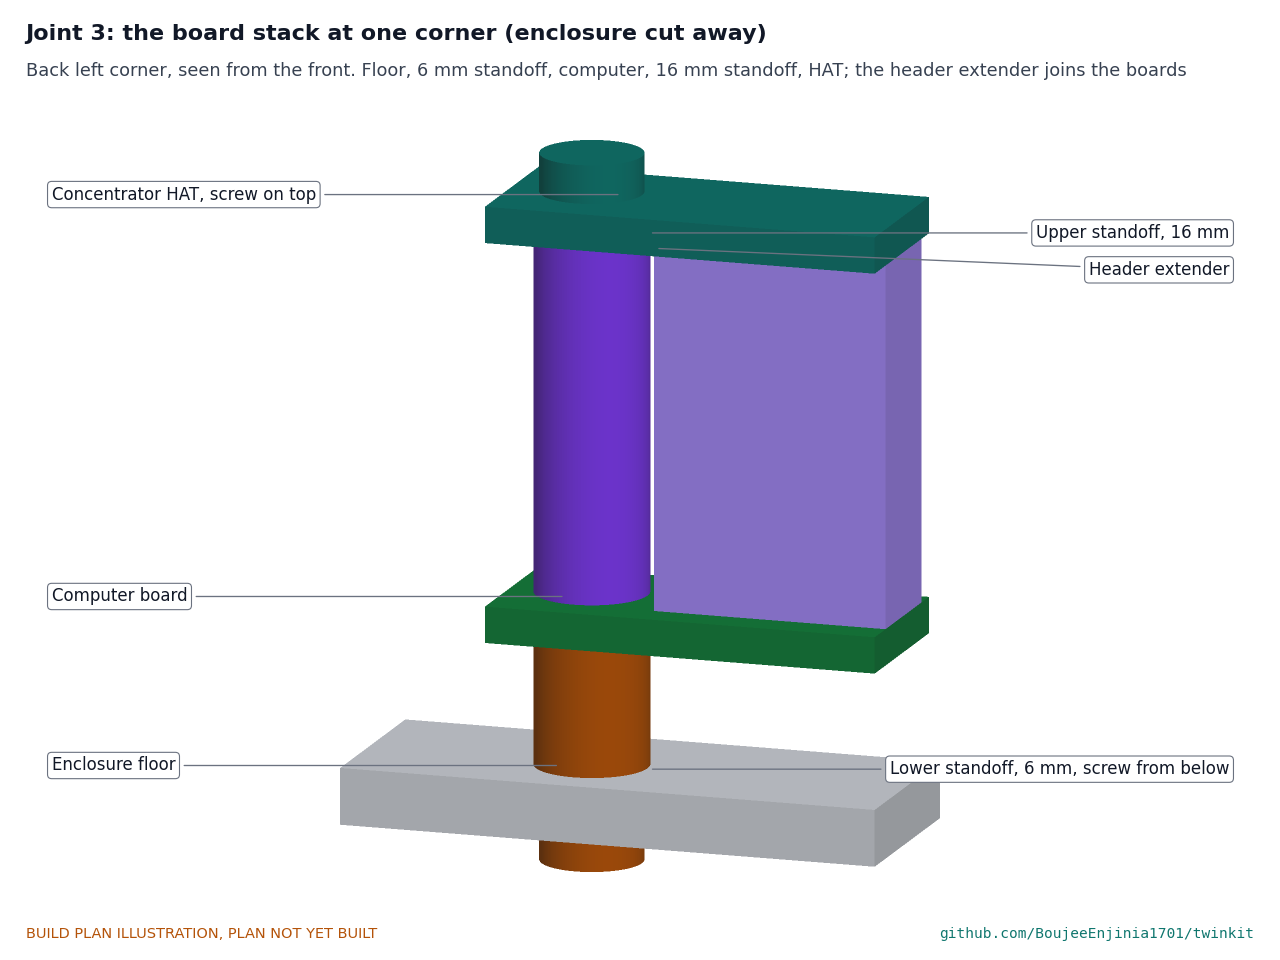
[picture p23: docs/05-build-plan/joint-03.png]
Figure 10. Joint 3: the board stack at one corner


*Figure 10. At each of the four corners: floor, 6 mm standoff, computer, 16 mm standoff, HAT. The header extender joins the two boards.*

Four 6 mm brass standoffs stand on the floor holes, each held by an M2.5 pan-head screw from underneath (step 4). The screw heads sit 4.75 outside the rail's flanges, so they never touch the rail. The computer sits on the standoffs with its network socket toward the coupler, and four 16 mm standoffs screw into the lower ones through the computer's holes. The HAT sits on the 16 mm standoffs and on a header extender pushed onto the computer's 40-pin header, and is held by four M2.5 screws. The active cooler on the computer clears the HAT by 8. The DIN clip under the floor hooks onto the rail (Figure 6).

**Check before moving on.** Lay the computer on the floor: its four holes line up with yours. No crack runs out from any hole under a bright lamp.

### 3.4 Gateway enclosure cover, drilled

Figure 11. Drilling sketch of the enclosure cover

*Figure 11. Enclosure cover drilling sketch (TWK-DWG-104).*

**What it is and what it is made from.** The upper half of the same bought enclosure, clear or tinted polycarbonate, 16 deep, closing onto the base with the maker's clips or screws. It carries the antenna.

**How to make it.**

1. Antenna hole: 6.5 through the top, 30 left of the middle and 20 behind the centre line (toward the back wall). Pilot 3, then step drill, with wood behind.
2. Vent slots, both long walls: two slots 40 x 4 in line with the base's slots, from 1.5 to 5.5 and from 6.5 to 10.5 above the cover's lower edge. Skip any the maker has already moulded.
3. Deburr and clean with water and mild soap.

**How it fits the parts next to it.**

Figure 12. Joint 5: antenna bulkhead through the cover

*Figure 12. The SMA bulkhead's flange and washer sit on top of the cover, its nut underneath; the whip screws onto the top.*

The bulkhead goes in from above with its nut inside (step 9). A U.FL pigtail runs from it to the HAT's antenna socket. The inside nut clears the HAT by about 22 when the cover is closed. The cover's lower edge sits on the base's upper edge all round (step 10).

**Check before moving on.** The bulkhead does not turn when the whip is screwed on finger tight.

### 3.5 Battery box base, drilled

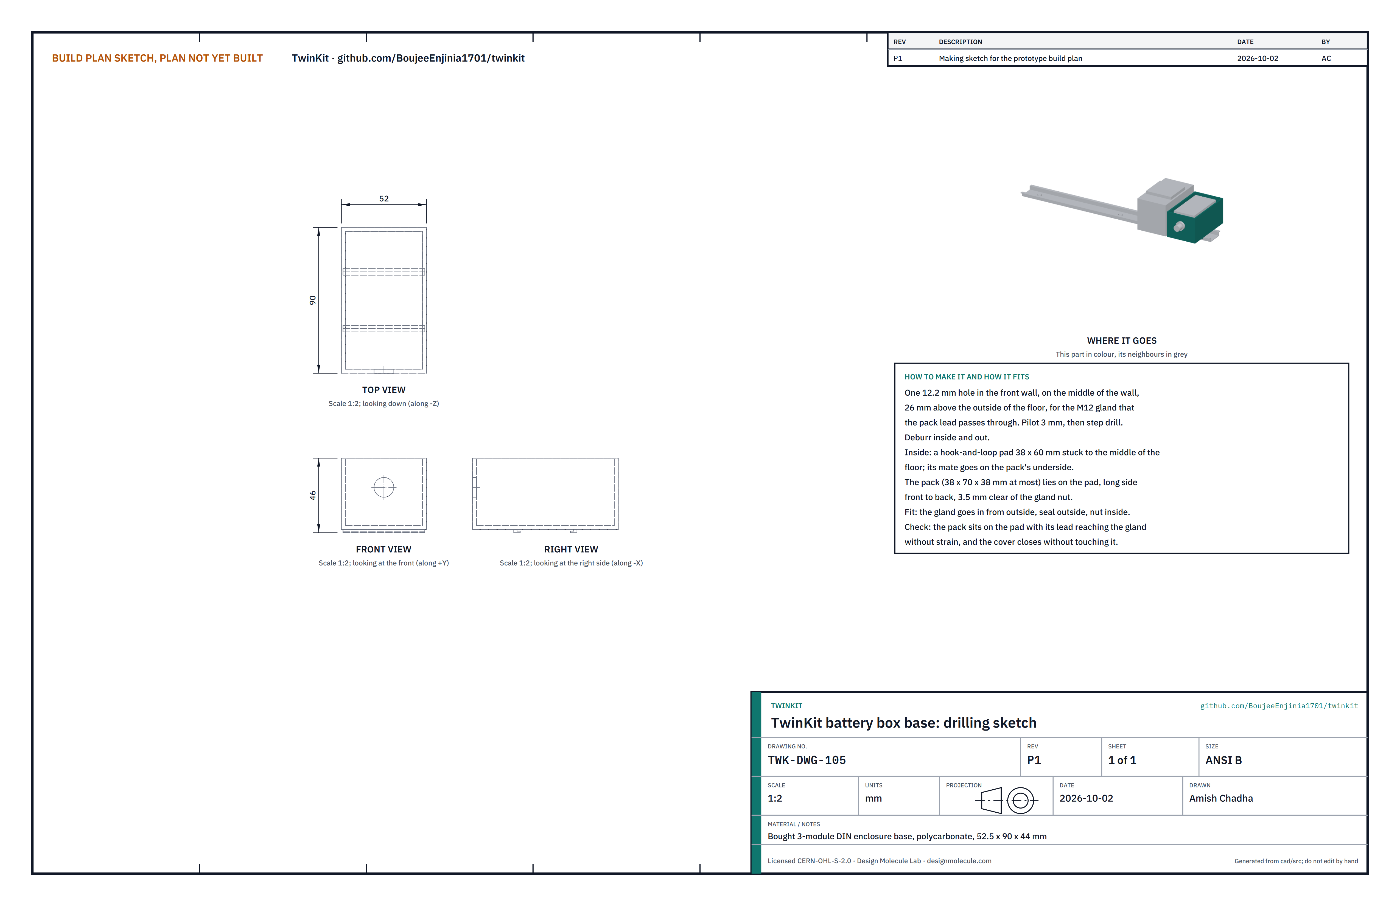
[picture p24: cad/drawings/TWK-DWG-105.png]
Figure 13. Drilling sketch of the battery box base


*Figure 13. Battery box base drilling sketch (TWK-DWG-105).*

**What it is and what it is made from.** The lower half of a bought empty 3-module DIN enclosure, polycarbonate, 52.5 long, 90 deep and 44 high, with its own cover. It holds the backup pack on the rail beside the UPS module. One hole is drilled in its front wall.

**How to make it.**

1. A 12.2 hole in the middle of the front wall, 26 above the outside of the floor, for the M12 gland. Pilot 3, then step drill.
2. Deburr inside and out.
3. Stick a hook-and-loop pad, 38 x 60, to the middle of the floor, long side front to back. Its mate goes on the underside of the pack.

**How it fits the parts next to it.**

Figure 14. Joint 6: backup pack in its battery box

*Figure 14. The pack sits on the pad, 3.5 clear of the gland nut and clear of the cover.*

The pack (no larger than 38 x 70 x 38) lies on the pad, long side front to back, with its lead out through the gland. The gland goes in from outside with its seal outside and its nut inside. The cover closes without touching the pack. The box clips onto the rail 2 to the right of the UPS module.

**Check before moving on.** The pack's lead reaches the gland without strain, and the cover closes without force.

### 3.6 Wiring

Figure 15. Block-level wiring

*Figure 15. Block-level wiring with wire sizes. Every connection is at a bought module's screw terminal or plug; no circuit board is made.*

Wire it like this, with stranded copper and a ferrule on every screw terminal. Run the wires along the front of the modules and tie them to adhesive tie mounts on the plate.

1. Adapter lead to the fuse holder and the two terminal blocks: 0.75 mm² (18 AWG), positive through the 3.15 A time-delay fuse.
2. Terminal blocks to the UPS module's input: 0.75 mm².
3. UPS module's output to the converter's input: 0.75 mm².
4. Converter's 5.1 V output to the computer: the USB-C power lead with bare ends, rated 5 A, in through the power gland.
5. UPS module's power-fail contact to a free GPIO pin and a ground pin on the HAT's pass-through header: a 0.25 mm² (24 AWG) twisted pair, through the same gland (the gland's insert has two holes).
6. Pack lead from the battery box gland to the UPS module's battery terminals: 0.75 mm². Leave it unplugged at the UPS end until stop S3 (section 6).
7. Patch lead from the computer's network socket to the inside of the network coupler (done in step 6).
8. U.FL pigtail from the HAT to the antenna bulkhead (done in step 10).

**Check before moving on.** With the adapter unplugged and the pack lead loose, every wire continues end to end and the adapter's positive does not read as a short (under 10 Ω) to ground. Every wire is labelled at both ends.

### 3.7 Bought components

Buy to specification, not brand. Line numbers are those of the bill of materials.

- **DIN rail (line 2).** TS35 x 7.5 slotted top-hat rail, at least 350 long. Made as section 3.2.
- **Gateway enclosure (lines 3 and 4).** 9-module DIN enclosure for a single-board computer, about 157.5 x 90 x 60, polycarbonate, DIN clip in the base, cover held by clips or screws. Worked as sections 3.3 and 3.4.
- **Computer (line 5).** Quad-core Arm board with 4 GB, Ethernet, Wi-Fi and a 40-pin header, 85 x 56 with four mounting holes 58 x 49 apart (Raspberry Pi 5 class).
- **Active cooler (line 6).** The clip-on heat sink and fan made for the computer, no taller than 8 above the board.
- **Concentrator HAT (line 7).** SX1302 or SX1303 8-channel LoRaWAN concentrator on a 40-pin HAT, US915 version for the first build, 65 x 56 with holes on the computer's pattern and a U.FL antenna socket.
- **microSD card (line 8).** 64 GB high-endurance, A2 class, flashed with the operating system before step 5.
- **Antenna (line 9).** 3 dBi whip for the 915 MHz band, SMA bulkhead for a 6.5 hole, U.FL pigtail about 150 long.
- **DC-DC converter (line 10).** DIN rail, 2 modules, 9 to 30 V in, 5.1 V 5 A out.
- **UPS module (line 11).** DIN rail DC UPS, 3 modules wide, with no battery inside, for an external 12.8 V LiFePO4 pack: 9 to 30 V input, a buck-boost charger to 14.6 V at 0.5 A or less that stops charging below 0 °C and above 45 °C, pass-through output, and a power-fail output that is a dry contact or an open collector (never a voltage).
- **Backup pack (line 12).** 12.8 V 1.5 Ah LiFePO4 (four 18650 cells in a 2 x 2 block), built-in protection board and fuse, no larger than 38 x 70 x 38, lead about 300 long, with a maker's datasheet.
- **Terminal blocks and fuse (line 13).** Two DIN screw terminal blocks and a DIN fuse holder for 5 x 20 fuses, with a 3.15 A time-delay fuse.
- **Battery box (line 17).** Empty 3-module DIN enclosure, about 52.5 x 90 x 60, base and cover. Drilled as section 3.5.
- **End stops (line 18).** Two screw-clamp end stops for TS35 rail, about 8 wide.
- **Board mounting kit (line 19).** Four M2.5 x 6 brass standoffs (female-female), four M2.5 x 16 standoffs (male-female), eight M2.5 x 5 pan-head screws, and a 2 x 20 header extender about 10 tall.
- **Cable entries (line 20).** A round RJ45 feed-through coupler for a 20 hole with a panel nut (Cat 6), a 0.15 m patch lead, an M16 x 1.5 nylon gland (IP68) with a two-hole sealing insert, and an M12 x 1.5 nylon gland (IP68) for 3 to 6.5 cable.
- **Fixings and wiring (line 21).** Three M4 x 6 pan-head screws, four stick-on rubber feet 20 across and 6 high, hook-and-loop pads, a USB-C power lead with bare ends rated 5 A, 0.75 mm² and 0.25 mm² stranded wire, ferrules, adhesive cable-tie mounts and ties.
- **Not in the kit.** A certified, double-insulated 12 V DC adapter of at least 2 A (or an existing 12 V supply), a laptop or phone for the dashboard, and a sensor node such as FieldNode.

## 4. Putting it together

In each picture the parts already fitted are grey and the part being fitted is in colour, with an arrow showing the way it goes in.

### Step 1: rubber feet under the bench plate

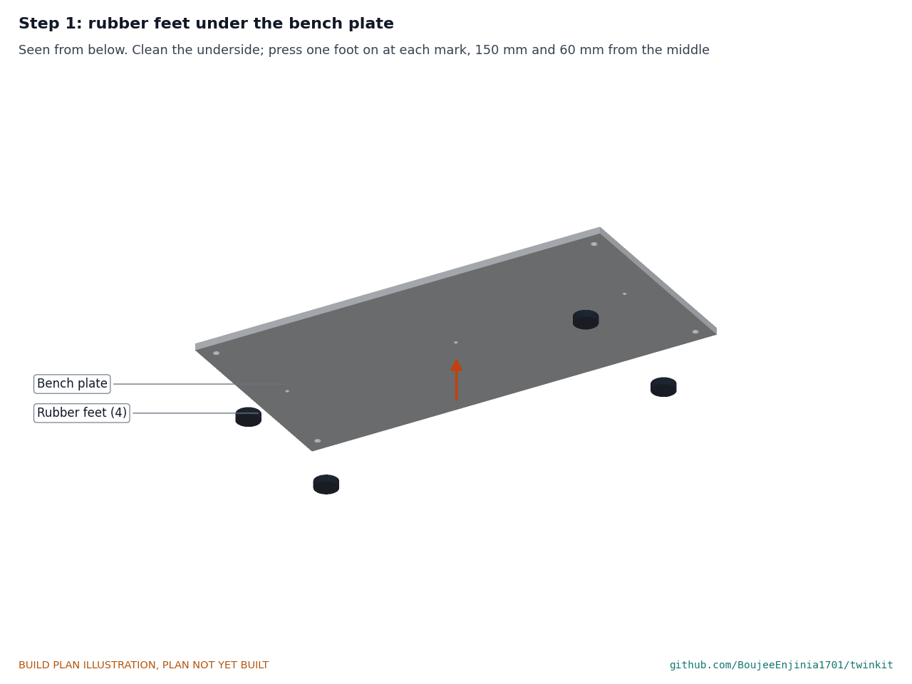
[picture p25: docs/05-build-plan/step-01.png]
Step 1


Seen from below. Clean the underside with alcohol, let it dry, and press a foot firmly onto each mark.

### Step 2: DIN rail onto the bench plate

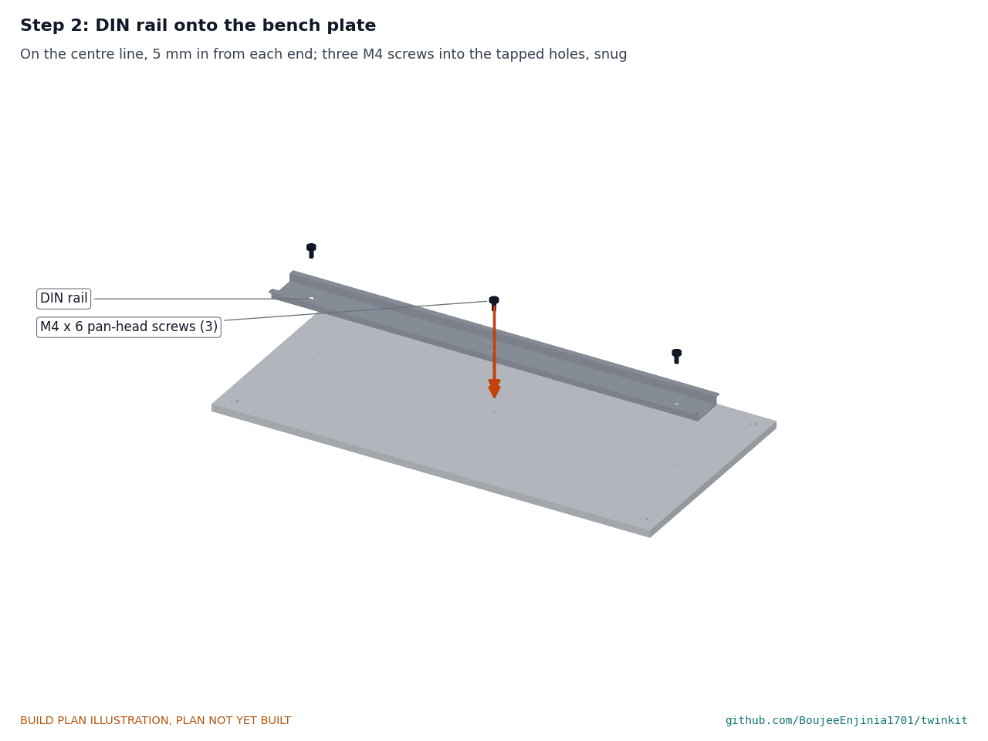
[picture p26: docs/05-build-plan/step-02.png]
Step 2


Lay the rail on the centre line, 5 in from each end. Three M4 x 6 pan-head screws into the tapped holes, snug.

### Step 3: network coupler and power gland into the enclosure base

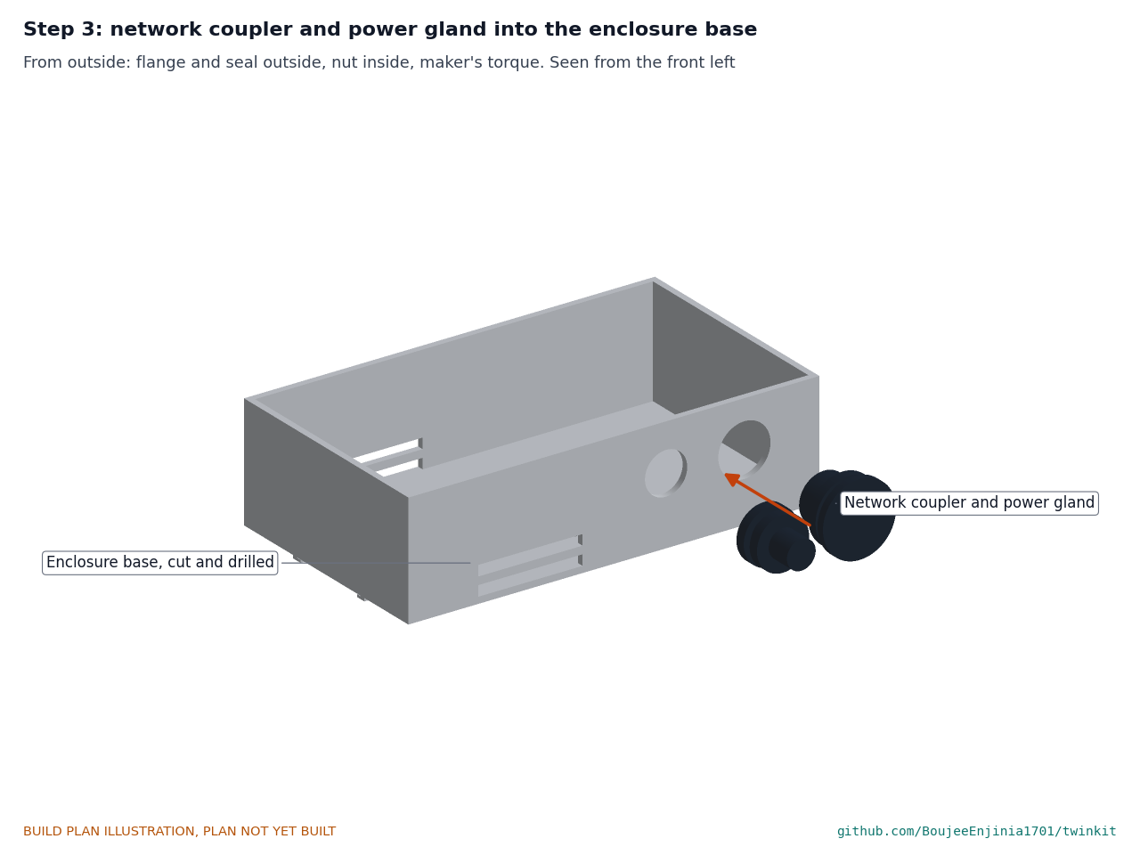
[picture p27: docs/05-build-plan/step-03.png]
Step 3


From outside, flange and seal outside, nut inside, tightened to the maker's torque. From inside, pass the bare end of the USB-C power lead and the power-fail pair out through the gland's two-hole insert, leaving about 150 inside, but do not tighten the gland cap yet.

### Step 4: lower standoffs into the enclosure floor

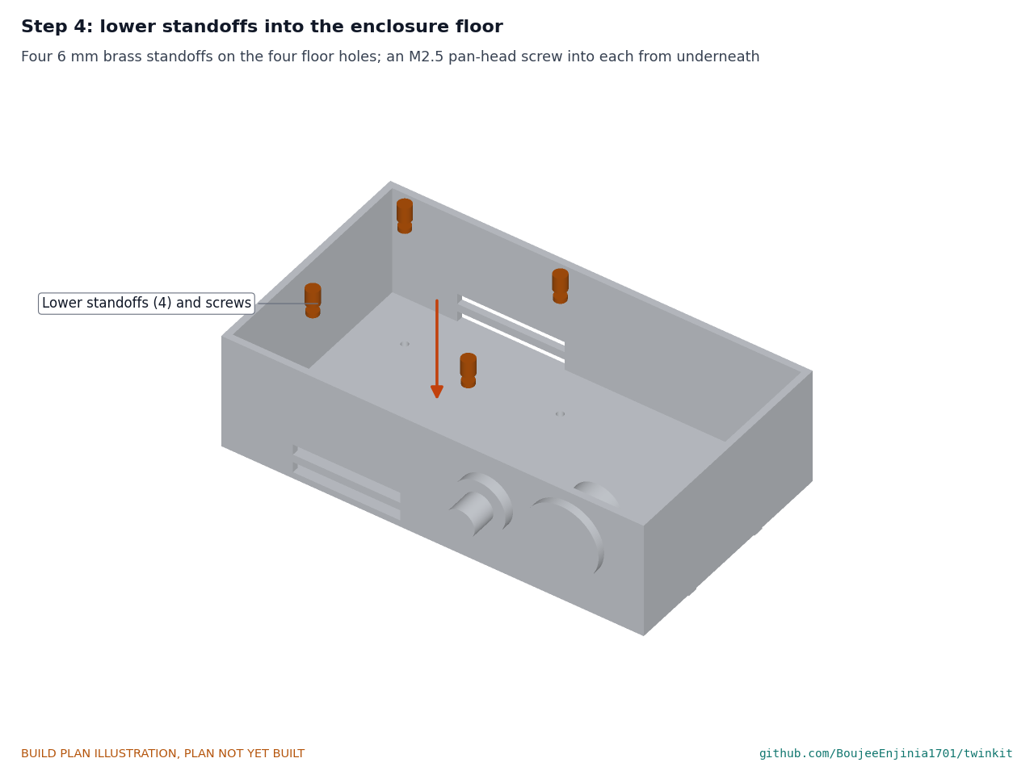
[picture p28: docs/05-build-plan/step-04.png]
Step 4


Four 6 mm standoffs on the four floor holes, an M2.5 pan-head screw into each from underneath, snug.

### Step 5: cooler and microSD card onto the computer

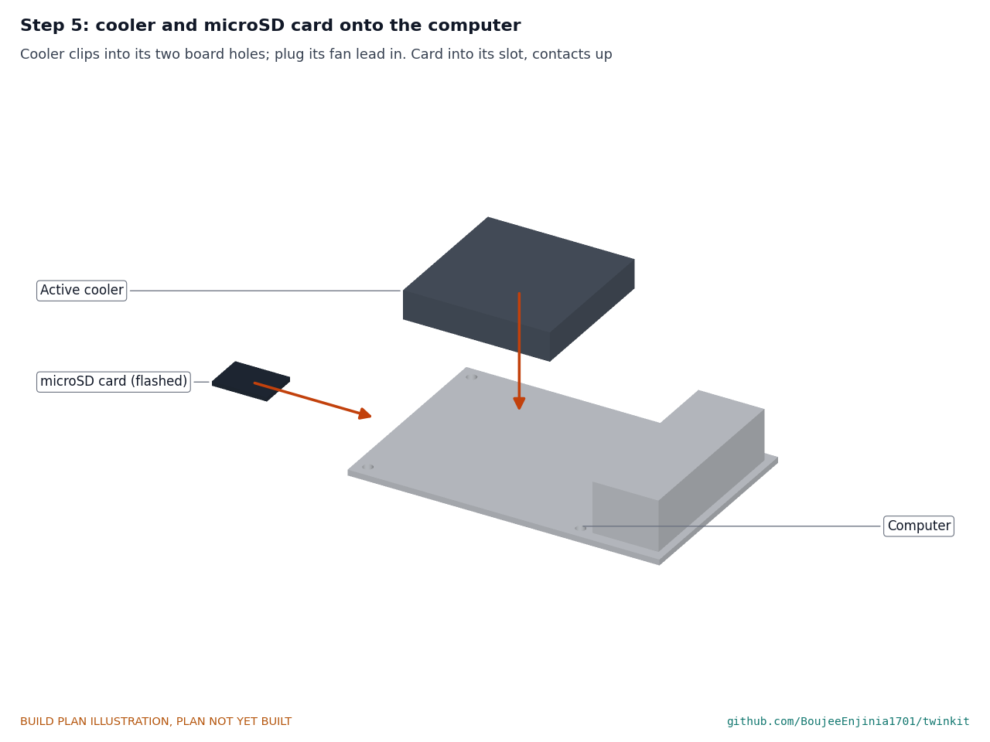
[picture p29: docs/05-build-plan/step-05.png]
Step 5


Clip the cooler into its two board holes and plug its fan lead into the fan socket. Push the flashed card into its slot, contacts toward the board.

### Step 6: computer onto the lower standoffs

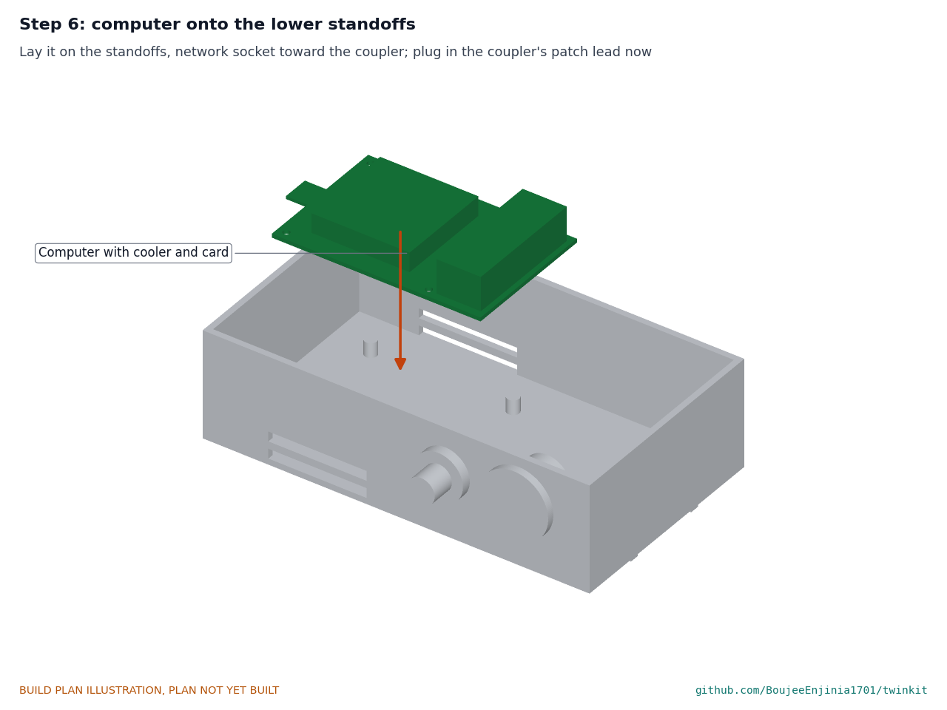
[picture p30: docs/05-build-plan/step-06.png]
Step 6


Lay the computer on the standoffs with its network socket toward the coupler. Plug the patch lead into the computer and into the inside of the coupler, and the USB-C power lead into the computer.

### Step 7: upper standoffs and header extender

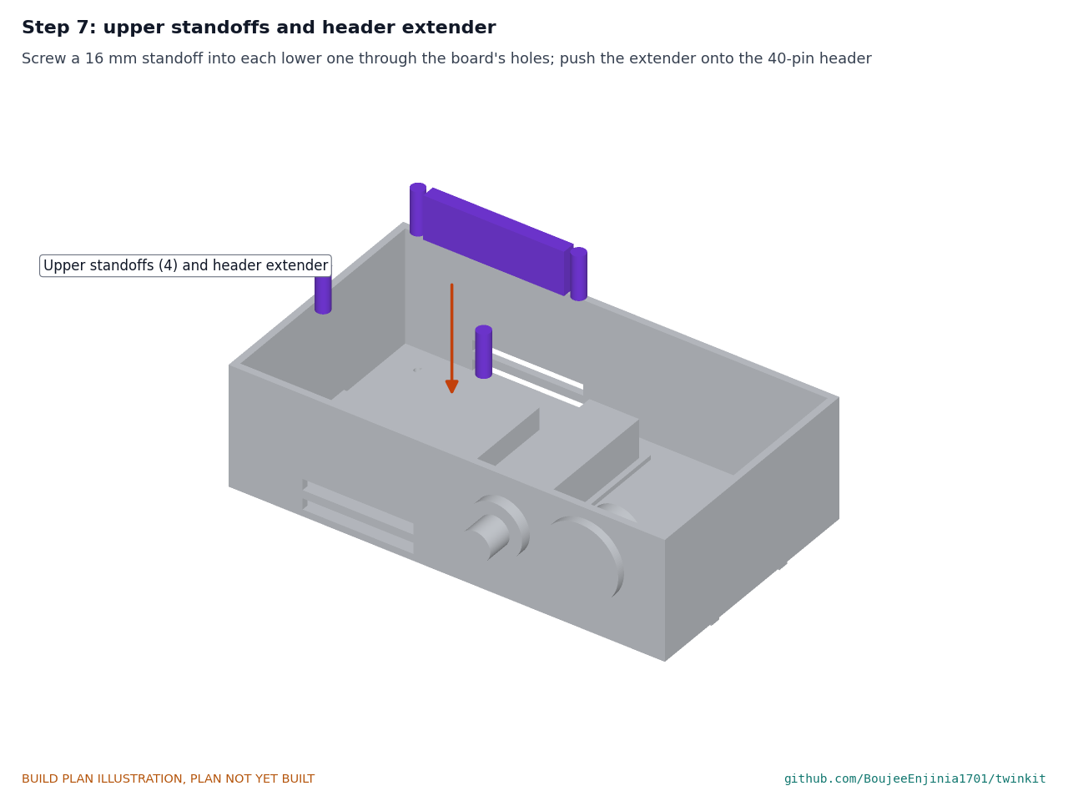
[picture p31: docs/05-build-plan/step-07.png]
Step 7


Screw a 16 mm standoff into each lower one through the computer's holes, finger tight plus a quarter turn. Push the header extender straight down onto the 40-pin header.

### Step 8: concentrator HAT onto the stack

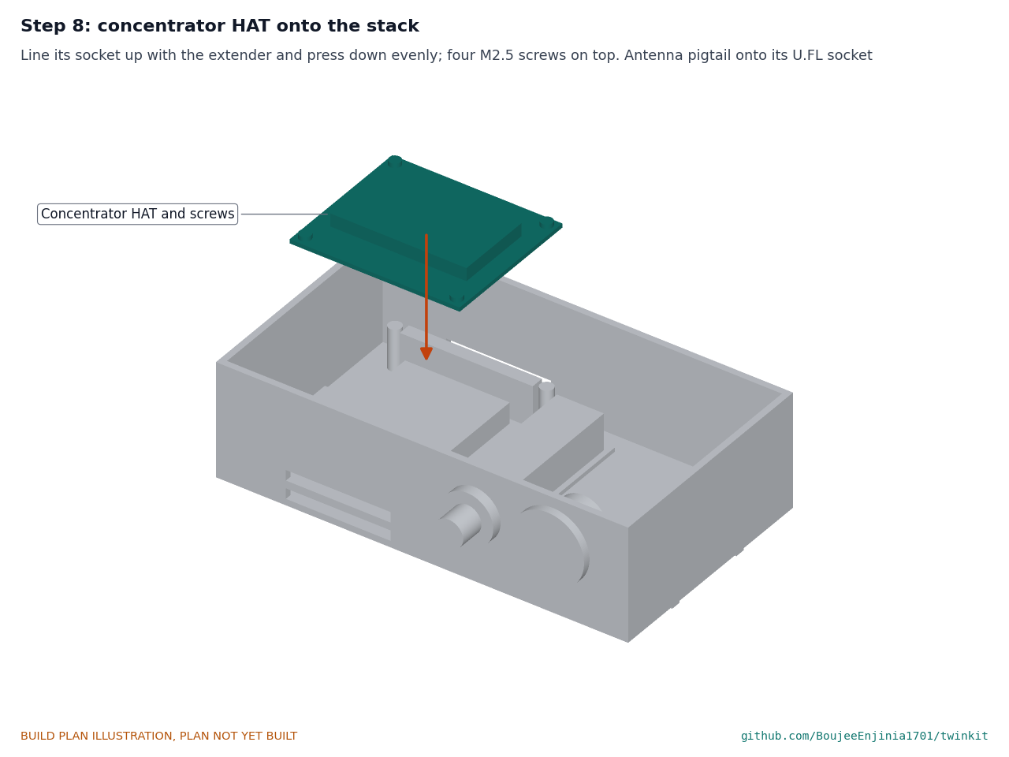
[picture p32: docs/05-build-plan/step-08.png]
Step 8


Line the HAT's socket up with the extender and press down evenly until it rests on all four standoffs. Four M2.5 screws on top. Push the antenna pigtail onto the HAT's U.FL socket. Connect the power-fail pair to the free GPIO and ground pins named in the HAT's datasheet.

### Step 9: antenna bulkhead into the cover

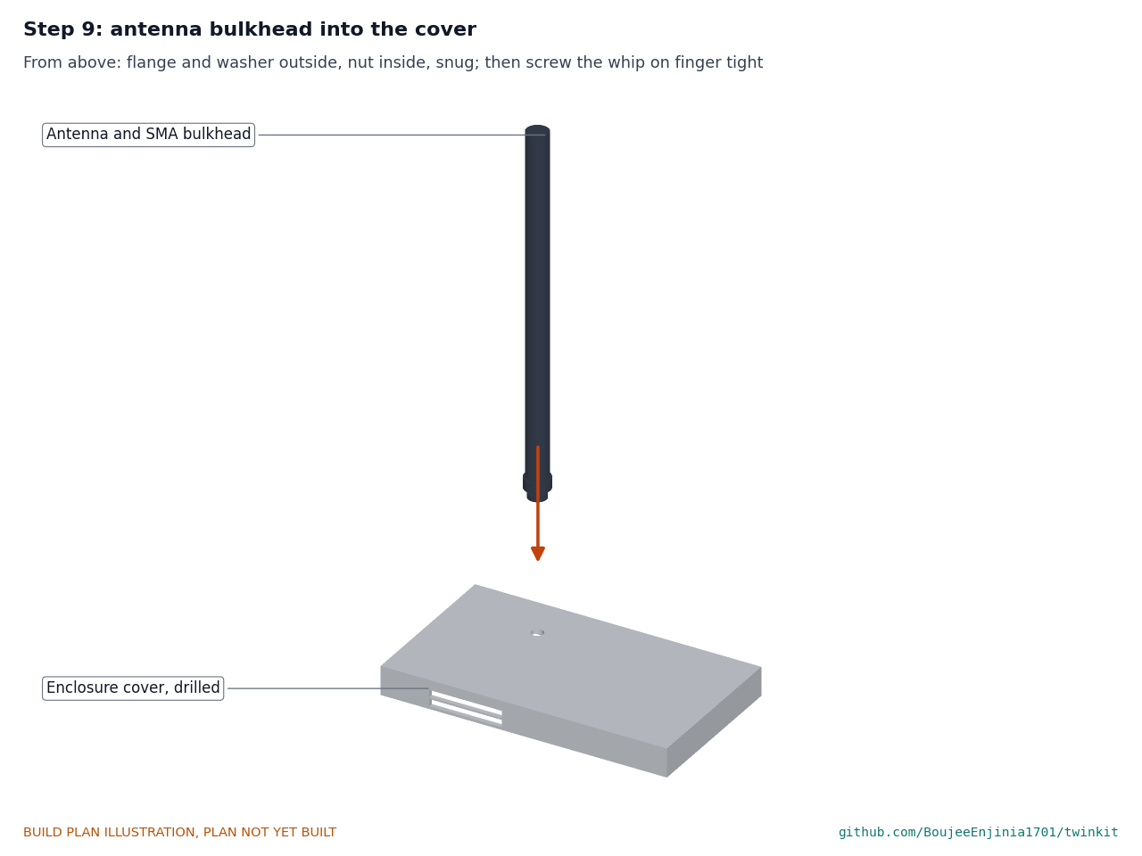
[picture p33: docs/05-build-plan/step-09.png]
Step 9


From above, flange and washer outside, nut inside, snug. Screw the whip on finger tight.

### Step 10: close the gateway enclosure

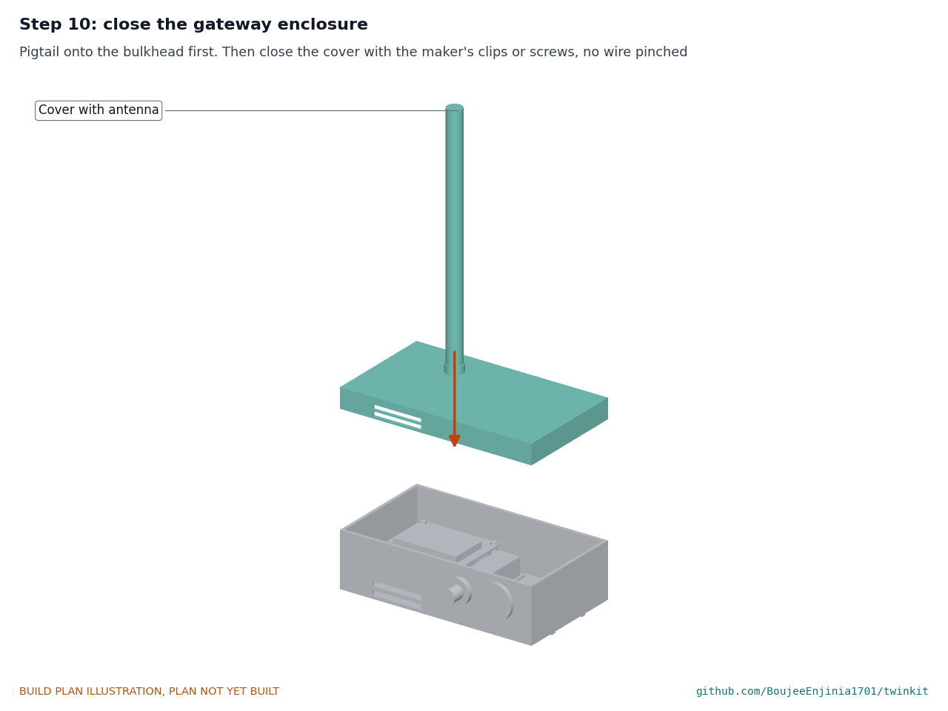
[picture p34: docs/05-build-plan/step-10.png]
Step 10


Screw the pigtail onto the bulkhead from inside. Close the cover with the maker's clips or screws, checking that no wire is pinched at the joint. Pull the spare power lead out through the gland and tighten the gland cap. **Hold point:** the wiring checks of section 3.6 pass for the wires inside the enclosure.

### Step 11: terminal blocks and fuse holder onto the rail

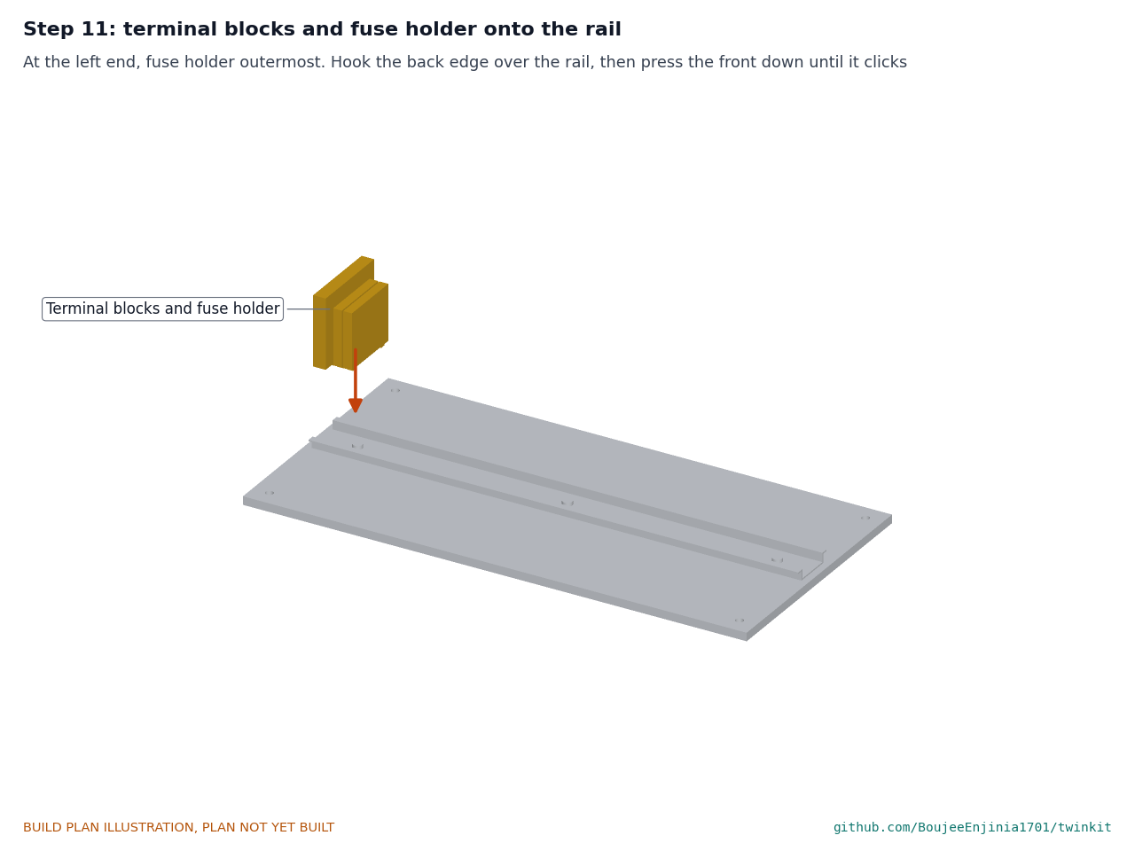
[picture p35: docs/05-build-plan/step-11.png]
Step 11


At the left end of the rail, fuse holder outermost. Hook the back edge over the rail, then press the front down until the clip snaps. Leave the fuse out.

### Step 12: gateway enclosure onto the rail

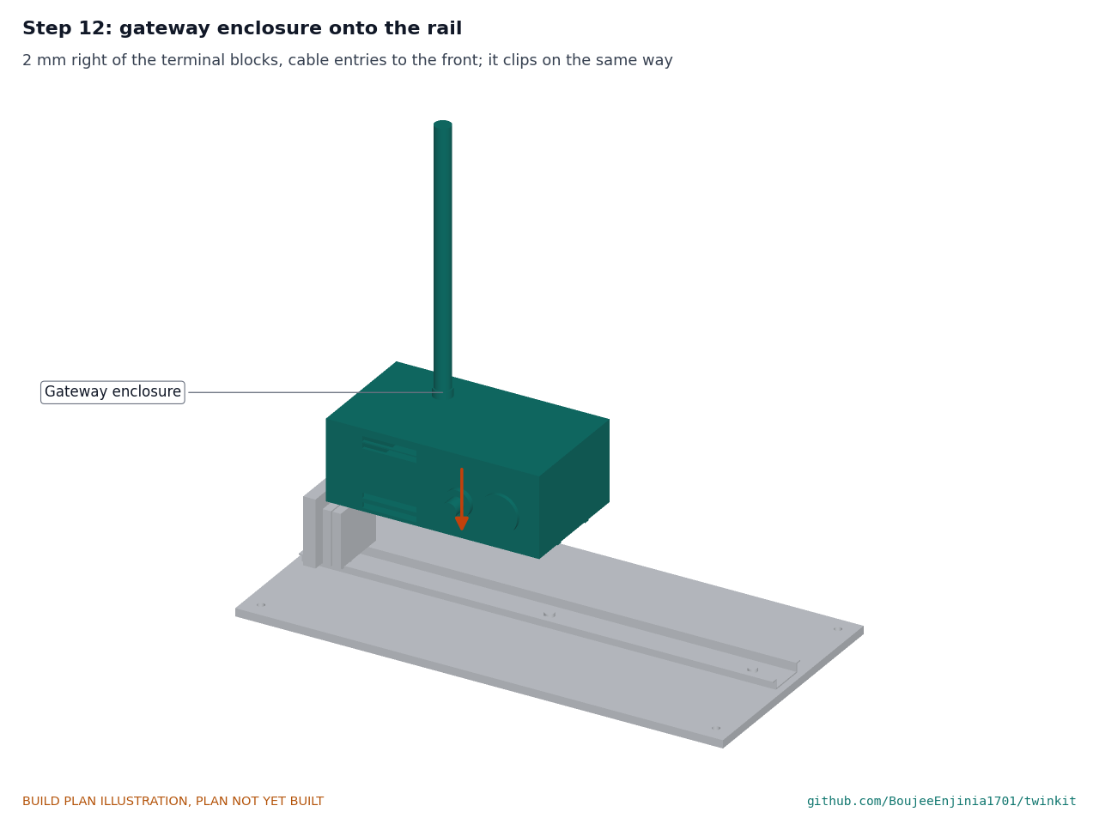
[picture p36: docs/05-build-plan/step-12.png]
Step 12


2 to the right of the terminal blocks, cable entries to the front. It clips on the same way.

### Step 13: DC-DC converter and UPS module onto the rail

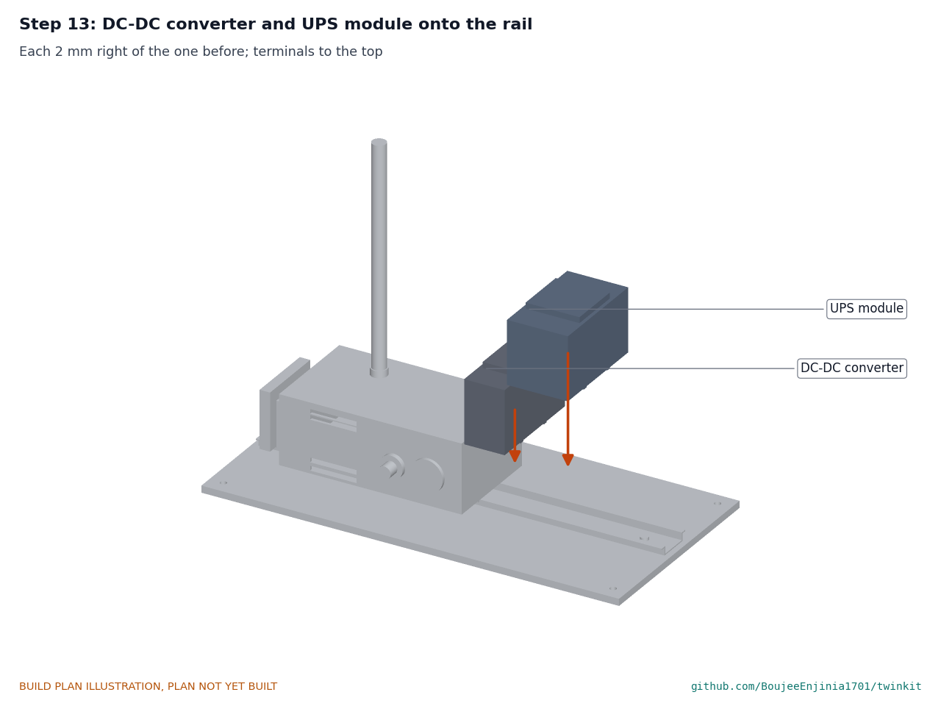
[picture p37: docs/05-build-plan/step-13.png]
Step 13


Each 2 to the right of the module before, terminals facing up.

### Step 14: battery box base onto the rail

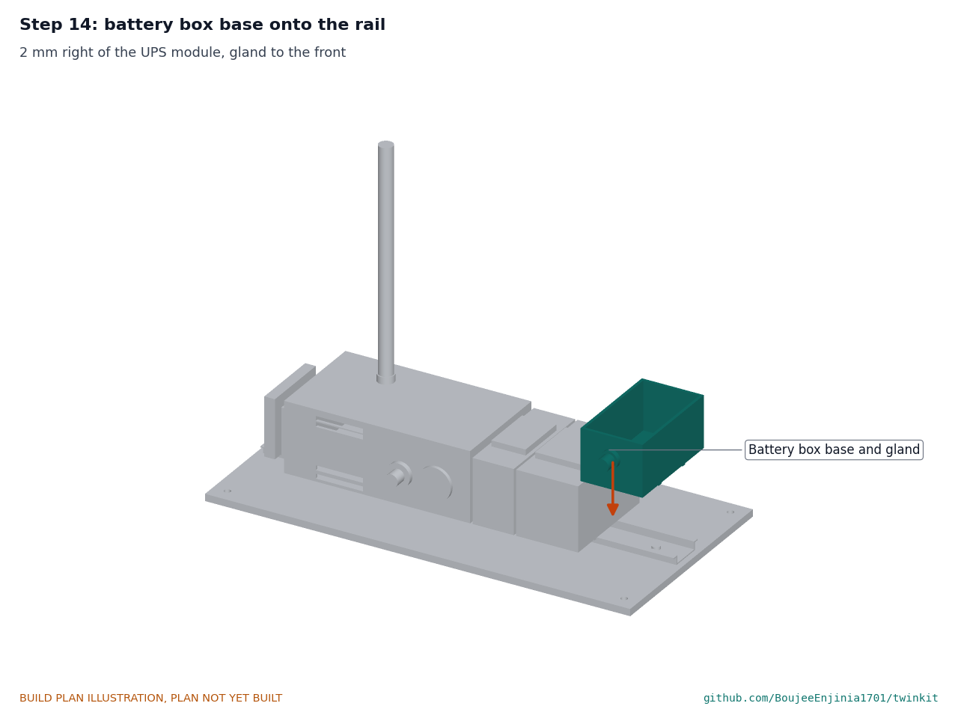
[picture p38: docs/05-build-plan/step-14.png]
Step 14


2 to the right of the UPS module, gland to the front.

### Step 15: backup pack into the battery box

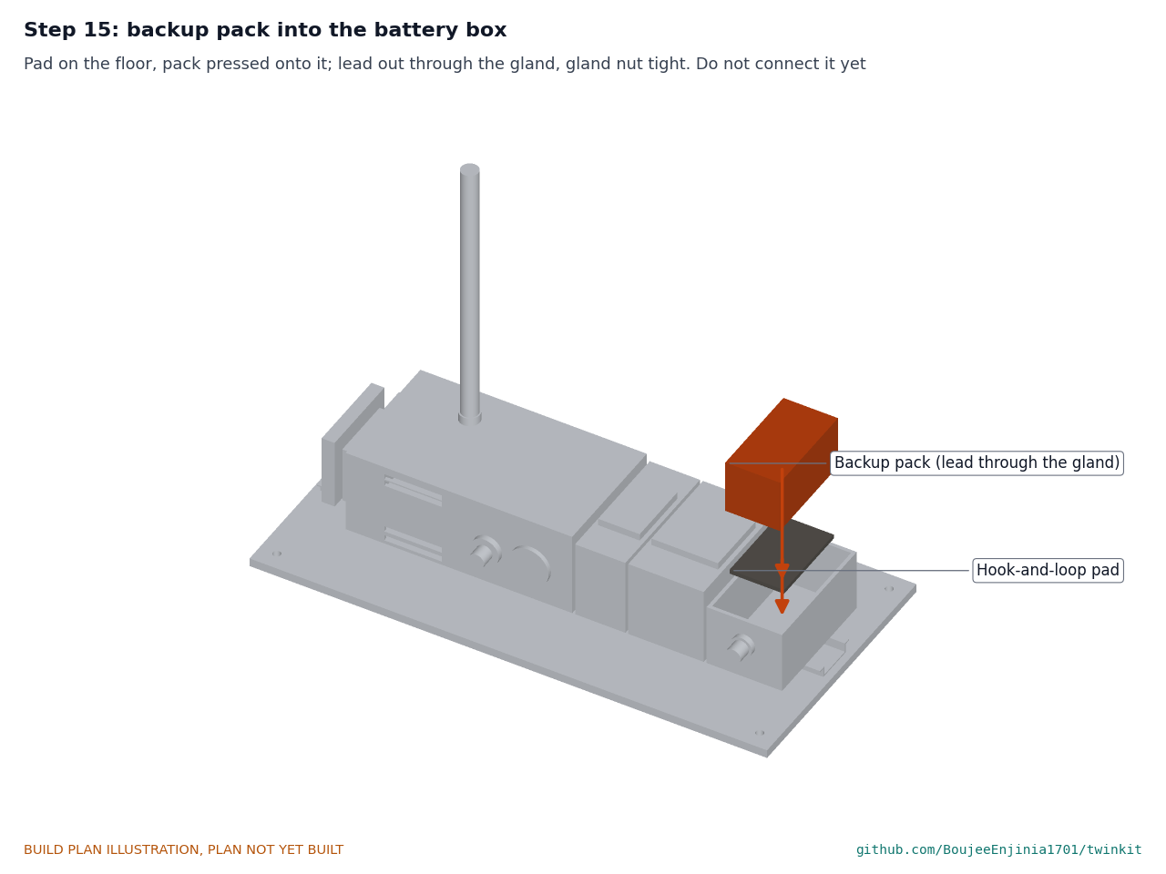
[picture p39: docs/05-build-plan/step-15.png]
Step 15


**Hold point:** safety stop S1 (section 6). Pass the pack's lead out through the gland, press the pack onto the pad, and tighten the gland cap on the lead. Do not connect the lead to the UPS module yet.

### Step 16: close the battery box

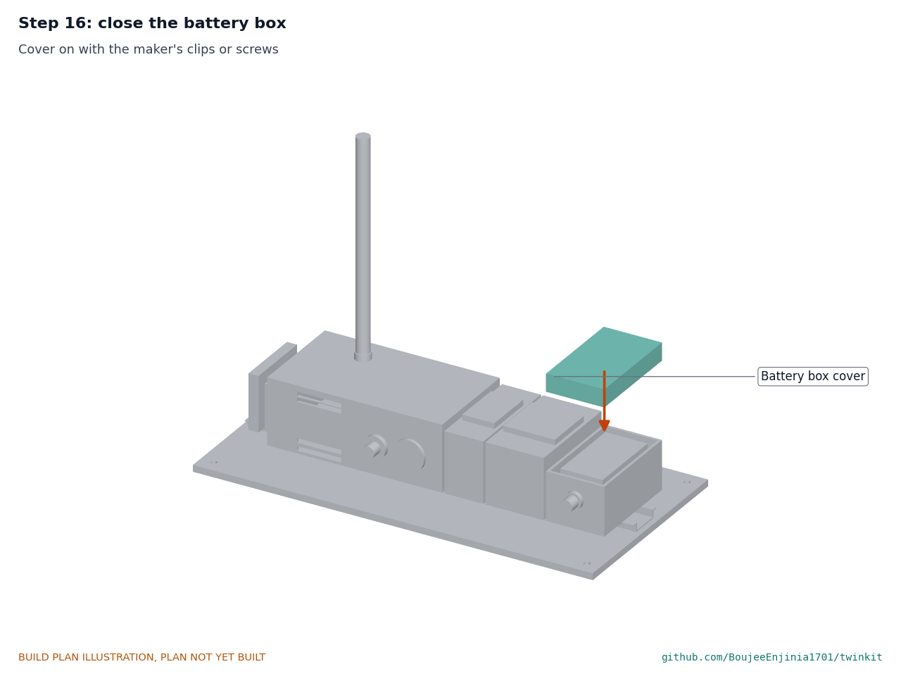
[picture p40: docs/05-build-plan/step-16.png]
Step 16


Cover on with the maker's clips or screws.

### Step 17: end stops at both ends

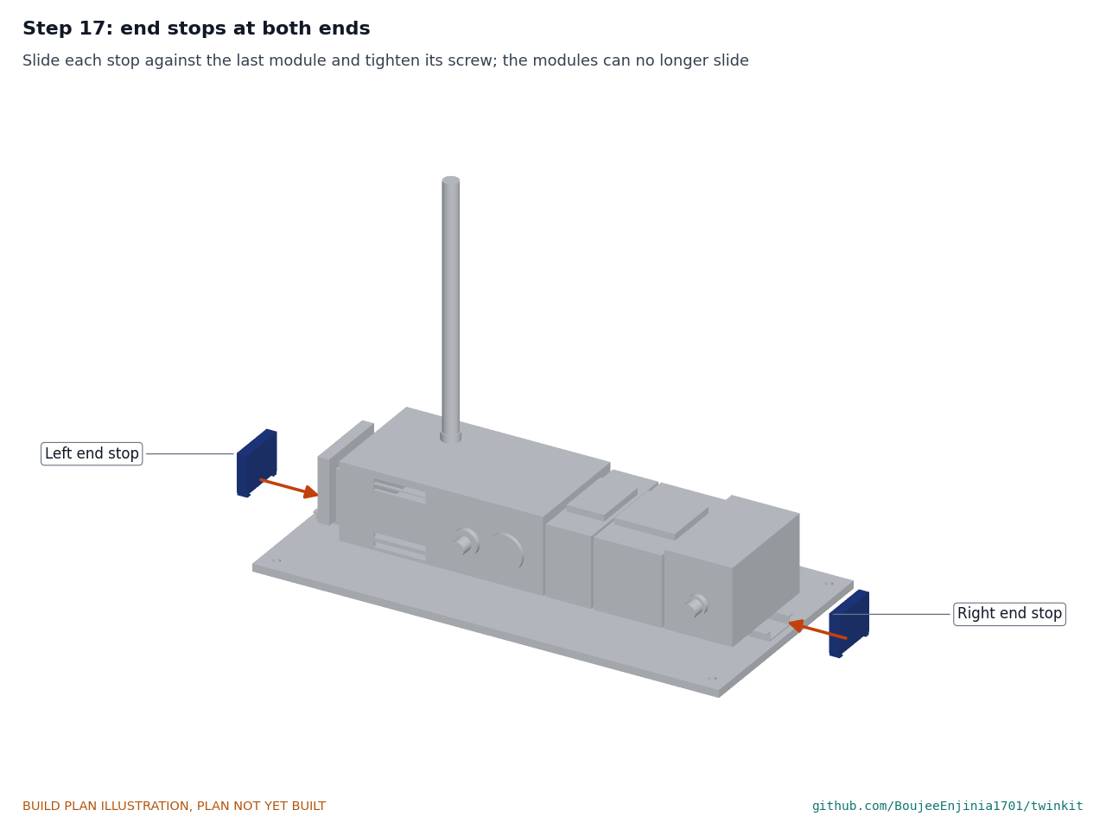
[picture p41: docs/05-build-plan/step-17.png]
Step 17


Slide each end stop along the rail until it presses against the last module and tighten its screw. Then wire the modules as section 3.6, leaving the fuse out and the pack lead loose.

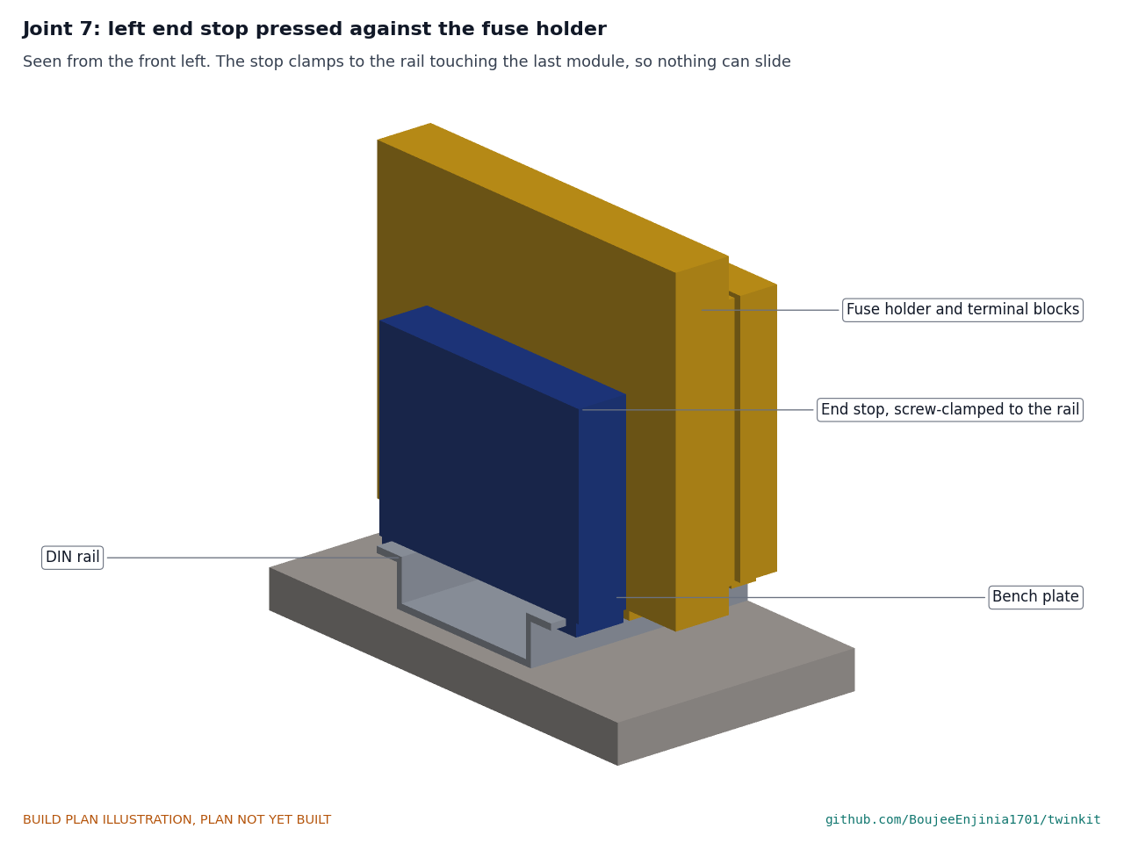
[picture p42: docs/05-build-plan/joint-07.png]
Figure 16. Joint 7: left end stop against the fuse holder


*Figure 16. The end stop is clamped to the rail touching the fuse holder, so no module can slide.*

## 5. First checks

These are the checks a TRL 4 test report would record; this plan only lists them. Requirement numbers are those of TWK-REQ-001.

*Table 2. First checks.*

| Check | Requirement | How | Pass when |
| --- | --- | --- | --- |
| Fit on the rail | R10 | Measure from the left end stop to the right one; push each module along the rail by hand | 345 or less; no module moves |
| Input polarity and fuse | R8 | Adapter plugged in, fuse in, pack lead loose; meter at the UPS input and the converter output | 11.4 to 12.6 V at the UPS input; 5.0 to 5.25 V at the converter output, polarity right |
| First boot and average power | R8 | Computer boots from the card; meter the adapter current for 10 min at idle | It boots; 8 W or less on average (6.4 W estimated) |
| Charge voltage and window | R9 | Pack connected, as stop S3; meter at the pack terminals as charging ends | Charging stops at 14.6 V, give or take 0.2 V |
| Outage ride-through | R9 | Unplug the adapter with the gateway running | The computer keeps running on the pack and logs the power-fail signal; it shuts down cleanly before the pack's cut-off |
| Network | R2, R11 | Ethernet through the coupler; log in, change the default credentials | Dashboard reached over TLS on the local network only |
| Radio | R1, R2 | One FieldNode or other LoRaWAN node within 10 m | Uplinks appear on the network server and in the database |
| Enclosure temperature at idle | R12 | Thermometer on the cover top and the computer's own temperature reading after 1 h at room temperature | Recorded for the TRL 4 thermal test; no throttling reported |
| Monitoring only | R16 | Inspect the wiring | No wire leaves the gateway to any output or actuator |

## 6. Safety stops

Stop at each point. Carry on only when everything listed is true.

- **S1. Before the pack comes into the workshop.** Pack voltage about 12.0 to 13.6 V; no swelling, dents or leaks; a datasheet from its maker; its protection board and fuse are built in. A charging spot ready on a non-combustible surface (ceramic tile or steel tray) with a fire extinguisher for electrical fires within reach.
- **S2. Before the adapter is plugged in.** The adapter is certified and double-insulated, 12 V DC, and its plug is undamaged. The fuse holder carries a 3.15 A time-delay fuse, not a larger one. With the fuse out, positive reads open to ground at the terminal blocks. Polarity at the terminal blocks is checked with a meter, not by wire colour. The pack lead is loose.
- **S3. Before the pack is connected to the UPS module.** The UPS module's charger is set for LiFePO4 at 14.6 V (the maker's setting, checked in its datasheet), its charge current is 0.5 A or less, and its charge stops below 0 °C and above 45 °C. The pack's polarity matches the UPS module's battery terminals, checked with a meter.
- **S4. First charge.** Attended the whole time, on the charging spot, with the battery box cover off; pack temperature checked by hand or thermometer every 15 minutes. Stop if the pack passes 45 °C, swells, smells or exceeds 14.6 V.
- **S5. Before the concentrator transmits.** The antenna is connected and is a 915 MHz antenna, matching the US915 concentrator. Transmitting without an antenna can damage the radio.
- **S6. Before the gateway joins any network beyond the bench.** Every default credential is changed, the dashboard is on TLS, and no port is open beyond the local network.
- **S7. Before any cabinet or mains-side installation (outside this plan).** Any wiring to an existing 12 V system or into a mains cabinet is done or checked by a qualified electrician under local code.

## 7. Tools, skills and workspace

**Tools.** Hacksaw with a 24 teeth per inch blade; bench vice with soft jaws; bench drill or a drill in a stand; drills 2.5 to 6 mm; step drill to 22 mm; M4 tap and tap wrench; flat and half-round files; deburring tool; scriber, engineer's square, steel rule and calipers; small screwdrivers (flat and Phillips) and a 5.5 mm nut driver for the M2.5 standoffs; spanners or a deep socket for the gland and coupler nuts; ferrule crimper and wire strippers; multimeter; thermometer; a computer with a card reader to flash the microSD card.

**Skills.** No certified trade is needed. Basic metalwork (marking out, sawing, drilling, tapping, filing), drilling plastic boxes, crimping ferrules, safe care of a lithium pack, and setting up a single-board computer from a flashed card. All circuits are extra-low voltage: 12 V nominal input, 14.6 V at most while the pack charges. No mains wiring is part of this build.

**Workspace.** A bench about 1.2 x 0.6 m; a metalwork corner kept apart from the electronics so chips stay off the boards; the charging spot of S1; a wired network socket or switch for the first checks.

**Personal protective equipment.** Safety glasses for cutting and drilling; cut-resistant gloves for handling cut aluminium; no gloves near a turning drill.

## 8. Where the numbers come from

- Model and constructability checks: `cad/src/model.py` (`python cad/src/model.py --check`, 274 checks); STEP and STL exports in `cad/step/` and `cad/stl/`.
- Pictures: `cad/src/build_plan_media.py`, using `.kit/build_views.py`; written to `docs/05-build-plan/` and `cad/drawings/TWK-DWG-101` to `TWK-DWG-105`.
- General arrangement: `cad/drawings/TWK-DWG-001.pdf`, Rev P3.
- Calculations: `docs/04-calcs/01-sizing.md` (TWK-CAL-001 v0.3) and `docs/04-calcs/sizing.py`; power [D1] to [D3], backup [E1] to [E3], temperature [F2], [F6], [F7], rail [H1], cost [I1], [I2].
- Bill of materials: `bom/bom.csv`.
- Decisions: `docs/decisions/0003-design-for-construction.md` (TWK-DDR-003), with TWK-DDR-001 and TWK-DDR-002; open items in `docs/06-design-decisions.md` (TWK-DEC-001).
- Requirements: `docs/03-requirements.md` (TWK-REQ-001 v0.5).

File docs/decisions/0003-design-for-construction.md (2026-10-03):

---
doc_id: TWK-DDR-003
title: TwinKit design for construction
project: TwinKit
doc_type: Design decision record
version: "0.2"
status: Draft
date: '2026-10-02'
author: Amish Chadha
license: CERN-OHL-S-2.0
revisions:
- version: "0.1"
  date: '2026-10-02'
  author: Amish Chadha
  change: Changes that make the concept physically buildable, with the reason for each; made under Amish's 2026-09-30 instruction to make the design physically buildable; open for his review
- version: "0.2"
  date: '2026-10-02'
  author: Amish Chadha
  change: Accepted by Amish on 2026-10-02 (TWK-DEC-001, item 1)
---

# 0003: Design for construction

- **Date:** 2026-10-02
- **Status:** accepted. Amish, 2026-10-02: "APPROVED: The open decisions from the last wave (TremorTrace to ZeerBox) came in after the review and aren't on the page either." This approves the recommendation written for each open decision in the design decisions register (TWK-DEC-001 v0.1), including acceptance of every change below (P1 to P9), as made. The record stays Draft. Nothing here changes what TwinKit does, its pitch or its safety case.

## Context

On 2026-09-30 Amish asked for every repo to have an illustrated prototype build plan, and wrote: "If you are realising that the design cannot be built as per concept - fix the design assumptions to match and be physically feasible as you draw the illustrations." The TRL 3 model of TWK-DDR-002 was a massing model: it showed the gateway's modules at the right sizes on a DIN rail, but several parts could not be made, fitted or held as drawn. Checking the model part by part found nine problems (P1 to P9 below).

The changes keep what the gateway does: the same computer, cooler, concentrator, card, antenna, converter, UPS, pack, fuse and terminals, the same 9-module enclosure and its vent area, the same 12 V input and the same software. Every change is in `cad/src/model.py`, which now also runs 274 constructability checks (`python cad/src/model.py --check`): no two parts overlap, every part touches the part that holds it, and neighbours keep their stated clearances. All 274 pass.

## Options considered

For each problem the simplest physically sound fix that uses bought parts or plain workshop operations (saw, drill, tap, file) was chosen. The alternatives considered are given in the "Why this way" column.

## Decision

*Table 1. Changes made to the model, the BOM and the calculations.*

| # | Problem in the concept | Change made | Why this way |
| --- | --- | --- | --- |
| P1 | The backup pack was drawn inside the UPS module's shell. The UPS module and the pack are both bought parts, so one cannot be put inside the other. | The UPS module (line 11) is now a 3-module unit with no battery inside it. The pack (line 12, no larger than 38 x 70 x 38 mm, a 4S block of 18650 cells) sits in its own empty 3-module DIN enclosure, the battery box (new line 17), on a hook-and-loop pad, with its lead out through an M12 gland in the box's front wall. | Keeps everything on the rail, as the concept intended, and keeps the pack away from the charger's 0.81 W of heat [E3]. The pack, its BMS, its fuse and the charge path through the UPS are unchanged, so the safety case stands. |
| P2 | The vents were slots in the two end walls of the enclosure, which face the neighbouring terminal blocks and converter only 2 mm away, so almost no air could pass. | The same slots (two rows of 40 x 4 mm, low in the base and high in the cover, 42 mm apart vertically) move to the two long walls. | Same vent area (640 mm² low and high) and the same stack height, so the thermal results of TWK-CAL-001 stand. On a vertical cabinet plate the long walls face up and down, which makes the vents a chimney. A cautious check with the end walls counted as shielded gives 72.8 °C at light load, still 12.2 K below the assumed throttle point [F7]. |
| P3 | The computer floated 6 mm above the enclosure floor, and the HAT 16 mm above the computer, with nothing holding either. | Four 6 mm brass standoffs on four 2.7 mm floor holes (M2.5 screws from underneath), four 16 mm standoffs on top of them through the computer's holes, the HAT screwed on top, and a 2 x 20 header extender to carry the 40-pin header up to the HAT (new line 19). | The computer's own four-hole pattern (58 x 49 mm) carries both boards. The screw heads under the floor sit 4.75 mm outside the rail's flanges, clear of the DIN clip. The header extender sits between the standoffs with 1.1 mm to spare at each end. |
| P4 | The antenna bulkhead sat on top of the cover with no hole, and nothing connected it to the HAT. | A 6.5 mm hole in the cover, 30 mm left of the middle and 20 mm toward the back; the SMA bulkhead goes through it with its nut inside, and a U.FL pigtail runs to the HAT. | How an SMA bulkhead is fitted. The inside nut clears the HAT by about 22 mm. |
| P5 | No way for the network cable or the power and power-fail wires to enter the enclosure; the computer's network socket was inside a closed box, although R2 relies on Ethernet. | Two entries in the enclosure's front long wall, 26 mm above the floor: a round RJ45 feed-through coupler (20 mm hole) with a short patch lead to the computer, and an M16 gland with a two-hole insert for the USB-C power lead and the power-fail pair (new line 20). | A plug cannot pass through a sealing gland, so the network goes through a coupler. Both sit clear of the vents and of the boards (13.5 mm or more). On a cabinet plate the front wall faces down, so water cannot sit on the entries. |
| P6 | The DIN rail was drawn as a U channel lying on the plate, with no fixing. | A true TS35 x 7.5 top-hat section, 350 mm long, held to the plate by three M4 x 6 pan-head screws into tapped holes at the middle and 150 mm each side. | Every module's DIN clip needs the top-hat flanges to hook under. The screw heads sit 3.9 mm below the modules. |
| P7 | The modules stood on the rail with no clip and nothing stopped them sliding off its ends. | Each module's DIN clip is modelled (a hook under each flange), and two screw-clamped end stops (new line 18) press against the fuse holder and the battery box. | How DIN equipment is held. |
| P8 | The plate was "plywood or aluminium" with "4 screw holes", so the rail had nothing firm to screw into and the plate had nothing under it. | 6 mm aluminium sheet (line 1), three tapped M4 holes for the rail, four 5.5 mm corner holes for a wall or cabinet, and four stick-on rubber feet. | Tapped aluminium holds the rail without nuts underneath, so the plate can still lie flat on a wall. Plywood remains a saving worth trying (TWK-DEC-001, value engineering). |
| P9 | Power had no path from the converter to the computer, and the UPS power-fail signal had no path to the computer. | A 5 A USB-C power lead with bare ends from the converter's 5.1 V terminals to the computer, and a 0.25 mm² pair from the UPS power-fail contact to a free GPIO pin and ground, both through the power gland (line 21 and the wiring diagram in TWK-BLD-001). | Uses the computer's normal power socket. Without a power negotiation the computer limits its USB sockets to low power, which this gateway does not use. |

*Table 2. Knock-on changes.*

| Item | Change | Reason |
| --- | --- | --- |
| Rail | Modules take 331 mm (18.9 modules), 345 mm with end stops, on a 350 mm rail (was 294 mm on 320 mm) [H1]. R10 (350 mm, 20 modules) is still met. | Battery box and end stops added; UPS module narrowed from 4 to 3 modules. |
| Cost | BOM lines 1, 2, 3, 11 and 12 respecified (line 1 repriced from USD 6 to USD 15), lines 17 to 21 added. Value-engineering target: USD 300. Estimated cost of the constructable design: USD 334 (USD 34 over the target) [I1, I2]. | Parts added for construction. `budget_usd` is unchanged; savings worth trying are in TWK-DEC-001. |
| Thermal | Unchanged in the design case (69.1 °C at light load [F6]); new sensitivity [F7] with the end walls counted as shielded: 72.8 °C, 12.2 K margin. | Vents moved, same area and spacing. |
| Power and backup | Unchanged (6.41 W, 2.40 h). | No electrical part changed. |
| Drawings and media | TWK-DWG-001 Rev P3; making sketches TWK-DWG-101 to 105 added; concept media regenerated from the model. | Follows the model. |
| Documents | TWK-CAL-001 v0.3, TWK-REQ-001 v0.5, TWK-PRC-001 v0.5, `bom/bom-notes.md`. | Follows the model. |

## Consequences

- `design_state: constructable` in `project.yaml`. The build plan TWK-BLD-001 shows every component and step in pictures generated from the model (`cad/src/build_plan_media.py`).
- Requirement status: none not met, none at risk, 7 met by calculation, 7 met by design, 1 not verifiable at TRL 3 (R13), and R14 reported against its value-engineering target (USD 34 over).
- The photoreal renders (`media/render-hero.png`, `media/render-detail.png`), `media/card.png` and `media/social-preview.png` still show the concept: no end stops or battery box, vents in the end walls, the pack inside the UPS. They need regenerating on Amish's Mac, where Blender is.
- The enclosure, UPS module, pack and HAT are chosen when parts are bought; the items to confirm then are listed in TWK-DEC-001.

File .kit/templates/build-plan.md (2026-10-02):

---
doc_id: PRJ-BLD-001
title: Project prototype build plan
project: Project name
doc_type: Build plan
version: "0.1"
status: Draft
date: YYYY-MM-DD
author: Amish Chadha
license: CERN-OHL-S-2.0
revisions:
  - version: "0.1"
    date: YYYY-MM-DD
    author: Amish Chadha
    change: First build plan; design made constructable
---

# Project prototype build plan

**Plan, not yet built.** How to build the first proof-of-concept prototype, component by component. Building and testing to it is TRL 4 work. Decisions still to be made are kept in the design decisions register (`docs/06-design-decisions.md`), not here.

## 1. What you are building

Every component, pulled apart and numbered in build order

One short paragraph: what the prototype is, how many components, which are made and which are bought, and the main ways they are made.

## 2. What changed to make it buildable

| Component | The concept had | The buildable design has | Why |
| --- | --- | --- | --- |

## 3. Making the components

### 3.1 Component name

Making sketch

**What it is and what it is made from.**

**How to make it.**

1. Mark out ...
2. Cut ...

**How it fits the parts next to it.**

Close-up of the joint

**Check before moving on.**

## 4. Putting it together

### Step 1: ...

Step 1

## 5. First checks

| Check | Requirement | How | Pass when |
| --- | --- | --- | --- |

## 6. Safety stops

## 7. Tools, skills and workspace

## 8. Where the numbers come from

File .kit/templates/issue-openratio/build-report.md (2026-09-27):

---
name: Build report
about: Tell us what happened when you built, printed or tested part of this design
title: "Build report: "
labels: build-report
---

This is a research and educational prototype, not a medical device. It is a TRL 3 concept and is not released for fabrication. If you build any part of it, you do so at your own risk. Reports help everyone.

**What you built** (part, sub-assembly or test)

**Materials, tools and settings**

**What worked**

**What did not work, with photos or measurements if you have them**

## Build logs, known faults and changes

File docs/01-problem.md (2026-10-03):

---
doc_id: TWK-PRB-001
title: TwinKit problem statement
project: TwinKit
doc_type: Problem statement
version: "0.6"
status: Draft
date: '2026-10-02'
author: Amish Chadha
license: CERN-OHL-S-2.0
revisions:
- version: "0.1"
  date: '2026-09-25'
  author: Amish Chadha
  change: Initial scaffold
- version: "0.2"
  date: '2026-09-25'
  author: Amish Chadha
  change: Populate to TRL 2 (users, context, constraints, prior work)
- version: "0.3"
  date: '2026-09-25'
  author: Amish Chadha
  change: Record TRL 2 review items adopted for TRL 3 (TWK-DDR-001) and the items still open
- version: "0.4"
  date: '2026-09-25'
  author: Amish Chadha
  change: Recommendations accepted by Amish (DDR-002). Budget constraint raised to $300; open questions closed except the co-design partner
- version: "0.5"
  date: '2026-10-02'
  author: Amish Chadha
  change: Budget worded as a value-engineering target; cost of the constructable design (TWK-DDR-003)
- version: "0.6"
  date: '2026-10-02'
  author: Amish Chadha
  change: Co-design partner question answered by Amish's decision of 2026-10-02 (TWK-DEC-001)
---

# TwinKit problem statement

Digital twins are sold as enterprise software, out of reach for small builders, small utilities and cities, yet the core idea is simple: a model, live data and a comparison between them. There is no open, low-cost kit that lets a small team link the model and calculations it already has to readings from the field.

## The problem

A digital twin, in the sense introduced by Grieves and Vickers, pairs a physical system with a virtual model that is updated from the physical one, so that the two can be compared and deviations caught early ([Grieves and Vickers, 2017](https://link.springer.com/chapter/10.1007/978-3-319-38756-7_4)). Standards now describe the reference architecture for manufacturing twins ([ISO 23247-2:2021](https://www.iso.org/standard/78743.html); [NIST analysis of ISO 23247](https://www.nist.gov/publications/analysis-new-iso-23247-series-standards-digital-twin-framework-manufacturing)). In practice the capability is delivered through large vendor platforms and cloud subscriptions sized for large operators.

Small operators have the most to gain from early fault detection and the least access to it:

- Water utilities lose an estimated 126 billion m³ of treated water a year to leaks and unbilled use, worth nearly $40 billion ([World Bank, 2018](https://blogs.worldbank.org/en/ppps/what-do-private-companies-look-performance-based-non-revenue-water-project)). Kenya's utilities report a national average non-revenue water of 44 % ([WASREB Impact Report 17, 2025](https://wasreb.go.ke/wp-content/uploads/2025/06/IMPACT-REPORT-17.pdf)).
- About one in four handpumps in sub-Saharan Africa is non-functional at any time, roughly 175,000 water points in 2015 ([Foster et al., 2019, via IRC](https://www.ircwash.org/resources/functionality-handpump-water-supplies-review-data-sub-saharan-africa-and-asia-pacific)). Faults are found when people report them, not when the data shows them.
- Small and medium enterprises make up about 90 % of businesses and more than half of employment worldwide ([World Bank](https://www.worldbank.org/en/topic/smefinance)), yet enterprise twin platforms are priced for the largest firms.

Within the Design Molecule lab the same gap appears on a small scale. Every project has a build123d model and design calculations, and several (FieldNode, WaterWatch, PowerBox, the smart city nodes) will produce live readings. Nothing yet ties those readings back to the model and the calculation that predicted them, so the lab cannot show whether a design performs as calculated.

## Prior work

- **Open-source twin frameworks.** [Eclipse Ditto](https://eclipse.dev/ditto/) manages twin state for IoT devices through an API. It is powerful but assumes a server cluster and does not link to CAD or design calculations.
- **Open IoT stacks.** LoRaWAN network servers, MQTT brokers, time-series databases and dashboards are mature open-source tools and run on a single-board computer. They show data as charts, not against a model or an expected value.
- **City twins.** [Virtual Singapore](https://oecd-opsi.org/innovations/virtual-twin-singapore/) shows what a national 3D twin can do for planning, at a scale and cost no small city can match.

TwinKit's contribution is the thin layer between these: a mapping from each sensor channel to a part of the project's model and to the calculation that predicts its value, running offline on one small gateway.

## Users and context

| User | Need | Context |
| --- | --- | --- |
| Design Molecule lab (first user) | See each prototype's live readings on its model and against its design calculation | Lab bench and first field pilots |
| Small builder or maker team | A twin of their own device without a cloud contract | Workshop, garage, school lab |
| Small utility or facility operator | Early warning when a pump, tank, store or battery drifts from expected behavior | Village water scheme, clinic, small factory |
| City team (via CityTwin) | A gateway and data layer for street sensors | Municipal pilot |
| Students and researchers | An inspectable, reproducible twin pipeline to learn from and extend | University lab, makerspace |

## Constraints

- Garage-buildable prototype from off-the-shelf modules with no custom PCB. Value-engineering target for the parts: USD 300 (raised from USD 200 by Amish on 2026-09-25, TWK-DDR-002); a hypothetical control target, not a limit (Amish, 2026-10-01).
- Runs on one gateway with no internet connection and no vendor cloud account.
- Open licenses throughout: hardware CERN-OHL-S-2.0, TwinKit code MIT, and open-source third-party software.
- Low voltage only (12 V DC input).
- Monitoring only: TwinKit reads and compares; it does not control equipment.
- Secure by default, because an edge gateway on a network is an attack surface.

## Out of scope

- Closed-loop control or actuation of the monitored system.
- Physics simulation beyond the project's own calculations (TwinKit compares measured values with expected values; it does not run finite element or CFD models).
- Hosted cloud services. Upstream sync to a server the owner controls is optional.
- Camera or audio data.

## Open questions

- First example twin: FieldNode (battery state of charge against its power-budget calculation). Decided by Amish, 2026-09-25: go with recommendation (TWK-DDR-002).
- Radio: a full LoRaWAN concentrator rather than a point-to-point LoRa receiver. Decided by Amish, 2026-09-25: go with recommendation (TWK-DDR-002).
- Budget: decided by Amish, 2026-09-25: go with recommendation, `budget_usd` raised from $200 to $300 (TWK-DDR-002). Value-engineering target: USD 300. Estimated cost of the constructable design: USD 334 (USD 34 over the target; TWK-CAL-001 v0.3, TWK-DDR-003).
- Who outside the lab should co-design the operator view (a small water utility, a makerspace, a municipal team)? Decided by Amish, 2026-10-02 (TWK-DEC-001): the first candidate to approach is a small municipal water utility in the Dallas and Fort Worth area, found through the Texas Water Utilities Association, with Dallas Makerspace as the build and test partner; not yet approached.

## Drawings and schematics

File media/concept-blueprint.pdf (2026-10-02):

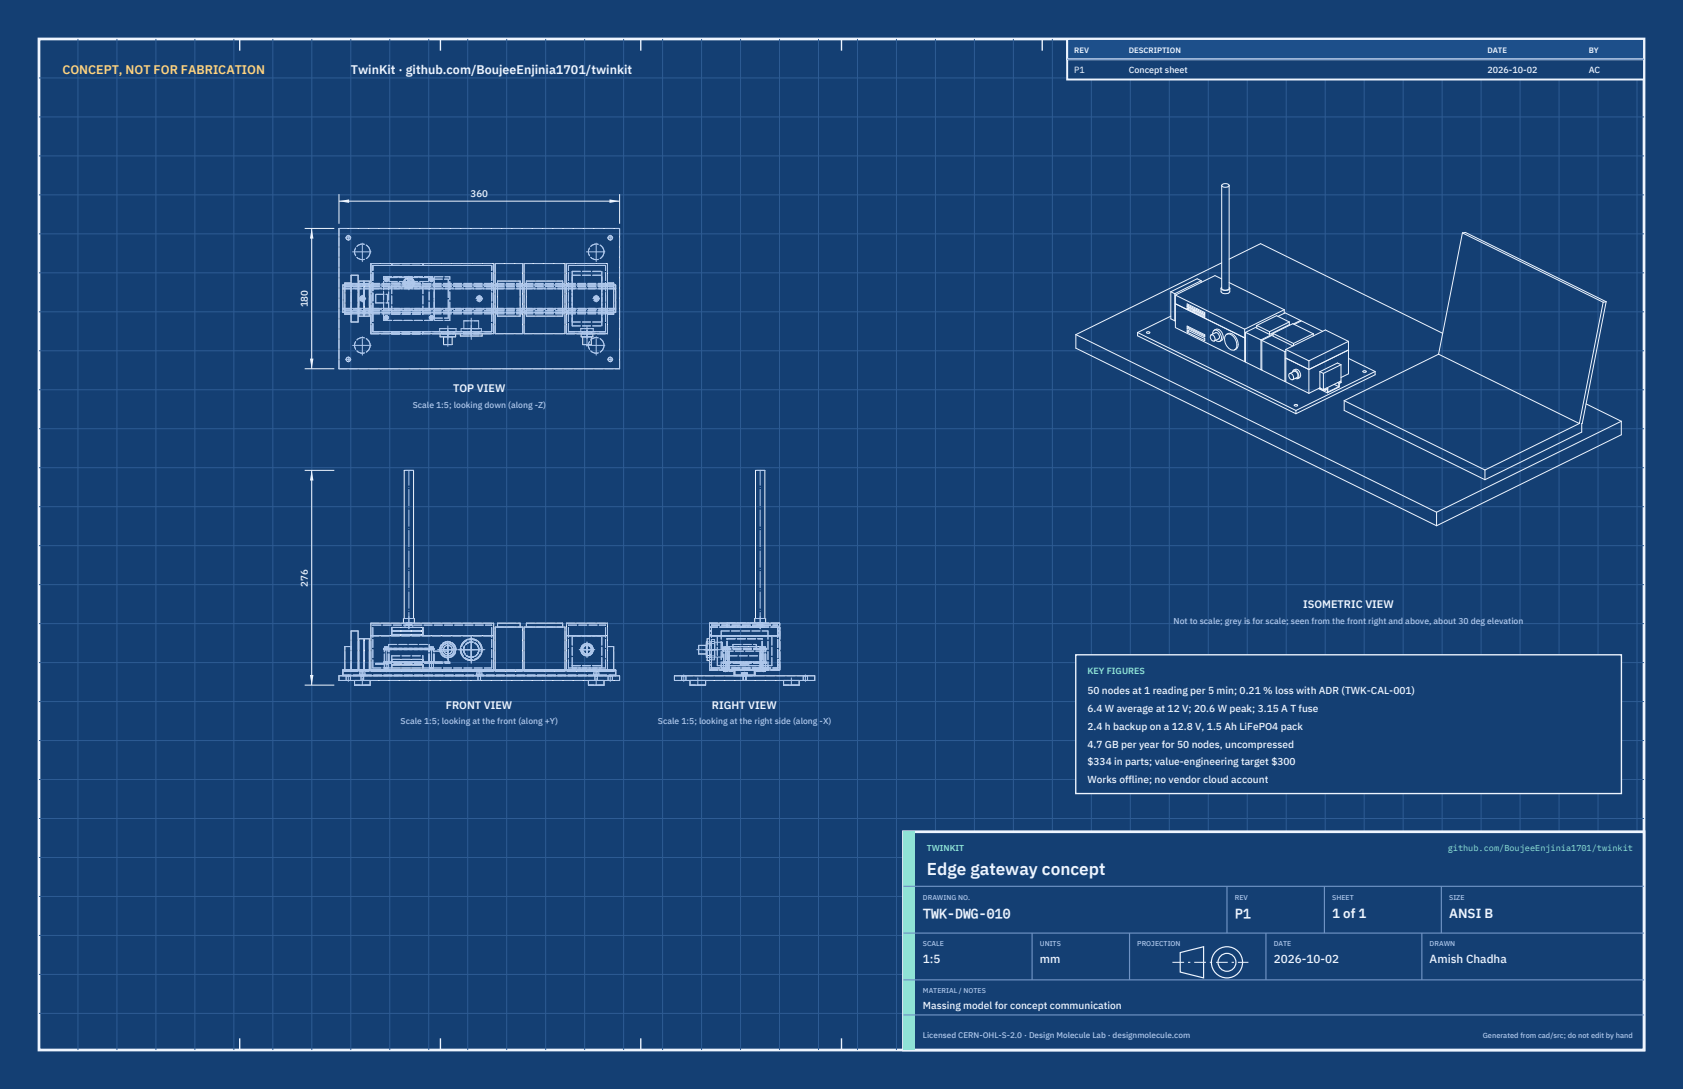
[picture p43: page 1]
CONCEPT, NOT FOR FABRICATION; TwinKit · github.com/BoujeeEnjinia1701/twinkit; FRONT VIEW; TOP VIEW; RIGHT VIEW; ISOMETRIC VIEW; REV; DESCRIPTION; DATE; Concept sheet; TWINKIT; github.com/BoujeeEnjinia1701/twinkit; DRAWING NO. TWK-DWG-010; REV P1; SHEET 1 of 1; SIZE ANSI B; SCALE 1:5; UNITS mm; PROJECTION; DRAWN Amish Chadha; Licensed CERN-OHL-S-2.0 · Design Molecule Lab · designmolecule.com; Generated from cad/src; do not edit by hand

Scale 1:5; looking down (along -Z)

Not to scale; grey is for scale; seen from the front right and above, about 30 deg elevation

KEY FIGURES
50 nodes at 1 reading per 5 min; 0.21 % loss with ADR (TWK-CAL-001)
6.4 W average at 12 V; 20.6 W peak; 3.15 A T fuse
2.4 h backup on a 12.8 V, 1.5 Ah LiFePO4 pack
4.7 GB per year for 50 nodes, uncompressed
$334 in parts; value-engineering target $300
Works offline; no vendor cloud account

Scale 1:5; looking at the front (along +Y)

Scale 1:5; looking at the right side (along -X)

Edge gateway concept

MATERIAL / NOTES
Massing model for concept communication

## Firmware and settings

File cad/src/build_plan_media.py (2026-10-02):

"""TwinKit prototype build plan pictures (TWK-BLD-001, STANDARDS section 18).

Run from the repo root:  python cad/src/build_plan_media.py [overview|sheets|layouts|joints|steps|wiring ...]
With no argument it draws everything. Every picture is drawn from cad/src/model.py
(build_parts and standoff_pieces), so the pictures and the model never disagree:
    docs/05-build-plan/overview.png        every component pulled apart, numbered in build order
    cad/drawings/TWK-DWG-101 to 105        making sketches for the made and drilled components
    docs/05-build-plan/plate-holes.png     hole layout of the bench plate
    docs/05-build-plan/enclosure-holes.png cut-outs in the enclosure base, cover and battery box
    docs/05-build-plan/joint-NN.png        close-ups of the joints that need explaining
    docs/05-build-plan/step-NN.png         one picture per assembly step
    docs/05-build-plan/wiring.png          block-level wiring with wire sizes (matplotlib)
Uses .kit/build_views.py. BUILD PLAN ILLUSTRATION, PLAN NOT YET BUILT.
"""
import sys
from pathlib import Path

ROOT = Path(__file__).resolve().parents[2]
sys.path[:0] = [str(ROOT / ".kit"), str(ROOT / "cad" / "src")]
import build_views as bv  # noqa: E402
from build_views import Part  # noqa: E402
from model import PARAMS as P, build_parts, derived, standoff_pieces, board_holes, box  # noqa: E402

OUT = ROOT / "docs" / "05-build-plan"
DWG = ROOT / "cad" / "drawings"
DATE = "2026-10-02"
D = derived(P)
C = build_parts(P)
SP = standoff_pieces(P)
Z0, T = P["rail"][2], P["enc_wall"]
XG, ED = P["x_gw"], P["enc_d"]

COL = {"plate": "#A8A29E", "feet": "#1F2937", "rail": "#9CA3AF", "screws": "#111827", "enc_base": "#D1D5DB",
       "enc_cover": "#7DD3C8", "entries": "#1F2937", "standoffs": "#B45309", "sbc": "#15803D", "sd": "#1F2937",
       "cooler": "#4B5563", "hat": "#0F766E", "header": "#7C3AED", "antenna": "#374151", "terminals": "#D4A017",
       "psu": "#6B7280", "ups": "#64748B", "box_base": "#D1D5DB", "pad": "#57534E", "pack": "#C2410C",
       "box_cover": "#7DD3C8", "stops": "#1E3A8A", "bolt": "#111827"}


def _fuse(shapes):
    out = None
    for s in shapes:
        out = s if out is None else out + s
    return out


def part(name, shape, color, explode=(0, 0, 0), alpha=1.0):
    return Part(name, shape, color, None, tuple(explode), alpha)


def mv(p, e):
    return Part(p.name, p.shape, p.color, None, tuple(e), p.alpha)


# ----------------------------------------------------------------- named parts, in build order
def made():
    return {
        "plate": part("Bench plate", C["plate"], COL["plate"]),
        "feet": part("Rubber feet (4)", C["feet"], COL["feet"]),
        "rail": part("DIN rail and 3 M4 screws", C["rail"] + C["rail_screws"], COL["rail"]),
        "enc_base": part("Enclosure base, cut and drilled", C["enc_base"], COL["enc_base"]),
        "entries": part("Network coupler and power gland", C["entries"], COL["entries"]),
        "lower": part("Lower standoffs (4) and screws", SP["lower"] + SP["heads_low"], COL["standoffs"]),
        "sbc": part("Computer with microSD card", C["sbc"] + C["sd"], COL["sbc"]),
        "cooler": part("Active cooler", C["cooler"], COL["cooler"]),
        "upper": part("Upper standoffs (4) and header extender", SP["upper"] + SP["header"], COL["header"]),
        "hat": part("Concentrator HAT and screws", C["hat"] + SP["heads_top"], COL["hat"]),
        "enc_cover": part("Enclosure cover, drilled", C["enc_cover"], COL["enc_cover"]),
        "antenna": part("Antenna and SMA bulkhead", C["antenna"], COL["antenna"]),
        "terminals": part("Terminal blocks and fuse holder", C["terminals"], COL["terminals"]),
        "psu": part("DC-DC converter", C["psu"], COL["psu"]),
        "ups": part("UPS module", C["ups"], COL["ups"]),
        "box_base": part("Battery box base and gland", C["box_base"] + C["box_gland"], COL["box_base"]),
        "pad": part("Hook-and-loop pad", C["pad"], COL["pad"]),
        "pack": part("Backup pack", C["pack"], COL["pack"]),
        "box_cover": part("Battery box cover", C["box_cover"], COL["box_cover"]),
        "stops": part("End stops (2)", C["stops"], COL["stops"]),
    }


ORDER = ["plate", "feet", "rail", "enc_base", "entries", "lower", "sbc", "cooler", "upper", "hat", "enc_cover",
         "antenna", "terminals", "psu", "ups", "box_base", "pad", "pack", "box_cover", "stops"]


# ----------------------------------------------------------------- overview
def overview():
    M = made()
    off = {"plate": (0, 0, -40), "feet": (0, 0, -120), "rail": (0, 0, 0), "enc_base": (0, 0, 60),
           "entries": (0, -120, 60), "lower": (0, 0, 130), "sbc": (0, 0, 175), "cooler": (0, 0, 220),
           "upper": (0, 0, 265), "hat": (0, 0, 310), "enc_cover": (0, 0, 370), "antenna": (0, 0, 440),
           "terminals": (-50, 0, 60), "psu": (20, 0, 60), "ups": (45, 0, 60), "box_base": (110, 0, 60),
           "pad": (110, 0, 150), "pack": (110, 0, 200), "box_cover": (110, 0, 290)}
    parts = []
    for k in ORDER[:-1]:
        p = M[k]
        p.explode = off[k]
        parts.append(p)
    # the two end stops are pulled out along the rail, each its own way
    import build123d as b
    left = C["stops"] & b.Pos(D["stop_l"], 0, 0) * b.Box(30, 200, 200)
    right = C["stops"] & b.Pos(D["stop_r"], 0, 0) * b.Box(30, 200, 200)
    parts.append(part("End stops (2)", b.Pos(-110, 0, 30) * left + b.Pos(150, 0, 30) * right, COL["stops"]))
    return bv.overview(parts, OUT / "overview.png", "TwinKit prototype: every component, pulled apart",
                       subtitle="Numbered in build order. Seen from the front right and above; the front is the side with the cable entries",
                       elev=22, azim=-62, size=(12, 8.5), dpi=150, key=True)


# ----------------------------------------------------------------- making sketches
def sheets():
    import build123d as b
    M = made()
    base = dict(project="TwinKit", date=DATE)
    out = []
    xr = D["x_rail"]
    pl = P["plate"]
    ins = P["plate_hole_inset"]

    # 101 bench plate
    out.append(bv.component_sheet(
        Part("Bench plate", C["plate"], COL["plate"]), [M["rail"], M["enc_base"], M["psu"], M["ups"], M["box_base"], M["terminals"]],
        dwg_no="TWK-DWG-101", title="TwinKit bench plate: making sketch", material="Aluminium sheet 6 mm, 5083, 6082 or 6061 class",
        view_shape=b.Pos(-xr, 0, 0) * C["plate"], inset_view=(30, -60),
        notes=["Blank 360 x 180 x 6 mm. Cut square, file the edges, round the",
               "  corners to about 3 mm. Scribe a centre line along the long side.",
               "Rail holes: three on the centre line, at the middle and 150 mm",
               "  each side of it. Drill 3.3 mm right through and tap M4.",
               f"Corner holes: four 5.5 mm holes, {ins:.0f} mm in from each long and short",
               "  edge, for screwing the plate to a wall or cabinet later.",
               "Deburr every hole on both faces.",
               "Underneath: four stick-on rubber feet, 20 mm across, centred",
               "  150 mm each side of the middle and 60 mm each side of the centre line.",
               "Fit: the rail lies on the centre line, held by three M4 x 6 mm",
               "  pan-head screws through its base into the tapped holes.",
               "Check: an M4 screw runs into each hole by hand; the plate rocks",
               "  on none of its feet on a flat bench."], **base))

    # 102 DIN rail
    rail = C["rail"]
    out.append(bv.component_sheet(
        Part("DIN rail", rail, COL["rail"]), [M["plate"]],
        dwg_no="TWK-DWG-102", title="TwinKit DIN rail: making sketch", material="TS35 x 7.5 top-hat rail, slotted, steel or aluminium",
        view_shape=b.Pos(-xr, 0, 0) * rail, inset_view=(35, -70),
        notes=["Cut a 350 mm length of TS35 x 7.5 slotted top-hat rail with a",
               "  hacksaw; file the cut ends square and remove every burr.",
               "The rail is 35 mm wide across its top flanges, 7.5 mm high, with",
               "  a 27 mm wide base that lies on the plate.",
               "Holes: three, on the rail's centre line, at the middle and 150 mm",
               "  each side. Where a slot already falls within 3 mm of a mark, use",
               "  the slot; otherwise drill 4.5 mm through the base.",
               "Fit: lay the rail on the plate's centre line, ends 5 mm in from the",
               "  plate's short edges. Three M4 x 6 mm pan-head screws, snug.",
               "Every module clips over the two top flanges; the screw heads sit",
               "  3.9 mm below the modules, so nothing rubs.",
               "Check: the rail lies flat along its length; a module clips on and",
               "  slides along it from end to end without catching on a screw."], **base))

    # 103 enclosure base
    eb = C["enc_base"]
    out.append(bv.component_sheet(
        Part("Enclosure base", eb, COL["enc_base"]), [M["rail"], M["entries"], M["lower"], M["sbc"], M["plate"]],
        dwg_no="TWK-DWG-103", title="TwinKit gateway enclosure base: cutting and drilling sketch",
        material="Bought 9-module DIN enclosure base, polycarbonate, 157.5 x 90 x 44 mm",
        view_shape=b.Pos(-XG, 0, -Z0) * eb, inset_view=(25, -60),
        notes=["The front is the long wall that will face you on the bench; the",
               "  antenna sits toward the back. Mark the front before cutting.",
               "Vent slots: two slots 40 x 4 mm in each long wall, centred 32 mm",
               "  left of the middle, 2.5 to 6.5 and 9.5 to 13.5 mm above the",
               "  outside of the floor. Chain drill 3.5 mm and file to the line.",
               "Front wall, 26 mm above the outside of the floor: a 20 mm hole",
               "  50 mm right of the middle (network coupler) and a 16.2 mm hole",
               "  20 mm right of the middle (power gland). Step drill, light pressure.",
               "Floor: four 2.7 mm holes for the computer: 58 mm apart along the",
               "  base and 49 mm apart across it, the left pair 59 mm and the right",
               "  pair 1 mm left of the middle. Use the maker's bosses if it has them.",
               "Tape the faces first; no solvents; deburr inside and out.",
               "Check: lay the computer on the floor; its holes line up with yours."], **base))

    # 104 enclosure cover
    ec = C["enc_cover"]
    out.append(bv.component_sheet(
        Part("Enclosure cover", ec, COL["enc_cover"]), [M["enc_base"], M["antenna"], M["hat"]],
        dwg_no="TWK-DWG-104", title="TwinKit gateway enclosure cover: drilling sketch",
        material="Bought cover for the 9-module enclosure, clear or tinted polycarbonate",
        view_shape=b.Pos(-XG, 0, -(Z0 + P["tray_h"])) * ec, inset_view=(35, -60),
        notes=["Antenna hole: 6.5 mm through the top, 30 mm left of the middle",
               "  and 20 mm behind the centre line (toward the back wall).",
               "  Pilot 3 mm, then step drill; check the size on the bulkhead's",
               "  datasheet before the last step.",
               "Vent slots: two slots 40 x 4 mm in each long wall, in line with the",
               "  base's slots, 1.5 to 5.5 and 6.5 to 10.5 mm above the cover's",
               "  lower edge. Skip any the maker has already moulded.",
               "Deburr; clean with water and mild soap only.",
               "Fit: the bulkhead goes in from above, flange and washer on the",
               "  outside, nut inside. The cover then closes onto the base with",
               "  the maker's clips or screws.",
               "Check: the bulkhead nut clears the concentrator HAT by 20 mm when",
               "  the cover is closed."], **base))

    # 105 battery box base
    bb_ = C["box_base"]
    out.append(bv.component_sheet(
        Part("Battery box base", bb_, COL["box_base"]), [M["rail"], M["pack"], M["pad"], M["ups"],
                                                         part("Gland", C["box_gland"], COL["entries"])],
        dwg_no="TWK-DWG-105", title="TwinKit battery box base: drilling sketch",
        material="Bought 3-module DIN enclosure base, polycarbonate, 52.5 x 90 x 44 mm",
        view_shape=b.Pos(-D["x_box"], 0, -Z0) * bb_, inset_view=(25, -60),
        notes=["One 12.2 mm hole in the front wall, on the middle of the wall,",
               "  26 mm above the outside of the floor, for the M12 gland that",
               "  the pack lead passes through. Pilot 3 mm, then step drill.",
               "Deburr inside and out.",
               "Inside: a hook-and-loop pad 38 x 60 mm stuck to the middle of the",
               "  floor; its mate goes on the pack's underside.",
               "The pack (38 x 70 x 38 mm at most) lies on the pad, long side",
               "  front to back, 3.5 mm clear of the gland nut.",
               "Fit: the gland goes in from outside, seal outside, nut inside.",
               "Check: the pack sits on the pad with its lead reaching the gland",
               "  without strain, and the cover closes without touching it."], **base))
    return out


# ----------------------------------------------------------------- joints
def _win(sh, x0, x1, y0, y1, z0, z1):
    import build123d as b
    return sh & (b.Pos((x0 + x1) / 2, (y0 + y1) / 2, (z0 + z1) / 2) * b.Box(x1 - x0, y1 - y0, z1 - z0))


def joints():
    out = []
    xr = D["x_rail"]
    # 01 rail on the plate, cut through the middle screw
    w = (xr - 25, xr + 0.01, -40, 40, -8, 12)
    out.append(bv.joint([
        part("Bench plate (tapped M4)", _win(C["plate"], *w), COL["plate"]),
        part("DIN rail base on the plate", _win(C["rail"], *w), COL["rail"]),
        part("M4 x 6 pan-head screw", _win(C["rail_screws"], *w), COL["bolt"])],
        OUT / "joint-01.png", "Joint 1: DIN rail on the bench plate (cut through the middle screw)",
        subtitle="Seen from the front right. The rail's base lies flat on the plate; the screw goes into a tapped hole",
        elev=25, azim=-35, size=(8, 6)))
    # 02 module clip on the rail, cut across the rail
    x0 = D["x_psu"]
    w = (x0 - 6, x0 + 0.01, -26, 26, -3, 14)
    out.append(bv.joint([
        part("Bench plate", _win(C["plate"], *w), COL["plate"]),
        part("DIN rail (top-hat section)", _win(C["rail"], *w), "#374151"),
        part("Module base with its clip hooks", _win(C["psu"], *w), "#93C5FD")],
        OUT / "joint-02.png", "Joint 2: how every module clips onto the rail (cut across the rail)",
        subtitle="Seen along the rail. A hook each side reaches under the rail's flange; the base sits on top of it",
        elev=6, azim=-6, size=(8, 6)))
    # 03 board stack at one corner, cut open
    hx, hy = board_holes(P)[1]
    w = (hx - 10, hx + 14, hy - 4, hy + 5, Z0 - 3, Z0 + 37)
    out.append(bv.joint([
        part("Enclosure floor", _win(C["enc_base"], *w), COL["enc_base"]),
        part("Lower standoff, 6 mm, screw from below", _win(SP["lower"] + SP["heads_low"], *w), COL["standoffs"]),
        part("Computer board", _win(C["sbc"], *w), COL["sbc"]),
        part("Upper standoff, 16 mm", _win(SP["upper"], *w), COL["header"]),
        part("Header extender", _win(SP["header"], *w), "#A78BFA"),
        part("Concentrator HAT, screw on top", _win(C["hat"] + SP["heads_top"], *w), COL["hat"])],
        OUT / "joint-03.png", "Joint 3: the board stack at one corner (enclosure cut away)",
        subtitle="Back left corner, seen from the front. Floor, 6 mm standoff, computer, 16 mm standoff, HAT; the header extender joins the boards",
        elev=14, azim=-72, size=(8, 6)))
    # 04 cable entries through the front wall, cut through their centres
    ze = Z0 + P["entry_z"]
    w = (XG + 5, XG + 70, -62, -20, ze - 25, ze + 0.01)
    out.append(bv.joint([
        part("Enclosure front wall", _win(C["enc_base"], *w), COL["enc_base"]),
        part("Network coupler: flange outside, nut inside", _win(C["entries"] & _right_of(XG + 35), *w), COL["entries"]),
        part("Power gland: dome outside, nut inside", _win(C["entries"] & _left_of(XG + 35), *w), "#475569")],
        OUT / "joint-04.png", "Joint 4: network coupler and power gland in the front wall (cut through their centres)",
        subtitle="Lower halves, seen from above and the front. Each clamps the wall between its outside flange and its inside nut",
        elev=50, azim=-70, size=(8, 6)))
    # 05 antenna bulkhead through the cover
    ax_, ay_ = D["bx"] - 10, 20
    zt = Z0 + P["enc_h"]
    w = (ax_ - 22, ax_ + 22, ay_ - 0.01, ay_ + 22, zt - 12, zt + 22)
    out.append(bv.joint([
        part("Enclosure cover top", _win(C["enc_cover"], *w), COL["enc_cover"]),
        part("SMA bulkhead, nut inside", _win(C["antenna"], *w), COL["antenna"])],
        OUT / "joint-05.png", "Joint 5: antenna bulkhead through the cover (cut through its centre)",
        subtitle="Back half, seen from the front. Flange and washer on top, nut underneath; the whip screws onto the top",
        elev=12, azim=-90, size=(8, 6)))
    # 06 pack in the battery box, cut in half along the rail
    xb = D["x_box"]
    w = (xb - 30, xb + 0.01, -70, 50, Z0 - 1, Z0 + 61)
    out.append(bv.joint([
        part("Battery box base", _win(C["box_base"], *w), COL["box_base"]),
        part("Hook-and-loop pad", _win(C["pad"], *w), COL["pad"]),
        part("Backup pack", _win(C["pack"], *w), COL["pack"]),
        part("M12 gland for the pack lead", _win(C["box_gland"], *w), COL["entries"]),
        part("Battery box cover", _win(C["box_cover"], *w), COL["box_cover"])],
        OUT / "joint-06.png", "Joint 6: backup pack in its battery box (box cut in half)",
        subtitle="Seen from the right. The pack sits on the pad, 3.5 mm clear of the gland nut and clear of the cover",
        elev=15, azim=-10, size=(8, 6)))
    # 07 end stop against the fuse holder
    xs = D["stop_l"]
    w = (xs - 10, xs + 30, -35, 35, -6, 60)
    out.append(bv.joint([
        part("Bench plate", _win(C["plate"], *w), COL["plate"]),
        part("DIN rail", _win(C["rail"], *w), COL["rail"]),
        part("End stop, screw-clamped to the rail", _win(C["stops"], *w), COL["stops"]),
        part("Fuse holder and terminal blocks", _win(C["terminals"], *w), COL["terminals"])],
        OUT / "joint-07.png", "Joint 7: left end stop pressed against the fuse holder",
        subtitle="Seen from the front left. The stop clamps to the rail touching the last module, so nothing can slide",
        elev=22, azim=-130, size=(8, 6)))
    return out


def _right_of(x):
    import build123d as b
    return b.Pos(x + 100, 0, 0) * b.Box(200, 400, 400)


def _left_of(x):
    import build123d as b
    return b.Pos(x - 100, 0, 0) * b.Box(200, 400, 400)
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

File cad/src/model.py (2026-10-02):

"""TwinKit parametric model (build123d), TRL 3, constructable design (TWK-DDR-003).

Run from the repo root:
    python cad/src/model.py            export STEP and STL into cad/step and cad/stl
    python cad/src/model.py --check    constructability checks (overlaps, contacts, clearances)
Exports:
    twinkit-assembly.step / .stl    bench plate, DIN rail and every gateway module, with fixings
    gateway-enclosure.step / .stl   9-module enclosure with the computer, cooler, HAT, card and antenna

Axes: X along the TS35 DIN rail, Y across it, Z up, with the top of the bench plate at z = 0.
The same layout fits a vertical cabinet back plate (then -Y is down, so the cable entries face
down and the vents in the two long walls form a chimney); the bench case is the worst case for
natural ventilation. Every part can be bought, or made with a saw, drill, tap and file:
see docs/05-build-plan.md (TWK-BLD-001). The same PARAMS feed docs/04-calcs/sizing.py
(TWK-CAL-001), the drawing TWK-DWG-001 (cad/src/sheets.py) and the build plan pictures
(cad/src/build_plan_media.py).
"""
import sys
from pathlib import Path

# Top-level parameters (mm). Edit these, not the geometry below.
PARAMS = {
    "module": 17.5,                     # DIN module pitch
    "rail": (350.0, 35.0, 7.5),         # 2 TS35 x 7.5 top-hat rail: length, width, height
    "rail_t": 1.0,                      # rail sheet thickness
    "rail_web": 27.0,                   # width of the rail's base (the part screwed to the plate)
    "rail_screw_dx": (-150.0, 0.0, 150.0),   # M4 rail screws, from the rail centre
    "plate": (360.0, 180.0, 6.0),       # 1 bench plate, aluminium
    "plate_hole_inset": 12.0,           # 5.5 mm corner holes for wall or cabinet mounting
    "feet": (20.0, 6.0, 150.0, 60.0),   # rubber feet: diameter, height, x and y from the plate centre
    "gap": 2.0,                         # clearance between modules on the rail
    "clip": (2.0, 2.0, 1.0),            # DIN clip hook under each module: hook width, lip reach, lip thickness
    # 3, 4 gateway enclosure: modules, depth across the rail (Y), height above the rail (Z)
    "enc_modules": 9, "enc_d": 90.0, "enc_h": 60.0, "enc_wall": 2.5, "tray_h": 44.0,
    # vents: slots in both LONG walls (+Y and -Y), low row in the base and high row in the cover
    "vent_slot": (40.0, 4.0), "vent_rows_low": 2, "vent_rows_high": 2,
    "vent_z_low": 8.0, "vent_z_high": 50.0,          # slot centres above the rail top
    "vent_dx": -32.0,                                # slot centre along X from the enclosure centre
    # 5 computer (85 x 56 board), 6 cooler, 7 HAT, 8 card
    "sbc": (85.0, 56.0, 1.6), "sbc_standoff": 6.0, "cooler": (40.0, 40.0, 8.0),
    "hat": (65.0, 56.0, 1.6), "hat_standoff": 16.0,
    "sbc_holes": (58.0, 49.0, 3.5),     # board mounting holes: spacing along X and Y, inset from the corner
    "standoff_d": 5.0, "hole_m25": 2.7,
    "header": (50.8, 5.0),              # 2 x 20 header extender footprint
    # 9 antenna whip on an SMA bulkhead through the cover: whip length and diameter
    "antenna": (190.0, 12.0), "sma_hole": 6.5,
    # cable entries in the -Y long wall of the gateway enclosure base
    "rj45": (20.0, 28.0, 50.0),         # feed-through coupler: hole, flange diameter, x from the enclosure centre
    "gland": (16.2, 20.0, 20.0),        # M16 cable gland with a two-hole insert: hole, flange diameter, x from the enclosure centre
    "box_gland": (12.2, 15.0),          # M12 cable gland for the pack lead: hole, flange diameter
    "entry_z": 26.0,                    # entry centres above the rail top
    # 10 DC-DC converter, 11 UPS module, 17 battery box with the 12 LiFePO4 pack inside it
    "psu_modules": 2, "ups_modules": 3, "box_modules": 3,
    "pack": (38.0, 70.0, 38.0), "pad_t": 3.0,
    # 13 terminal blocks (2 x 6.2 mm) and fuse holder (9 mm), 18 end stops
    "tb_w": 6.2, "fuse_w": 9.0, "tb_h": 40.0, "fuse_h": 50.0,
    "stop": (8.0, 40.0, 30.0),
    "x_gw": -40.0,                      # enclosure centre along the rail
}


def derived(p=PARAMS):
    """Dimensions the calc note, drawings and build plan quote, computed from PARAMS."""
    m = p["module"]
    enc_w = p["enc_modules"] * m
    rail_l, rail_w, rail_h = p["rail"]
    ups_w, box_w = p["ups_modules"] * m, p["box_modules"] * m
    x_psu = p["x_gw"] + enc_w / 2 + p["gap"] + p["psu_modules"] * m / 2
    x_ups = x_psu + p["psu_modules"] * m / 2 + p["gap"] + ups_w / 2
    x_box = x_ups + ups_w / 2 + p["gap"] + box_w / 2
    x_tb0 = p["x_gw"] - enc_w / 2 - p["gap"]              # right edge of the terminal group
    tb_len = 2 * p["tb_w"] + p["fuse_w"] + 2 * p["gap"]
    tb_left = x_tb0 - 2 * p["tb_w"] - p["gap"] - p["fuse_w"]   # left face of the fuse holder
    rail_right = x_box + box_w / 2
    used_l = rail_right - (x_tb0 - tb_len)
    sw, sh = p["vent_slot"]
    vents = sw * sh * 2                                      # both long walls, one row
    d, h = p["enc_d"], p["enc_h"]
    stop_l = tb_left - p["stop"][0] / 2
    stop_r = rail_right + p["stop"][0] / 2
    x_rail = ((stop_l - p["stop"][0] / 2) + (stop_r + p["stop"][0] / 2)) / 2
    return {
        "enc_w": enc_w, "x_psu": x_psu, "x_ups": x_ups, "x_box": x_box, "ups_w": ups_w, "box_w": box_w,
        "x_tb0": x_tb0, "tb_len": tb_len, "tb_left": tb_left,
        "rail_used_mm": used_l, "rail_used_modules": used_l / m,
        "rail_left": x_tb0 - tb_len, "rail_right": rail_right,
        "stop_l": stop_l, "stop_r": stop_r, "x_rail": x_rail,
        "rail_occupied_mm": (stop_r + p["stop"][0] / 2) - (stop_l - p["stop"][0] / 2),
        "vent_low_mm2": vents * p["vent_rows_low"], "vent_high_mm2": vents * p["vent_rows_high"],
        "vent_stack_mm": p["vent_z_high"] - p["vent_z_low"],
        # enclosure outer area without the face that sits on the rail
        "enc_area_m2": (2 * (enc_w * d + enc_w * h + d * h) - enc_w * d) / 1e6,
        # the same without the two end walls, which face the neighbouring modules 2 mm away
        "enc_area_shielded_m2": (2 * (enc_w * d + enc_w * h) - enc_w * d) / 1e6,
        "enc_top_z": rail_h + h,
        "antenna_top_z": rail_h + h + 6 + p["antenna"][0],
        "rail_z": rail_h,
        "bx": p["x_gw"] - 20,           # board centre along X
    }


def _b():
    import build123d as b
    return b


def box(cx, cy, z0, sx, sy, sz):
    """Box with its base at z0."""
    b = _b()
    return b.Pos(cx, cy, z0 + sz / 2) * b.Box(sx, sy, sz)


def zcyl(x, y, z0, r, h):
    b = _b()
    return b.Pos(x, y, z0 + h / 2) * b.Cylinder(r, h)


def ycyl(x, y0, z, r, h):
    """Cylinder along Y from y0 to y0 + h (h may be negative)."""
    b = _b()
    lo = min(y0, y0 + h)
    return b.Pos(x, lo + abs(h) / 2, z) * b.Rot(90, 0, 0) * b.Cylinder(r, abs(h))
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

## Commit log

2026-09-25 Initial scaffold: standard open hardware layout, CERN-OHL-S v2 + MIT licenses
    Claude-Session: https://claude.ai/code/session_01XuhhSU4W6fYhgCfURbrkut
    [bom.csv]
2026-09-25 Populate to TRL 2: problem, requirements, precis, concept media, BOM and README use cases
    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
    [bom.csv]
2026-09-26 Advance to TRL 3: DDR-001, CAL-001 sizing, parametric model with STEP/STL, GA drawing, priced BOM; TRL 4 on hold
    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
    [bom.csv, gateway-enclosure.step, gateway-enclosure.stl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]
2026-09-26 Accept all recommendations (DDR-002), switch footer to designmolecule.com, add README write-up with new inspiration point
    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
    [bom.csv, gateway-enclosure.step, twinkit-assembly.step]
2026-10-01 Image quality pass: legible exploded views, flow diagrams and drawing sheets
    Kit 1.6.1 image layout: the parts list sits in its own column, number bubbles sit on visible parts and never overlap, small parts get a leader, pictures are cropped to the subject, flow labels keep numbers with their units, and sheet captions and the revision table no longer overprint. Concept images, blueprint and general arrangement sheet regenerated; repo-specific labels moved clear of other text and lines.
    [sheets.py]
2026-10-02 Kit 1.7.0: constructable design, illustrated build plan and design decisions register
    The design is now constructable: every part can be made and fits its neighbours, with each change recorded in a Design for construction decision record (made under Amish's 2026-09-30 instruction; ope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
    FlexHand also credits Dr. Geeti Chadha as a contribut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
    [bom.csv, gateway-enclosure.step, gateway-enclosure.stl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]
2026-10-03 Carry approved follow-ups into the design and redo photoreal renders
    Amish approved the follow-up actions from the open-decision sign-off ("APPROVED CHANGES, COMPLETE THESE", 2026-10-02), the design-for-construction change tables in ten repos, the last wave's open dec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
    [bom.csv]
